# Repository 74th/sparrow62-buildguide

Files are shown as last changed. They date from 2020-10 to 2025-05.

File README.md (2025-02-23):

# Sparrow Series DIY Keyboard Kit Build Guide

Sparrow シリーズ自作キーボードキットビルドガイド

- Sparrow62 v1: [./sparrow62_v1.md](./sparrow62_v1.md) 分割型カラムスタッカードキーボード
- Sparrow62 v2: [./sparrow62_v2.md](./sparrow62_v2.md) 分割型カラムスタッカードキーボード(2023)
- Sparrow60C: [./Sparrow60c.md](./Sparrow60c.md) ジョイスティックモジュール StickPointV 搭載、GH60 互換ケース用 60% 格子配列キーボード
- SparrowDial: [./SparrowDial.md](./SparrowDial.md) M5StackCore2、M5Dial をトラックパッド化する GH60 互換ケース用 60% 格子配列キーボード
- SparrowG24: [./SparrowG21.md](./SparrowG21.md) レバーレス GP2040 ゲームコントローラ。ジョイスティック付き。
- SparrowS v3: [./SparrowS_v3.md](./SparrowS_v3.md) 分割型カラムスタッカードキーボード(2025)

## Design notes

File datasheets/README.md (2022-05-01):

# データシート

- [v2.0.4 ~ 2.0.5 回路図 datasheets/sparrow62-v2.0.5-schematic.pdf](./sparrow62-v2.0.5-schematic.pdf)
- [v2.0.4 ~ 2.0.5 配線 datasheets/sparrow62-v2.0.5-pcb.pdf](./sparrow62-v2.0.5-pcb.pdf)

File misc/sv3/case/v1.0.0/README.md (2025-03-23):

# SparrowS v3 ケースデータ v1.0.0

- 左手ボディMX互換スイッチ用: [./left-case-main-mx.stl](./left-case-main-mx.stl)
- 左手ボディChoc互換スイッチ用: [./left-case-main-choc.stl](./left-case-main-choc.stl)
- 左手トップバー奥用: [./left-case-top-upper.stl](./left-case-top-upper.stl)
- 左手トップバー手前用: [./left-case-top-lower.stl](./left-case-top-lower.stl)
- 右手ボディMX互換スイッチ用: [./right-case-main-mx.stl](./right-case-main-mx.stl)
- 右手ボディChoc互換スイッチ用: [./right-case-main-choc.stl](./right-case-main-choc.stl)
- 右手トップバー奥用: [./right-case-top-upper.stl](./right-case-top-upper.stl)
- 右手トップバー手前用: [./right-case-top-lower.stl](./right-case-top-lower.stl)

下記のインサートナットを利用しています。

- 長さ 3mm, M2, 外形(OD) 3.2mm
  - https://ja.aliexpress.com/item/1005006262109427.html

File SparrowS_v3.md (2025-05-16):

# SparrowS v3 ビルドガイド

本記事中に、[右手追加4キーパッドの組み立て方法](#右手追加4キーパッドの使用方法)も記載があります。

## 販売先

- booth: https://74th.booth.pm/items/6655442

## SparrowS v3 の注意点

- 互換スイッチと、Chocスイッチに対応ですが、Chocスイッチを利用する場合、実装しては"いけない"部品があります（後の手順中でも説明します）。MX互換の場合でも、実装しなくても問題ありません。
  - 左手PCB:
    - CH9（上面の、TopPlateLEDと書かれたQwiicソケット）
  - 左手トッププレート:
    - 全て（キャパシタ C1、Qwiicソケット CH1、RGBLED D1）
- Qwiicソケットは実装が難しめの部品になります。実装しなくてもキーボードとして全ての機能を利用できます。実装に必要な機材がなかったり、実装に自信がない場合はひとまず実装せずに進めてください。
  - 左手PCB: CH9、CH10
  - 左手トッププレート: CH1
  - 右手PCB: CH3
  - 右手トッププレート: -
  - 推奨機材: フラックス、ブリッジをチェックするためのテスター
- ケースはMX互換スイッチとChocスイッチの使用時で異なるものを用意しています。対応ケースをご準備ください。MX互換スイッチ用ケースではChocスイッチでも使用可能ですが、高さが適切ではありません。
- 拡張用にI2C Qwiicソケットを搭載しています。しかし、現状販売中のケースは右手のみにしか対応しません。必要に応じて利用してください。

## SparrowS v3キーボードとは

SparrowS v3は@74thが頒布する自作キーボードキットです。

最初は Lily58 からインスピレーションを得て、数々の改良を加えました。

これは購入者がご自身で組み立てが必要なキットです。
完成を保証するものではありません。

本キーボードの前作はSparrow62(+1)v2です。左右分割（スプリット）タイプのキーボードシリーズとして、SparrowSと改名し、SparrowS v3となっています。

## SparrowS v3の特徴

- 左右分割で、方を開いてタイプできる
- 縦に揃ったキー配置（カラムスタッガード）であり、指の曲げ伸ばしで多くのキーに届くようになっている
- 右手のキーボードの右側にマウスなどを配置できるように、右手の右側のキーの数を抑え、左側が膨らむデザインである
- 右手のキーボードの左側にトラックパッドなどを配置できるように、右手の左側が削れている
- ガスケットマウントを採用し、打鍵感を和らげている
- CherryMX互換スイッチと、薄型のKailh Chocスイッチに対応
- スイッチソケットにより、スイッチの交換が可能
- 数字キーを網羅できるほどキーの数が多いこと（60%キーボード）。
- 標準的なキーキャップセットを利用して、組み立てが可能
- ゴム足の代わりに、ゴムシートを使うことで薄くしている

## キット同梱品

### ベースキット

- 左手用PCB x1
- 右手用PCB x1
- 左手用トッププレート x1
- 右手用トッププレート x1
- 左手用ケース（MXスイッチ用、Chocスイッチ用のどちらか） x1
- 左手用ケースヘッダーバー奥用 x1
- 左手用ケースヘッダーバー手前用 x1
- 右手用ケース（MXスイッチ用、Chocスイッチ用のどちらか） x1
- 右手用ケースヘッダーバー奥用 x1
- 右手用ケースヘッダーバー手前用 x1
- ダイオード 1N4148W x58
- SK6812-MINI-E x1
- TRRSソケット x2
- SMD 0603in 1608M 27Ω 抵抗 x1
- SMD 0603in 1608M 100nF コンデンサ x1
- SH1.0(Qwiic)ソケット x2
- SH1.0(Qwiic)ケーブル x1
- ガスケットマウントクッション x2.5
- M2 4mmネジ x19
- グリップクッション x4片

使用している市販品の購入先については、後述しております。

### 追加4キーパッド

- PCB x1
- トッププレート x1
- ケース x1
- M2 4mmネジ x5
- グリップクッション x1片
- Qwiic互換ケーブル x1

## 追加で必要なもの

### ベースキット

- スイッチソケット（以下のどちらか） x58
  - Cherry MX互換ソケット（Kailh製で確認済み）
    - 遊舎工房: https://shop.yushakobo.jp/products/a01ps
    - TALP KEYBOARD: https://talpkeyboard.net/items/5e02c5405b120c792616bcf9
  - Kailh Chocソケット
    - 遊舎工房: https://shop.yushakobo.jp/products/a01ps
    - TALP KEYBOARD: https://talpkeyboard.net/items/6365b6224ff8c216413a0c92
- スイッチ（以下の種類のもの） x58
  - Cherry MX互換スイッチ
  - Kailh Choc v1/v2スイッチ（Lofree x Kailh Shaddowシリーズも可）
- スイッチ対応キーキャップ一式（[『対応キーキャップ』の項目](#対応キーキャップ)を参照ください）
- TRRSケーブル x1
- USB-Cケーブル x1

### 追加4キーパッド

- スイッチ（以下の種類のもの） x3
  - Cherry MX互換スイッチ
  - Kailh Choc v1/v2スイッチ（Lofree x Kailh Shaddowシリーズも可）
- スイッチ対応キーキャップ 4種
  - MX互換スイッチの場合
    - 2U x1 - バックスペースキー
    - 2.25U x1 - Enterキー
    - 2.75U x1 - 左Shiftキー
    - 1.25U x1
  - Chocの場合
    - 1U x3
    - 1.25U x1 - 1Uでも可
- (MX互換スイッチのみ) 2U スタビライザー x3
- スイッチソケット（以下のどちらか） x4
  - Cherry MX互換ソケット（Kailh製で確認済み）
  - Kailh Chocソケット

### 使用可能なスタビライザー

(MX互換スイッチのみ) 2U スタビライザー x3が必要です。
自作キーボードで用いられるスタビライザーには、「プレートマウントスタビライザー」と「PCBマウントスタビライザー」があります。
「PCBマウントスタビライザー」を利用してください。

- 遊舎工房: [MXスイッチ スタビライザー https://shop.yushakobo.jp/products/a0500st](https://shop.yushakobo.jp/products/a0500st)
- TalpKeyboard: [DUROCK 2U V3 PCBマウントスタビライザー（スモーキー/ゴールド） https://talpkeyboard.net/items/66793a80b90fcc082dad12f2](https://talpkeyboard.net/items/66793a80b90fcc082dad12f2)

Chocの場合にはスタビライザーは使用できません。

### 追加4キーパッドを利用する場合

## 対応キーキャップ

以下のセットを含むキーキャップを利用してください。

### CherryMX互換スイッチを使う場合

以下の画像中の`1.5u`の表記を参考に、サイズの合うキーキャップを利用してください。（右手の左側4キーは追加4キーパッドのものです）

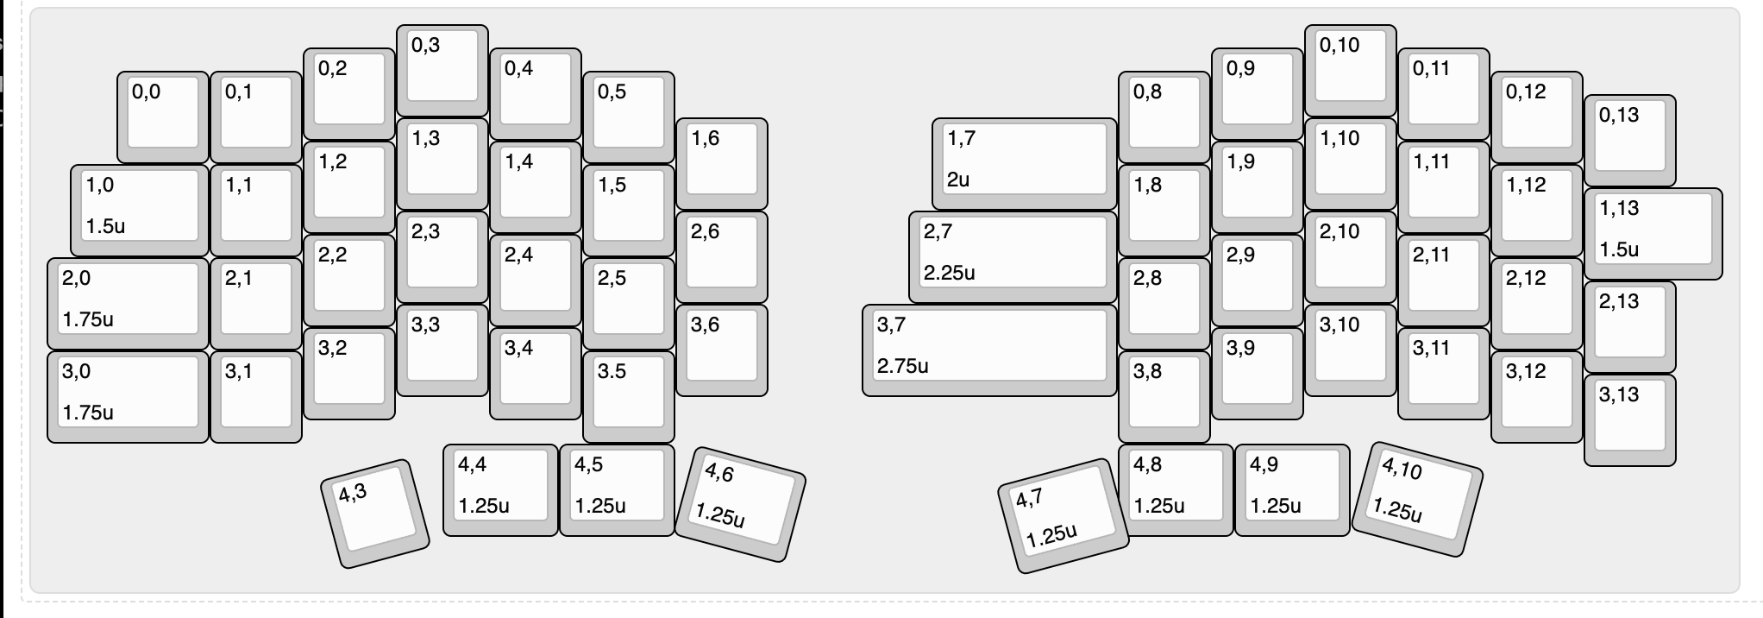
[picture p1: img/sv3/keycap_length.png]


主に、以下の点に注意してください。

- 最下段の1.25uが6つあること
- 左手シフト用に1.75uのShiftがあること

### Kailh Chocスイッチを使う場合

以下の点に注意してください。

- 左手の左端、および右手の右端はすべて1uを使います
- 右手の追加4キーパッドも1uを使うように設計されています
- 最下段には1.25uが6つあります

## 実装手順

### 1. ダイオードの実装

ダイオードの実装は以下のページをみてください。

[ダイオード1N4148Wの実装方法 ./diode_1n4148w.md](./diode_1n4148w.md)

### 2. スイッチソケットの実装

スイッチソケットの実装は以下のページをみてください。

[スイッチソケットの実装方法 ./switch_socket.md](./switch_socket.md)

### 3. CherryMXソケットのみ、トッププレートLEDの実装

> [!Caution]
> Kailh Chocスイッチを使う場合はトッププレートLEDのための部品は実装してはいけません

CherryMX互換スイッチを使う場合のみ、この実装を行ってください。
Chocスイッチ利用時は、実装してしまうとスイッチが取り付けられなくなります。
トッププレートLEDがなくても、PCB中のLEDが見えるため問題ありません。

トッププレートと、PCBのQwiicソケットを実装します。

QwiicソケットをPCBにマスキングテープで固定します。

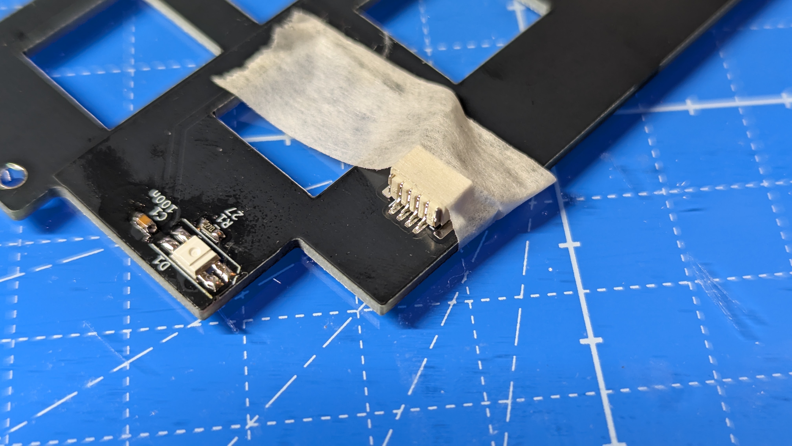
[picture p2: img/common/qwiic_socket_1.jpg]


固定した上で、ブリッジするのを気にせずに実装します。

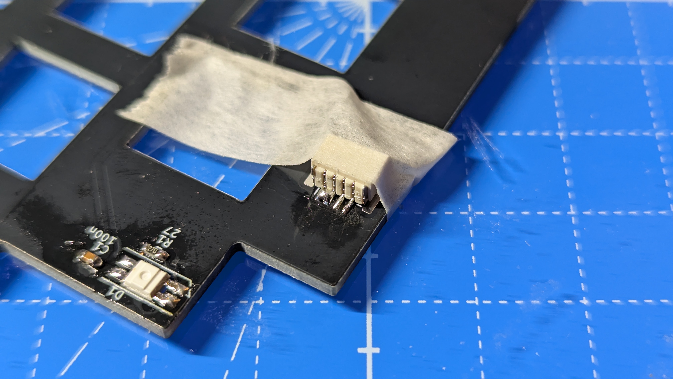
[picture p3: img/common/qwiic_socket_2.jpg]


フラックスを塗り、はんだごてを当ててブリッジした余分なはんだをはんだごてに移し、はんだごてを拭います。
これを繰り返し、余分なはんだを取り除きブリッジを除去します。

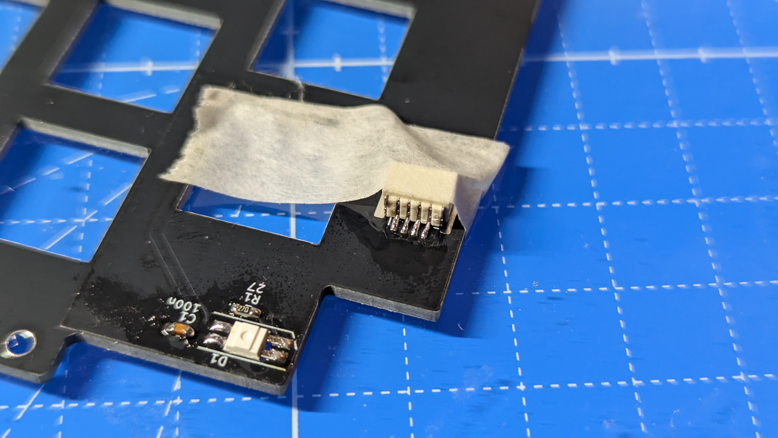
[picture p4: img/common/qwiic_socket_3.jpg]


次に本体固定のためのランドを実装します。
まず、PCB上のランドを温めて、はんだを流してください。
この時、無理にソケットの金属部分まで温めようとしなくて大丈夫です。

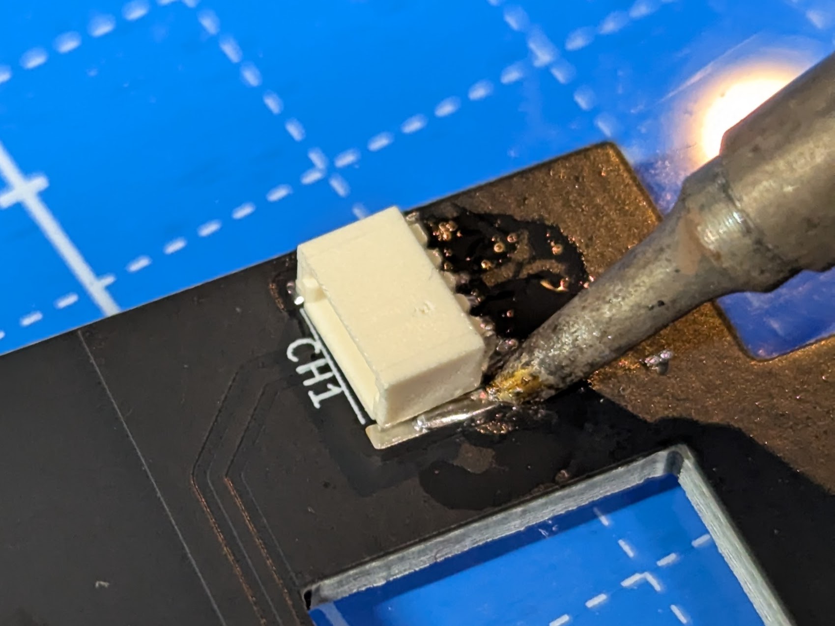
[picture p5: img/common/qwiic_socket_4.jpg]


次にソケットの金属部分を温めてください。
すると、次第に隣接しているランドに熱が伝わり、ソケットの金属部分にまではんだが流れ込み、はんだで溶接されます。

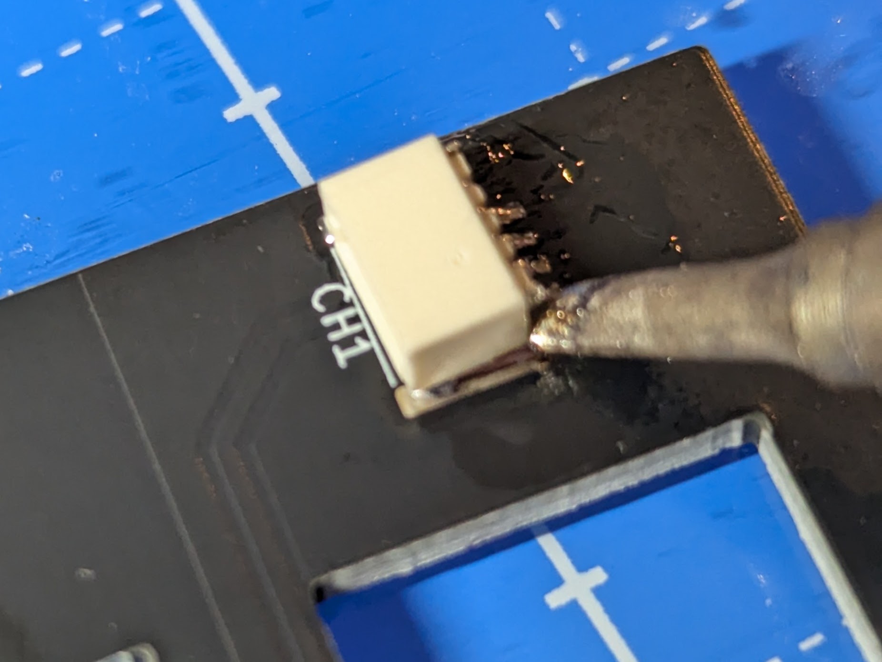
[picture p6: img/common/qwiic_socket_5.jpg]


次にSK6812-MINI-Eを実装します。
LED SK6812MINI-E の方向を注意してください。

LED の実装は、PCB裏面に裏向き（LEDのない面）にセットして実装します。
PCB 表向きから見ると、発光面が見える形になります。

また、LED の 4 本の足の 1 つ GND には切れ込みが入っています。切れ込みとシルクの斜め線を合わせるようにしてください。（写真はSparrow62v2(+1)のものです）

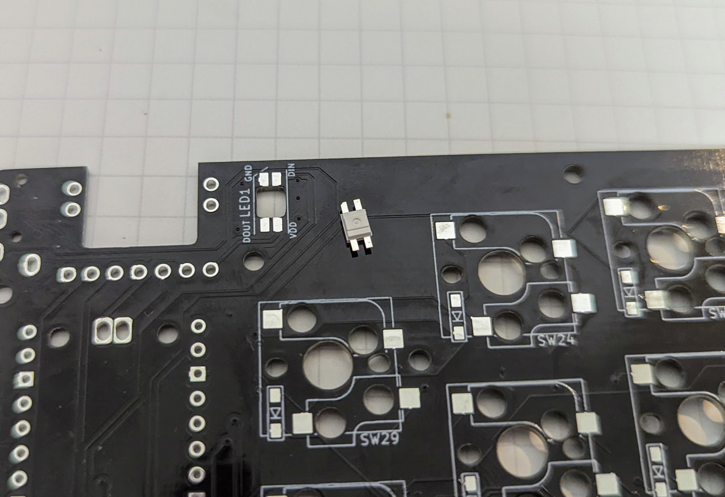
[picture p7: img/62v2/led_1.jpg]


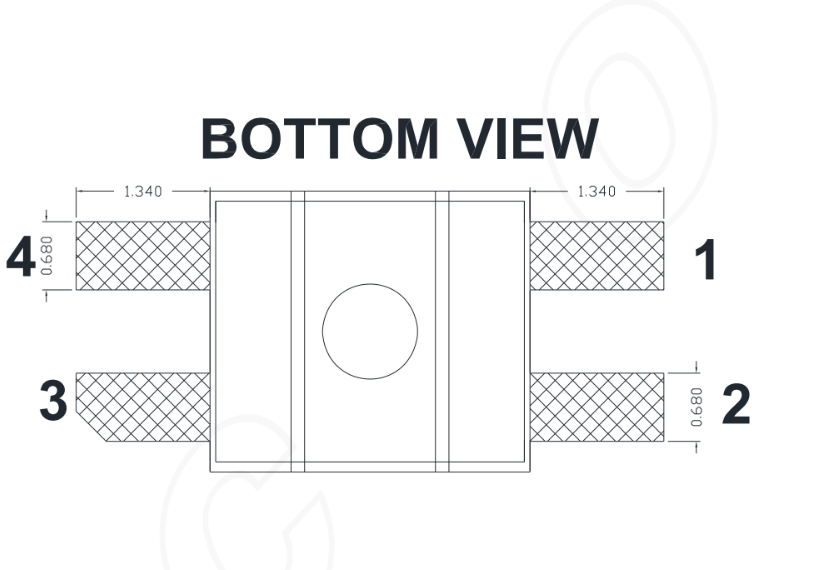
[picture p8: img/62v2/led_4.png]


向きを確認できたら、一方の足をマスキングテープで留めます。

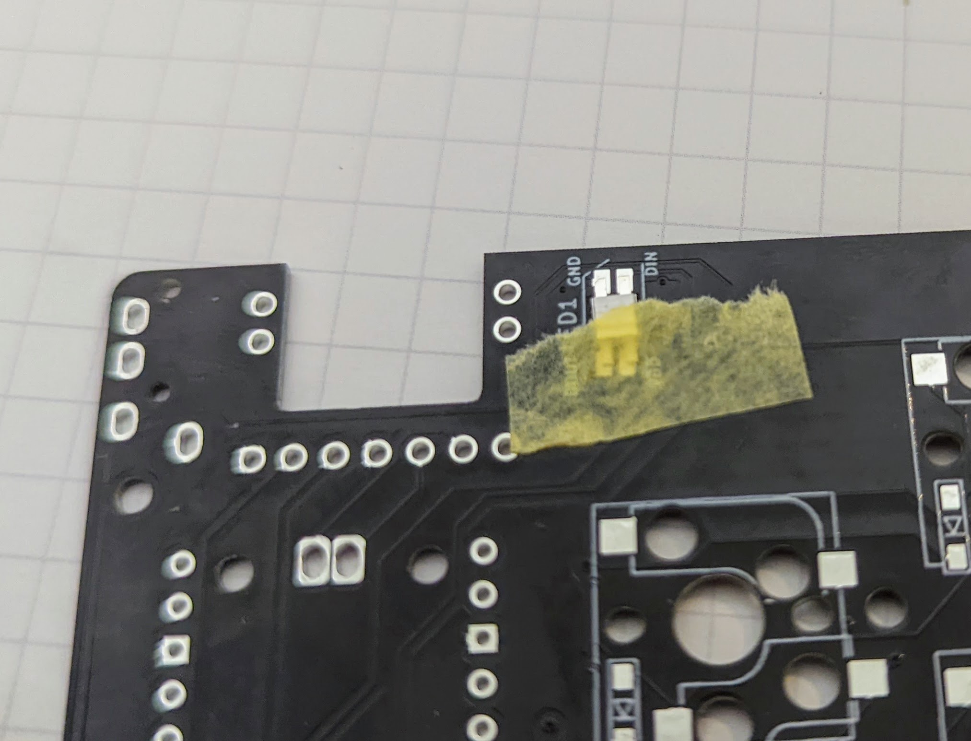
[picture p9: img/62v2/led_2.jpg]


すべての足を実装します。

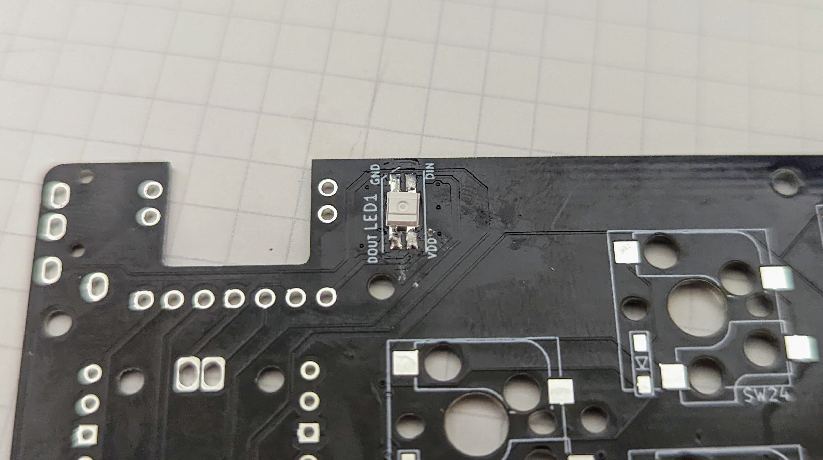
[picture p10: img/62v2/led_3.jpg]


C1に100nFコンデンサ、R1に27Ω抵抗を、ダイオードと同じように実装します。

### 4. TRRSソケットの実装

まず、TRRSソケットをPCB上にセットし、マスキングテープで固定します。

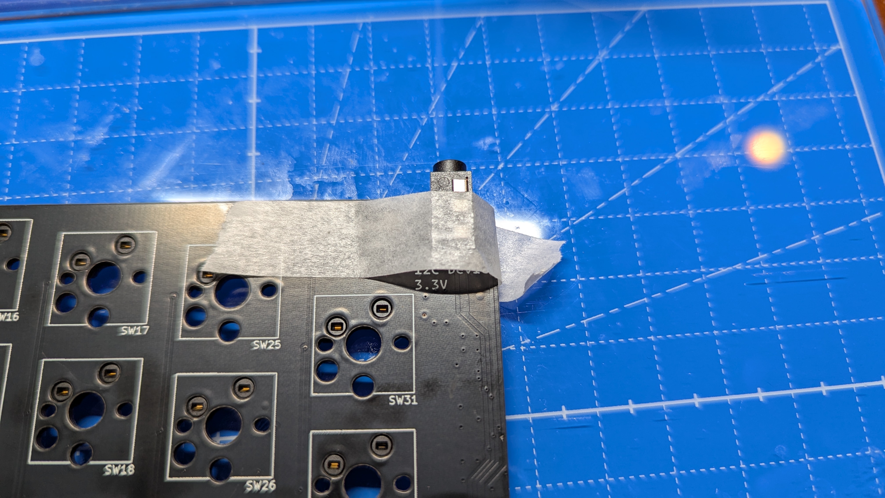
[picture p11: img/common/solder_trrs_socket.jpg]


裏返し、TRRSソケットのはみ出ている足をニッパで切ります。
それからはんだ実装してください。

### 5. スイッチの取り付けとここまでの実装確認

ここまでの実装を、確認しましょう。
ケースに入れる前に確認しましょう。

SparrowS v3には、Remapに対応したQMK Firmwareを予め書き込んであります。
PCとUSBで接続するとキーボードとして認識します。

PCBにトッププレートPCBを重ねて、トッププレート越しにスイッチを差し込みます。
トッププレートとPCBはネジ止めしません。

Chocスイッチ、MXスイッチにはプレートが挟まるツメがあります。
Chocスイッチの場合、トッププレートとPCBの間は以下の写真のように0.5mm程度になります。
スイッチのツメにしっかりはまるように取り付けてください。

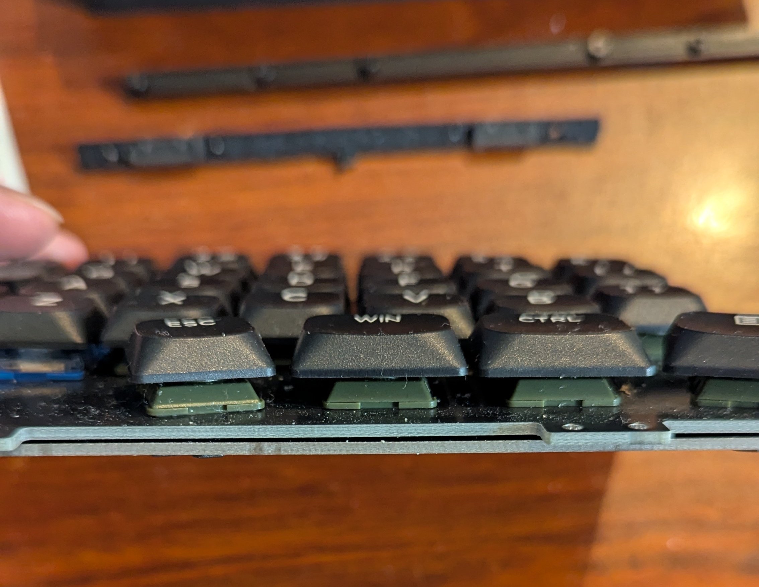
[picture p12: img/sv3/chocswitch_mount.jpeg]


MX互換スイッチには、トッププレートを挟み込む溝が付いています。この溝にトッププレートが挟まれるようにトッププレートを持ち上げてください。

TRRSソケットにケーブルを差し込み、接続します。

USBをPCに接続し、すべてのキーが動作するかを確認します。詳細は前述の「ケースへの組み込み前の実装確認」を確認ください。

各キーが動作することをRemapのTest Matrix modeを使って確認して下さい。

> RemapのTest Matrix modeを使ったキーマトリックスのテスト方法
>
> [./remap_test_matrix_mode.md](./remap_test_matrix_mode.md)

動作しないキーがある場合、一度すべてをケースから取り外し、該当キーのダイオードとスイッチソケットの実装をやり直します。

### 6. ケースのバリ取り

ケースは家庭用3Dプリンタで製造したものをキットに同梱しています。
プリムという印刷を安定化させる部分も含んだ状態で出荷しています。

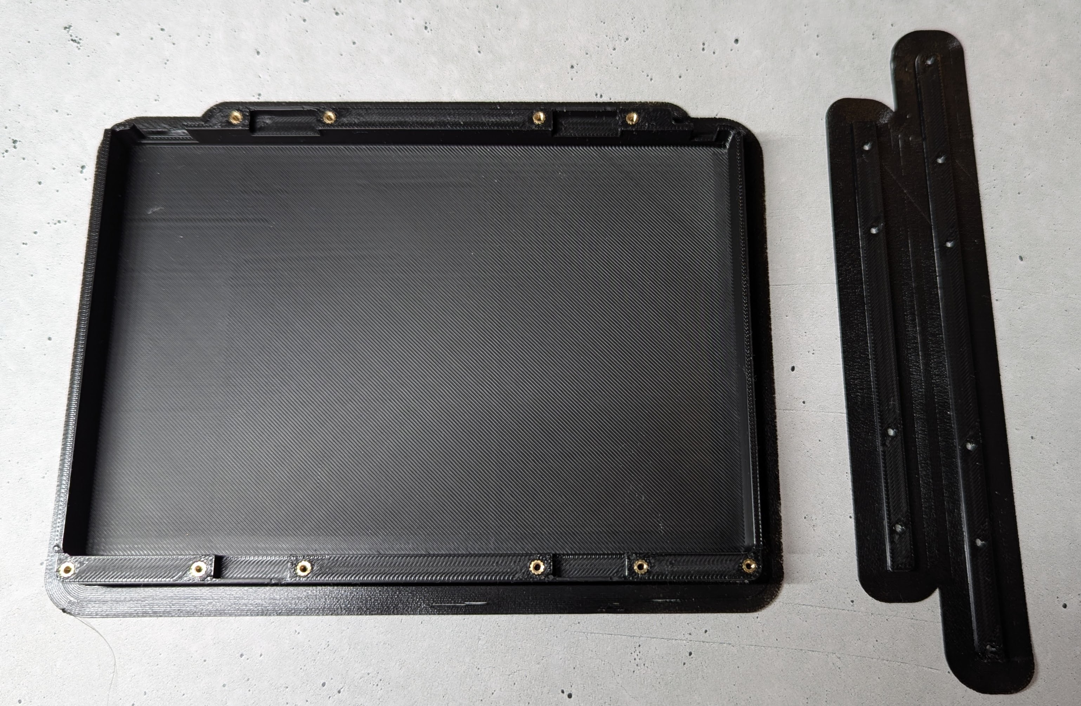
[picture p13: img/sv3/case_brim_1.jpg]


カッターナイフでブリムの部分を切り取ります。
カッターナイフとしては、デザインナイフを使うと、細くて使いやすいです。
怪我しないように気をつけてください。

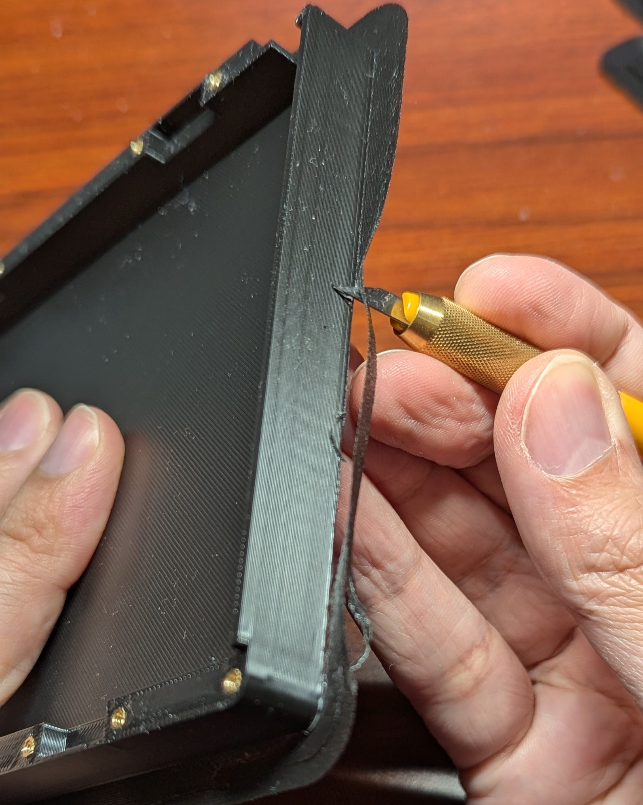
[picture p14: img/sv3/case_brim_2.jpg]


### 7. ガスケットクッションの取り付け

ガスケットマウントのクッションを、はさみで6つに切り分けます。

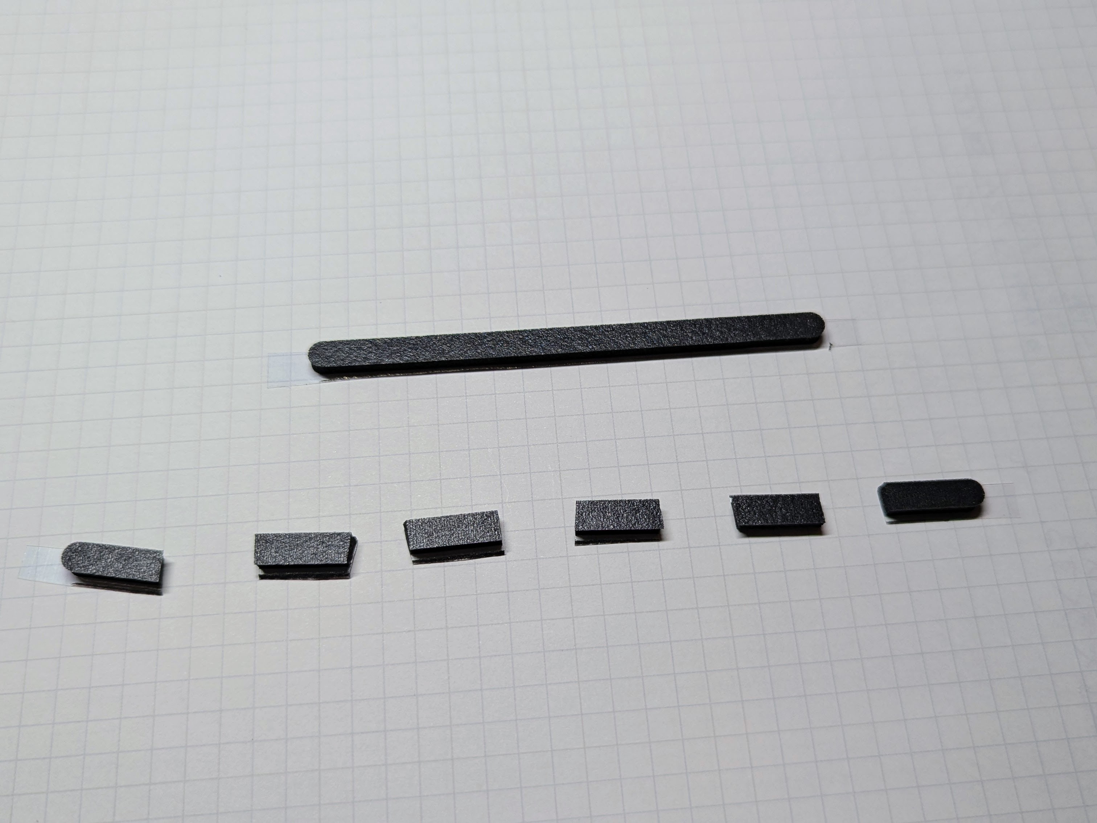
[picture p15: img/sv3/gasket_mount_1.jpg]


ケースと、ケースのバーに、クッションをそれぞれ取り付けます。

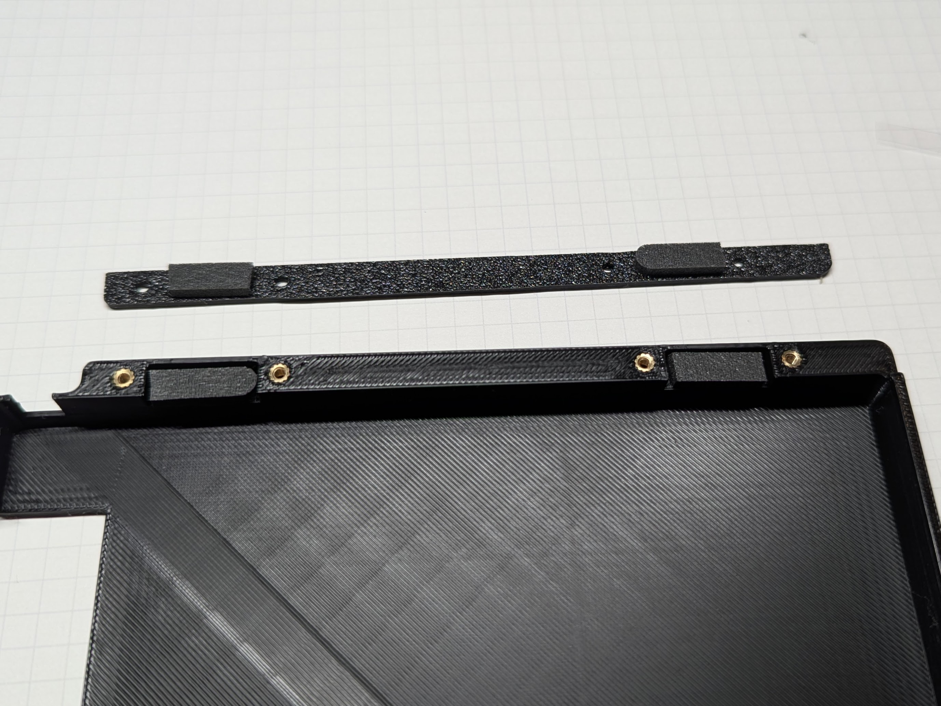
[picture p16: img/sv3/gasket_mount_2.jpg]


合計16箇所とりつけてください。

### 8. ネジ止め

キーボードPCBを入れて、ネジで留めます。

### 9. 底面のグリップゴムとりつけ

グリップゴムは4片付属しています。まず、こちらをはさみで半分に切ります。

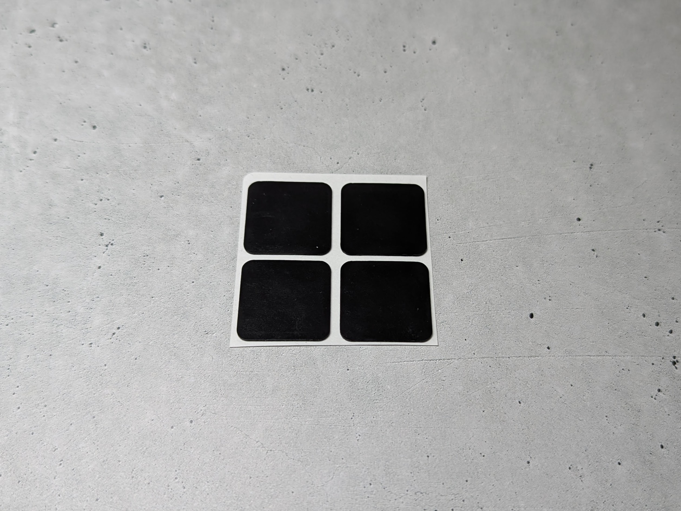
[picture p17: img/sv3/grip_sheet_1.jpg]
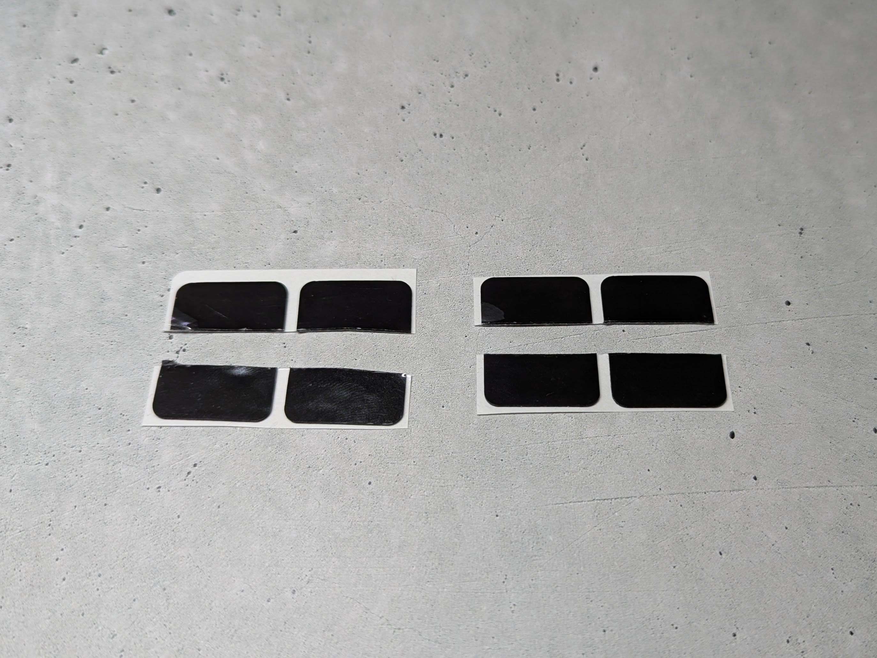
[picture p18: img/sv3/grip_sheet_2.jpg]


これをケースの底面の四隅に貼り付けます。

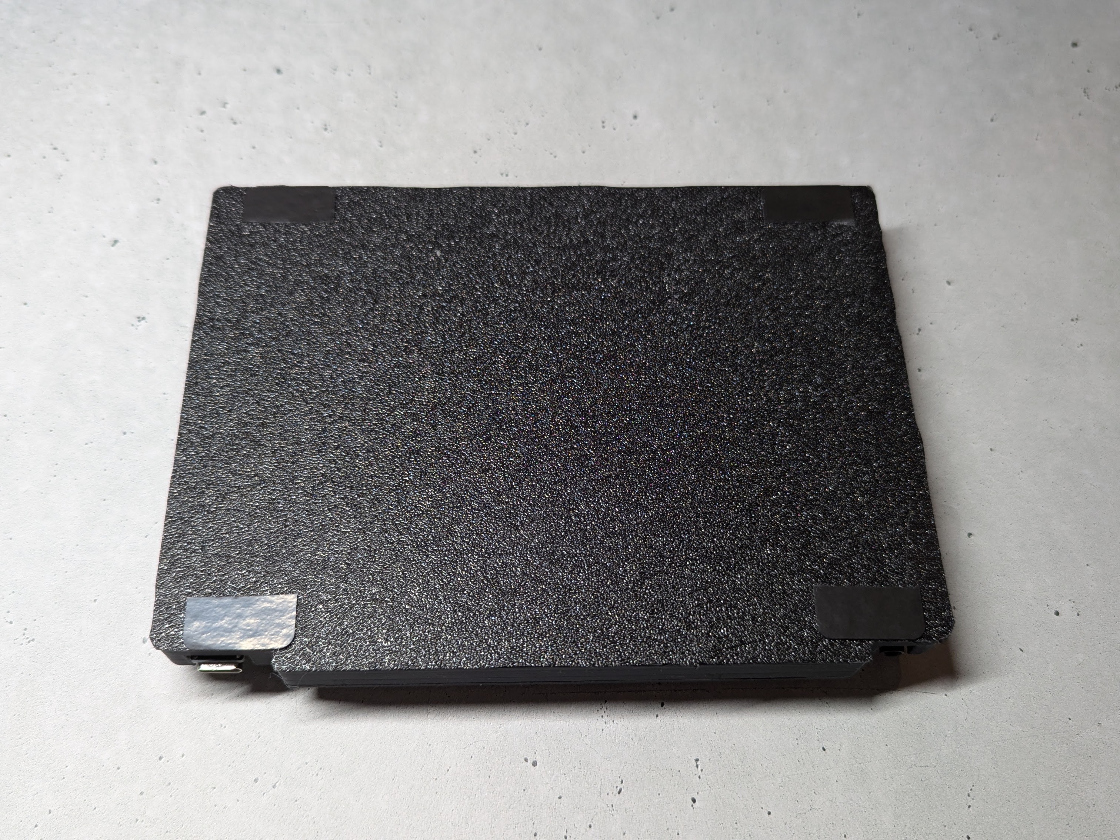
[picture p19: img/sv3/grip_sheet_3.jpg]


これで完成です！

## キーマップの変更、RP2040ファームウェアの更新

キーマップの変更には、2種類の方法があります。

- VIA、Remapを用いる
- QMK Firmwareでファームウェアをビルドする
- RP2040に対応したファームウェアを作成する

始めからVIA、Remap用のファームウェアが書き込まれた状態になっています。Remapを用いる場合には特にこの工程をする必要はありません。

VIA、Remapを利用しない利用しない場合は、別途ファームウェアを用意してください。RP2040はBOOTSELボタンを押しながらRESETを行うと、USBマスストレージデバイスがPCに認識され、その中にuf2ファイルをドラッグドロップすることで、ファームウェアを書き込むことができます。

### VIA、Remapを利用する場合

VIA、RemapはWebサイトや、ツール上からキーマップの書き換えができるサイトです。VIA対応のファームウェアをRP2040にアップロードすると、利用できるようになります。最初からRemap用のファームウェアが書き込まれた状態で出荷しています。

- Remap https://remap-keys.app/
- VIA https://caniusevia.com/

ファームウェアは以下からダウンロードできます。

> [!IMPORTANT]
> 追加4キーパッド対応版は、追加4キーパッドを使用する場合のみ書き込んでください

- VIA、Remap 用ファームウェア 通常版 [./firmware/sv3/qmk_firmware-sparrows_v3-via.uf2](https://github.com/74th/sparrow62-buildguide/raw/refs/heads/master/firmware/sv3/qmk_firmware-sparrows_v3-via.uf2)
- VIA、Remap 用ファームウェア 右手追加4キーパッド対応版 [./firmware/sv3/qmk_firmware-sparrows_v3_with_4keyspad-via.uf2](https://github.com/74th/sparrow62-buildguide/raw/refs/heads/master/firmware/sv3/qmk_firmware-sparrows_v3_with_4keyspad-via.uf2)

書き込みを行う領域の都合上、新たにVIA、REMAPのファームウェアをインストールしても、以前変更したキーマップの変更が残っている場合があります。その時には、[公式サイトのResetting Flash memory](https://www.raspberrypi.com/documentation/microcontrollers/raspberry-pi-pico.html#resetting-flash-memory)にあるUF2ファイル(flash_nuke.uf2)を一度インストールして、FLASHの全消去を行ってください。

また、書き込み直後は右手や、追加4キーが動作しない場合があります。一度USBを抜き差しして電源をリセットさせてください。

初期キーマップはRemapの画面もしくは、QMK Firmware上の以下のコードを確認ください。

[https://github.com/74th/qmk_firmware_sparrow_keyboard/blob/sparrow/keyboards/sparrow62/rev3/keymaps/via/keymap.c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](https://github.com/74th/qmk_firmware_sparrow_keyboard/blob/sparrow/keyboards/sparrow62/rev3/keymaps/via/keymap.c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)

### QMK Firmwareでファームウェアをビルドする場合

現在、SparrowDialキーボードはQMK Firmwareの本体には取り込まれていません。下記リポジトリに作成したファームウェアのコードがあります。
SparrowSという名前ですが、Sparrow62からのバージョン3であるため、[keyboards/sparrow62/rev3](https://github.com/74th/qmk_firmware_sparrow_keyboard/tree/sparrow/keyboards/sparrow62/rev3)というディレクトリ構成になっています。

- リポジトリ: https://github.com/74th/qmk_firmware_sparrow_keyboard
- キーボードディレクトリ: https://github.com/74th/qmk_firmware_sparrow_keyboard/tree/sparrow/keyboards/sparrow62/rev3

QMK Firmwareの環境のセットアップについては[公式のドキュメント https://docs.qmk.fm/#/newbs_getting_started](https://docs.qmk.fm/#/newbs_getting_started)を確認ください。[日本語のドキュメント https://docs.qmk.fm/#/ja/newbs_getting_started](https://docs.qmk.fm/#/ja/newbs_getting_started)もあります

まず、リポジトリをチェックアウトしてください。QMK Firmwareのフォークとなっているため、QMK Firmwareのセットアップでチェックアウトされたgitリポジトリのremoteとして登録できます。

```sh
cd ~/qmk_firmware
git remote add sparrow https://github.com/74th/qmk_firmware_sparrow_keyboard.git
git fetch sparrow
git checkout sparrow
```

このリポジトリ上では、キーボード名`sparrow62/rev3`として登録されています。新しいキーマップを作成するには以下を実行します。

```
qmk new-keymap -kb sparrow62/rev3 -km <keymap_name>
```

`~/qmk_firmware/keyboards/sparrowdial/keymaps/<keymap_name>`というフォルダに作成されるため、キーマップを作成します。

右手追加4キーを利用する場合には、`~/ghq/github.com/qmk/qmk_firmware/keyboards/sparrow62/rev3/config.h`を開き、`USE_RIGHT_4KEYS`の値を`1`に設定します。

```
// 右手左側の追加4キーオプション使用時は1にする
#define USE_RIGHT_4KEYS 1
```

キーマップ作成後は、以下のコマンドでコンパイルします。

```
qmk compile -kb sparrow62/rev3 -km <keymap_name>
```

すると、`~/qmk_firmware/.build/sparrows_rev3_<keymap_name>.uf2`にビルドされるため、これをRP2040に書き込みます。

RP2040に書き込むには、BOOTSELモードでRP2040を起動する必要があります。
左手PCBのUSBを「BOOT」ボタンを押しながらPCに接続するか、PCに接続済みの場合「BOOT」ボタンを押しながら「RESET」ボタンを押してください。
PC上にRPI-RP2という名前のUSBドライブが認識します。
その中に .uf2 ファイルをドラッグドロップしてください。
ファイルが入ると、自動的にUSBドライブのマウントが解除され、RP2040が再起動します。

## 右手追加4キーパッドの使用方法

右手に4キーを追加するモジュールを作成しております。
こちらを、右手のQwiicソケット（SH1.0-4P）に、Qwiicケーブル（キットには互換ケーブルを付属）を接続して、右手に4キーを増設することができます。

### キット同梱品

[前述の『キット同梱品』を確認ください。](#追加4キーパッド)

### キットの他に必要な物

[前述の『キットの他に必要なもの』を確認ください。](#追加4キーパッド-1)

### 組み立て

まずスイッチソケットを実装してください。
スイッチソケットの実装は以下のページをみてください。

[スイッチソケットの実装方法 ./switch_socket.md](./switch_socket.md)

グリップクッションをはさみで4分割し、ケースの底面の4隅にグリップクッションを貼り付けてください。

組み立てには以下の順に行ってください。

#### 1. CherryMX互換の場合、PCBにスタビライザーを取り付ける

スタビライザーをPCBに取り付けます。
スタビライザーには、手前奥の方向があります。
一般的なスタビライザーはバーが手前になるように取り付けます。

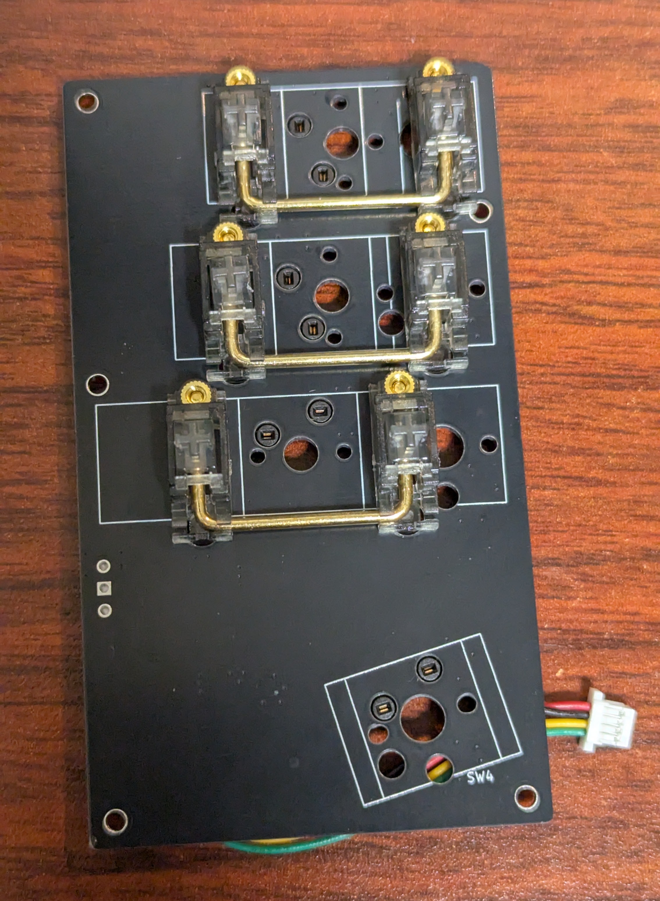
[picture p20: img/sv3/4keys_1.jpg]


横から眺めて、スタビライザーが確実に接地していることを確認してください。
ネジ止めするタイプのスタビライザーの場合、少し浮いている状態でも取り付けられることがありますが、キーキャップが嵌まらなかったり、嵌まったとしても正しく押下できないことがあります。

#### 2. Qwiicソケットにケーブルを接続

QwiicソケットにQwiic(SH1.0-4P)ケーブルを接続してください。
本キットには互換ケーブルが付属しています。

右手キーボードへ取り付ける時に、ケーブルが邪魔にならないように、以下の写真の程度の長さになるようにマスキングテープなどで留めておきましょう。

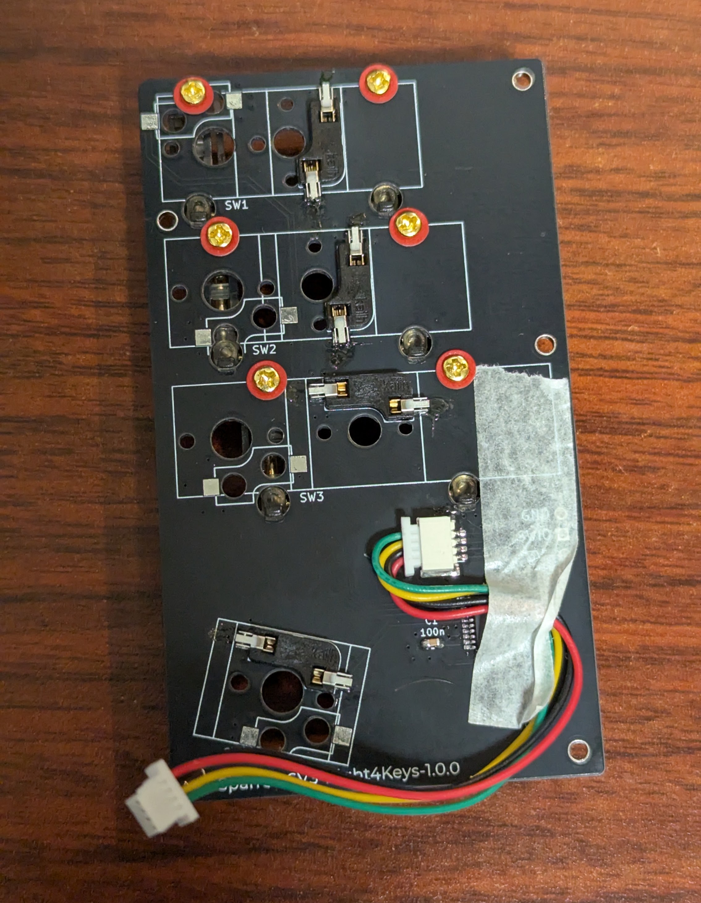
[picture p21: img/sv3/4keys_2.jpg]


#### 3. ケースにPCBをネジ止めする

ケースにPCBをセットし、ネジ止めします。
CherryMX互換スイッチの場合、スタビライザーのスペース上、ネジ1つを留められない場合があります。

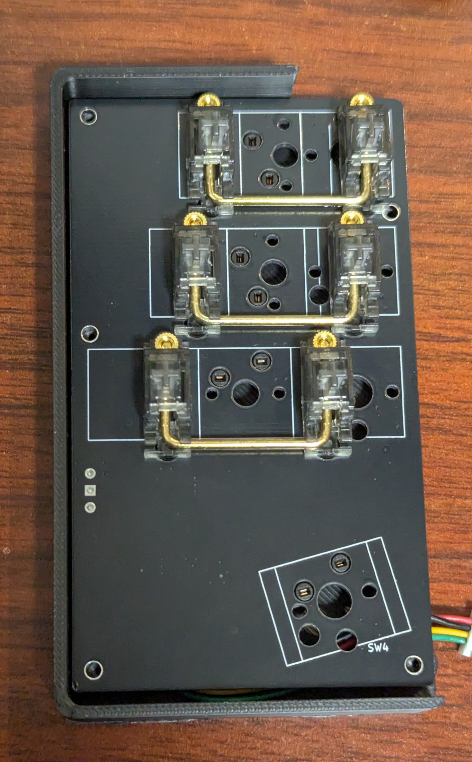
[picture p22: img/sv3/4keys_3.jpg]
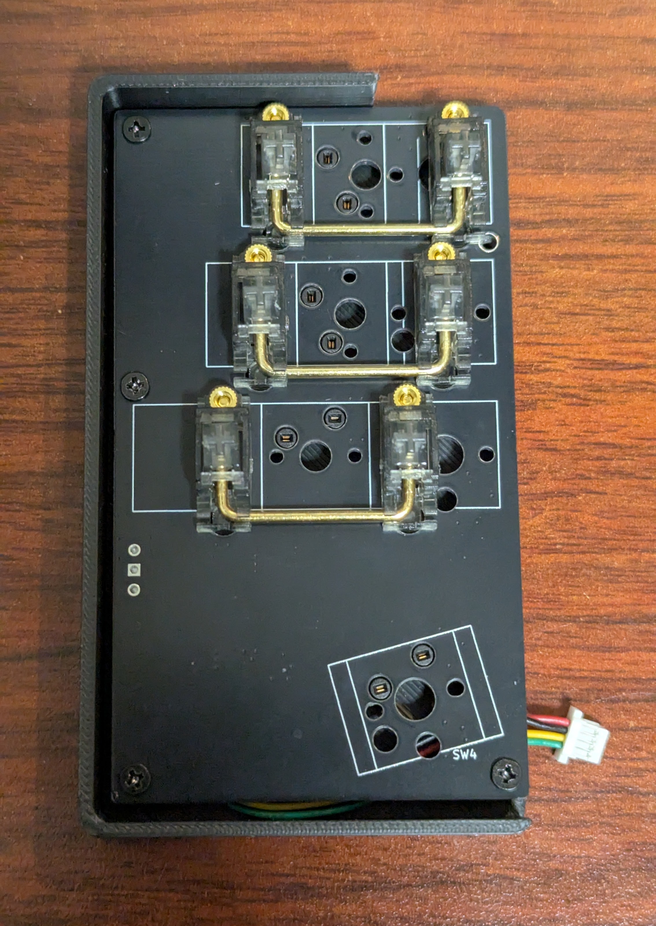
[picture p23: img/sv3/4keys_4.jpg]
 

#### 4. トッププレートを重ねる

トッププレートを重ねます。
スタビライザーを利用する場合は、スタビライザーの形に合うように穴が開けられているため、適切にセットしてください。

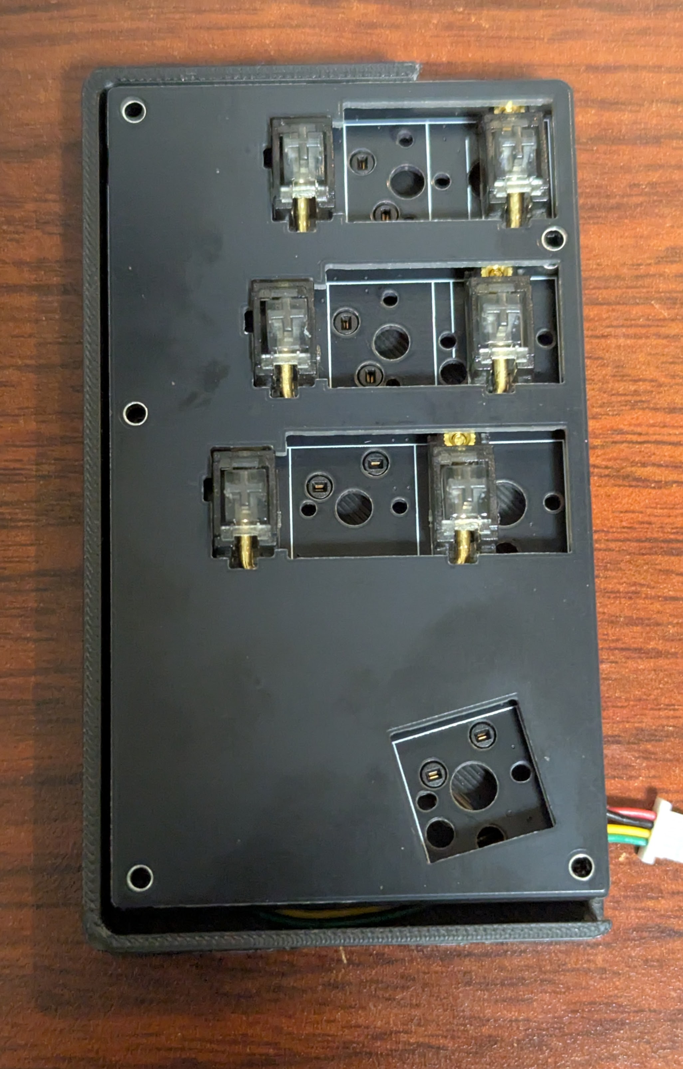
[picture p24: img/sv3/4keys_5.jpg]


#### 5. スイッチとキーキャップを取り付ける

スイッチとキーキャップを取り付けてください。

#### 6. 右手キーボードに接続する

右手キーボードの横のソケットにQwiicケーブルを接続してください。

#### 7. 動作確認

4キーパッドを利用する場合には、4キーパッドを有効化したファームウェアが必要です。

くわしくは、本記事中の[キーマップの変更、RP2040ファームウェアの更新](#キーマップの変更rp2040ファームウェアの更新)を参照してください。

## トラブルシューティング

こちらのページを確認ください。

> Trouble Shooting Guide
>
> [./trouble_shooting_guide.md](./trouble_shooting_guide.md)

## 右手用キーボード、追加4キーパッドのファームウェア

右手用キーボード、追加4キーパッドには、MCU CH32V003が搭載されています。
そのファームウェアはch32funを用いて実装しています。
ファームウェアは頒布したキットには既に書き込まれているため、変更は必要ありません。

このファームウェアのコードに関しては以下のリポジトリで公開しております。
変更の必要がある場合などには参照ください。

> 右手用キーボード<br/>https://github.com/74th/sparrow-keyboard-sub-firmware/tree/main/SparrowSV3-Right

> 追加4キーパッド<br/>https://github.com/74th/sparrow-keyboard-sub-firmware/tree/main/SparrowSV3-4Keys

## 同梱済みの部品の購入先

- ケース
  - [Boothショップ https://74th.booth.pm/items/6655442](https://74th.booth.pm/items/6655442)
  - [ケースデータ ./misc/sv3/case/v1.0.0/](./misc/sv3/case/v1.0.0/)
- Qwiicソケット（SH1.0-4P）
  - 千石電商 [https://www.sengoku.co.jp/mod/sgk_cart/detail.php?code=EEHD-0KNJ](https://www.sengoku.co.jp/mod/sgk_cart/detail.php?code=EEHD-0KNJ)
- RGB LED（SK6812-MINI-E）
  - 遊舎工房 [https://shop.yushakobo.jp/products/sk6812mini-e-10](https://shop.yushakobo.jp/products/sk6812mini-e-10)
  - など
- 抵抗 0603in 1608M SMD（ご連絡いただければ、送料のみでお譲りします）
  - マルツオンライン [https://www.marutsu.co.jp/pc/i/856811/](https://www.marutsu.co.jp/pc/i/856811/)
- コンデンサ 0603in 1608M SMD（ご連絡いただければ、送料のみでお譲りします）
  - マルツオンライン [https://www.marutsu.co.jp/pc/i/2353831/](https://www.marutsu.co.jp/pc/i/2353831/)
- ガスケットマウントクッション
  - Kelowna机械键盘gasket胶条结构垫片进口le-20背胶泡棉垫片
    - Aliexpress [https://ja.aliexpress.com/item/1005003264458903.html](https://ja.aliexpress.com/item/1005003264458903.html)
    - TaoBao [https://item.taobao.com/item.htm?id=651429257414](https://item.taobao.com/item.htm?id=651429257414)
- 底面グリップクッション
  - GRIPLUS（グリップラス） 極薄・強力 滑り止めシール 楽器用 スクエア ブラック [https://www.amazon.co.jp/gp/product/B0C2BCX287/](https://www.amazon.co.jp/gp/product/B0C2BCX287/)
- M2 4mm ネジ
  - SNZF 精密機器用十字穴付き皿小ねじ(微細ねじ)
    - モノタロウ [https://www.monotaro.com/p/4926/2744/](https://www.monotaro.com/p/4926/2744/)
  - (同梱品購入先) Taobao [https://detail.tmall.com/item.htm?id=589111930409](https://detail.tmall.com/item.htm?id=589111930409)
  - など
- Qwiicケーブル
  - Qwiicケーブル（50mm）（スイッチサイエンス） [https://www.switch-science.com/products/3542](https://www.switch-science.com/products/3542)
  - 汎用SH1.0ケーブルを利用する場合、必ず「Reverse Side」や「反向」と書かれている物を購入してください。
  - SH1.0 4P Reverse Side 10cm（aliexpress）[https://ja.aliexpress.com/item/1005006171950032.html](https://ja.aliexpress.com/item/1005006171950032.html)
  - (同梱品購入先) Taobao [https://item.taobao.com/item.htm?id=613425378650](https://item.taobao.com/item.htm?id=613425378650)
- インサートナット 長さ 3mm, M2, 外形(OD) 3.2mm
  - https://ja.aliexpress.com/item/1005006262109427.html

## Data Sheet

- [SparrowSV3 Left PCB v3.0.2 Semantics](datasheets/SparrowSV3-left-3.0.2-semantics.pdf)
- [SparrowSV3 Left PCB v3.0.2 PCB](datasheets/SparrowSV3-left-3.0.2-pcb.pdf)
- [SparrowSV3 Right PCB v3.0.2 Semantics](datasheets/SparrowSV3-right-3.0.2-semantics.pdf)
- [SparrowSV3 Right PCB v3.0.2 PCB](datasheets/SparrowSV3-right-3.0.2-pcb.pdf)
- [SparrowSV3 Left Top Plate v3.0.2 Semantics](datasheets/SparrowSV3-left-top-3.0.2-semantics.pdf)
- [SparrowSV3 Left Top Plate v3.0.2 PCB](datasheets/SparrowSV3-left-top-3.0.2-pcb.pdf)
- [SparrowSV3 Right Top Plate v3.0.2 Semantics](datasheets/SparrowSV3-right-top-3.0.2-semantics.pdf)
- [SparrowSV3 Right Top Plate v3.0.2 PCB](datasheets/SparrowSV3-right-top-3.0.2-pcb.pdf)

## その他

- ケースデータ [./misc/sv3/case/v1.0.0/](./misc/sv3/case/v1.0.0/)

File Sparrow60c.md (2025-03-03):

# Sparrow60C Keyboard Kit Build Guide

このビルドガイドには他のキーボードの写真が含まれていますのでご注意ください。

また、作成中に疑問点等質問がありましたら、74th （twitter: [@74th](https://twitter.com/74th) 、email: site@74th.tech 、 本リポジトリの issue）まで問い合わせください。

## 販売先

- booth(準備中)

## Sparrow60C の注意点

- マイコン RP2040 が直接 PCB に実装されています。
- GH60 互換キーボードケース対応の PCB ですが、必ずしもすべてのケースに対応するわけではありません。
- キットの PCB には RP2040 を動作させるためのマイコン及び受動部品が実装されています。

## キットの内容

- Sparrow60C PCB x1
- Sparrow60C Top Plate (FR4 PCB) x1
- ジョイスティックモジュール StickPointV x1
- HY2.0-4P(Grove) ケーブル x1
- ダイオード 1N4148W x60
- RGBLED SK6812-MINI-E x1
- HY2.0-4P(Grove) SMD ソケット x1
- M2 4mm スペーサー x4 : StickPointV、PCB間
- M2 4mm 黒 平ネジ x14 : ケースとPCBの間のネジ止め、StickPointVとPCBのスペーサーとのネジ止め

### PCB に実装済みの部品

- マイコン RP2040 x1
- マイコンプログラム用フラッシュ W25Q32JVS x1
- RP2040 の動作に必要な受動部品（コンデンサ、抵抗、水晶発振器）
- 6x6mm SMD タクタイルスイッチ（RP2040 RESET、BOOTSEL用） x2
- 電源保護用理想ダイオード CH213K x1
- USB Type-C コネクタ x1

## キットの組み立てに必要なもの

### キットの他に必要なもの

- [GH60 互換キーボードケース x1](./parts.md#gh60互換ケース)
- [MX 互換スイッチソケット x60](./parts.md#cherrymx互換スイッチソケットkailhスイッチソケット)
- [MX 互換スイッチ x60](./parts.md#cherrymx互換スイッチ)
- [MX 互換スイッチ用キーキャップ一式 x1](./parts.md#cherrymx互換キーキャップ)
- PC 接続用 USB Type-C ケーブル x1

### 組み立てに必要な機材

- はんだごて、はんだこて台、スポンジ
- はんだ
- ピンセット（表面実装部品を抑えるのに利用します）
- PC（Windows、Linux、MacOS の動作するもの。ファームウェアの作成に必要。）

### あるとよいもの

- フラックス
  - はんだにはフラックスが含まれていて、端子に広がるようにできていますが、熱を加えすぎるとすべてのフラックスが蒸発します。その場合、追加のフラックスを入れて使います
- フラックス洗浄液
- ルーペ（スマートフォンカメラでも代用できます）
- ラジオペンチ（ネジ止めの他、スイッチの足が曲がってしまった場合に、つまんで伸ばします）

## how to build / 作成方法

### Solder Diodes / ダイオードのはんだ付け

Solder the diode, paying attention to the orientation of the diode.
🇯🇵 ダイオードを向きを気をつけて、はんだ付けします。



The video by @Salicylic_acid3 is very good, so I think you can check here.
🇯🇵 実装手順については、サリチル酸さんのツイートの動画が非常に良くできているため、こちらを確認いただくと良いと思います。

https://twitter.com/Salicylic_acid3/status/1296494976319315970
https://twitter.com/Salicylic_acid3/status/1108798243142434816

Solder one side of the PCB first.
🇯🇵 先に PCB の片側にはんだをつけます。



Melt the solder you have applied and solder one side of the diode.
🇯🇵 つけたハンダを溶かして、ダイオードを片側をはんだ付けします。



First, solder all the diodes **only one side**.
Once one side is soldered, check that all diodes are facing the same way.
🇯🇵 まず、すべてのダイオードを**片側だけ**はんだ付けをしましょう。
片側のはんだ付けが済んだところで、一度すべてのダイオードが同じ向きを向いているか確認します。



Once you have checked and it is ok, solder the other leg as well.
🇯🇵 確認が済んで大丈夫であれば、反対側の足もはんだ付けします。



### Soldering the switch socket / スイッチソケットを実装する

We recommend soldering the socket as shown in the video.
🇯🇵 ソケットのはんだ付けは動画のようにすることをおすすめしています。

[Movie（Google Drive）](https://drive.google.com/file/d/1VQYtKHCZkTQwoi6JiOMwTrHwYhy1caux/view?usp=sharing)

[Movie（Twitter）](https://twitter.com/74th/status/1514942328900775938)

[Movie file switch_socket.mp4](./img/62v2/switch_socket.mp4)

1. Set the socket in the correct orientation.
2. Apply heat with a soldering iron from the inside of the socket's terminals.
3. From the outside of the socket, apply solder with the soldering iron and pour the solder into the socket.
4. Remove the solder and hold the socket with tweezers.
5. remove the soldering iron

🇯🇵

1. ソケットを正しい方向にセットします。
2. ソケットの端子の内側から、はんだごてで熱を加えます
3. ソケットの外側から、はんだごてを当ててはんだを流し込みます
4. はんだを外してから、ピンセットなどでソケットを抑えます
5. はんだごてを抜きます

### RGBLED を実装する

RGBLED SK6812MINI-E の方向を注意してください。

RGBLED の実装は、PCB 裏面に裏向きにセットして実装します。
PCB 表向きから見ると、発光面が見える形になります。

また、RGBLED の 4 本の足の 1 つ GND には切れ込みが入っています。切れ込みとシルクの斜め線を合わせるようにしてください。



向きを確認できたら、一方の足をマスキングテープで留めます。



すべての足を実装します。



### Soldering Grove(HY2.0) sockets / Grove(HY2.0) ソケットの実装

Grove(HY2.0)ソケットを実装します。

まず、1本のピンのみを実装し、はんだごてを更にあてながらPCBのシルクの位置になるように調整します。その後、残りのピンも実装します。ケーブルを差し込む面にも下部に固定用の金属部分があるため、こちらも忘れずに実装します。



### ケースへの組み込み前の実装確認

ケースへの組み込むと、はんだ実装に不具合があっても、キーキャップ、スイッチ、ネジなどのすべてを外さないとPCBの実装面にはアクセスできません。なるべく、ケースに組み込む前に、一度はんだ実装不良がないか確認すると良いでしょう。

HY2.0(Grove)ケーブルで、PCBとStickPointVを接続してください。

USBをPCに接続します。出荷時点でキーボードとして動作するファームウェアが書き込まれています。

StickPointVを操作し、マウスカーソルが動作することを確認してください。

各キーが動作することをRemapのTest Matrix modeを使って確認して下さい。

> RemapのTest Matrix modeを使ったキーマトリックスのテスト方法
>
> [./remap_test_matrix_mode.md](./remap_test_matrix_mode.md)

### ケースへの組み込み

ケースへの組み込みは以下の手順で行います。

1. Sparrow60C PCBへHY2.0(Grove)ケーブルの接続
2. Sparrow60C PCBをケースに配置する
3. Sparrow60C PCBとケースのネジ止め
4. Sparrow60C Top PlateへのStickPointVの組み込み
5. スイッチの差し込み
6. キーの動作テスト
7. キーキャップの差し込み

#### 1. Sparrow60C PCBへHY2.0(Grove)ケーブルの接続

先にPCBにHY2.0(Grove)ケーブルを差し込み、中央のホールから抜き出します。



#### 2. Sparrow60C PCBをケースに配置する

ケースにPCBに重ねます。



#### 3. Sparrow60C PCBとケースのネジ止め

M2 4mm ネジで固定します。



#### 4. Sparrow60C Top PlateへのStickPointVの組み込み

Sparrow60C Top Plateに、StickPointVを中央の穴に、図のようにスペーサーとネジを使ってマウントします。



まず、スペーサーをトッププレートに取り付けます。



Sparrow60C Top Plateを、ケースに重ねます。Sparrow60Cは、PCBとTop Plate間の固定は、スイッチのみで行います。そして、StickPointVモジュールとHY2.0(Grove)ケーブルを接続します。



トッププレートにStickPointVをM2 4mmネジで固定します。方向を間違えないように気をつけてください。



#### 5. スイッチの差し込み

Sparrow60C Top Plateの穴から、Sparrow60C PCBに向かってスイッチを差し込みます。GH60互換ケースを利用している都合、以下のスイッチの一部は異なる向きを向いています。差し込み時に注意してください。



MX互換スイッチには、Top Plateを挟み込む溝が付いています。この溝にTop Plateが挟まれるようにTop Plateを持ち上げてください。

この時、ケースの外側のスイッチから順に接続していくと、高さをキープしやすくなります。



#### 6. キーの動作テスト

各キーが動作することをRemapのTest Matrix modeを使って確認して下さい。

> RemapのTest Matrix modeを使ったキーマトリックスのテスト方法
>
> [./remap_test_matrix_mode.md](./remap_test_matrix_mode.md)

#### 7. キーキャップの差し込み

すべてのキーが動作することを確認できたならば、キーキャップを付けて完成です！

## ジョイスティックの操作のチューニング

StickPointVのチューニングについては、StickPointVのファームウェアのリポジトリを確認ください。

https://github.com/74th/stickpoint-firmware

## キーマップの変更、RP2040ファームウェアの更新

キーマップの変更には、2種類の方法があります。

- VIA、Remapを用いる
- QMK Firmwareでファームウェアをビルドする
- RP2040に対応したファームウェアを作成する

始めからVIA、Remap用のファームウェアが書き込まれた状態になっています。Remapを用いる場合には特にこの工程をする必要はありません。

VIA、Remapを利用しない利用しない場合は、別途ファームウェアを用意してください。RP2040はBOOTSELボタンを押しながらRESETを行うと、USBマスストレージデバイスがPCに認識され、その中にuf2ファイルをドラッグドロップすることで、ファームウェアを書き込むことができます。

#### VIA、Remapを利用する場合

VIA、RemapはWebサイトや、ツール上からキーマップの書き換えができるサイトです。VIA対応のファームウェアをRP2040にアップロードすると、利用できるようになります。最初からRemap用のファームウェアが書き込まれた状態で出荷しています。

- Remap https://remap-keys.app/
- VIA https://caniusevia.com/

別のファームウェアを入れた場合に、再度VIA、Remapに戻す場合には、VIA、Remap用のファームウェアは以下からダウンロードできます。

- VIA、Remap 用ファームウェア [./firmware/60c/sparrow60c_via.uf2](https://github.com/74th/sparrow62-buildguide/raw/refs/heads/master/firmware/60c/sparrow60c_via.uf2)

書き込みを行う領域の都合上、新たにVIA、REMAPのファームウェアをインストールしても、以前変更したキーマップの変更が残っている場合があります。その時には、[公式サイトのResetting Flash memory](https://www.raspberrypi.com/documentation/microcontrollers/raspberry-pi-pico.html#resetting-flash-memory)にあるUF2ファイル(flash_nuke.uf2)を一度インストールして、FLASHの全消去を行ってください。

#### QMK Firmwareでファームウェアをビルドする場合

現在、Sparrow60CキーボードはQMK Firmwareの本体には取り込まれていません。下記リポジトリに作成したファームウェアのコードがあります。

https://github.com/74th/qmk_firmware_sparrow_keyboard

QMK Firmwareの環境のセットアップについては[公式のドキュメント https://docs.qmk.fm/#/newbs_getting_started](https://docs.qmk.fm/#/newbs_getting_started)を確認ください。[日本語のドキュメント https://docs.qmk.fm/#/ja/newbs_getting_started](https://docs.qmk.fm/#/ja/newbs_getting_started)もあります

まず、リポジトリをチェックアウトしてください。QMK Firmwareのフォークとなっているため、QMK Firmwareのセットアップでチェックアウトされたgitリポジトリのremoteとして登録できます。

```sh
cd ~/qmk_firmware
git remote add sparrow https://github.com/74th/qmk_firmware_sparrow_keyboard.git
git fetch sparrow
git checkout sparrow
```

このリポジトリ上では、キーボード名`sparrow60c`として登録されています。新しいキーマップを作成するには以下を実行します。

```
qmk new-keymap -kb sparrow60c -km <keymap_name>
```

`~/qmk_firmware/keyboards/sparrow60c/keymaps/<keymap_name>`というフォルダに作成されるため、キーマップを作成します。

キーマップ作成後は、以下のコマンドでコンパイルします。

```
qmk compile -kb sparrow60c -km <keymap_name>
```

すると、`~/qmk_firmware/.build/sparrowdial_<keymap_name>.uf2`にビルドされるため、これをRP2040に書き込みます。

## トラブルシューティング

こちらのページを確認ください。

> Trouble Shooting Guide
>
> [./trouble_shooting_guide.md](./trouble_shooting_guide.md)

## Data Sheet

- [Sparrow60C v1.3.1 Semantics](datasheets/Sparrow60C-v1.3.1-semantics.pdf)
- [Sparrow60C v1.3.1 PCB](datasheets/Sparrow60C-v1.3.1-pcb.pdf)

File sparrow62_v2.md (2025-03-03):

# Sparrow62 (+1) v2 Keyboard Building Guide

[If you build Sparrow 62 v1, please see v1 Buildguide](./v1.md). [Sparrow62 v1 のビルドガイドはこちら。](./v1.md)

このガイドには一部 Sparrow 62 v1 の写真が含まれていますので注意ください。







また、作成中に疑問点等質問がありましたら、74th （twitter: [@74th](https://twitter.com/74th) 、email: site@74th.tech 、 本リポジトリの issue）まで問い合わせください。

## 販売先

- 遊舎工房（委託） https://shop.yushakobo.jp/products/4295
- booth https://74th.booth.pm/items/3828479

## Sparrow62 v2 の注意点

- Sparrow62 という名前ですが、v2 は 63 キーです。
- v2.0.5 には、シルクで Sparrow64 と書かれていますが、Sparrow62 の誤りです。
- v2 には、細かいバージョン差分があり、1 セットの内に複数のバージョンの記載がありますが、そのようなセットになっております。v2.0.5 と v2.0.4 が同一のセットに含まれています
- v2.0.5 の抵抗 R9 は 27Ω に変更になりました。セットには予めはんだ付けしてあります。

## What's Sparrow 62 Keyboard

Sparrow 62 は 74th が頒布する自作キーボードキットです。
最初は Lily58 からインスピレーションを得て、数々の改良を加えました。

**using Kailh Choc V2 switches（keycap: DSA）**



これは購入者がご自身で組み立てが必要なキットです。
完成を保証するものではありません。

名称は Sparrow62 ですが、Sparrow v2 では **63 キー** で構成されます。

### 特徴 / features

- 縦に揃ったキー配置（カラムスタッガード）であり、指の曲げ伸ばしで多くのキーに届く様になっていること。
- 左右分離しており、肩を開いてタイピングができること。
- CherryMX 互換キースイッチが使えること。
- 薄型キースイッチ Kailh Choc v1/v2 が使えること。
- キースイッチが交換可能なようにスイッチソケットを使えること。
- 数字キーを網羅できるほどキーの数が多いこと（60%キーボード）。
- (new v2) 標準的なキーキャップセットを使用して、組み立てることができること。
- (new v2) 右手のキーボードの右側にマウスなどを配置できるように、右手の右側のキーの数を抑え、左側が膨らむデザインであること。
- (v1.3)オプションで、トラックパッドを右手左側に置くことができること。
- (v1.3)ゴム足の代わりに、ゴムシートを使うことで十分薄くすることができること。
- (new v2) 厚さの異なるプレート、PCB を用いて可能な限り薄くしていること。
- (new v2) PCB とゴムシートの間にプレートをはさみ、全体の剛性と、打鍵感を高めてあること。
- (new v2) 半導体不足でも入手の容易で、高性能な Raspberry Pi PICO （以下、PICO） を用いること。
- (new v2) マイコン 1 つで左右のキーボードを制御すること。
- (new v2) USB Type-C で接続できること。

### v1 と v2 の違い

- v1 は ProMicro と、QMK Firmware を用いて、キー入力を調整することができました。v2 は ProMicro と QMK Firmware に対応していません。
- チップ抵抗や、マイコン裏のスルーホールとランドの接続など、実装難度は高くなっています。

## 準備が必要なもの

### 部品

キットの他に追加で以下のものが必要です。

- スイッチ用ソケット x63
  - 「Cherry MX 互換用」と「Kailh Choc V1/V2 用」があります
  - MX 互換スイッチ用 ([遊舎工房](https://yushakobo.jp/shop/a01ps/)、[TALP KEYBOARD](https://talpkeyboard.stores.jp/items/5e02c5405b120c792616bcf9))
  - Kailh Low Profile Choc V1/V2 用 ([遊舎工房](https://yushakobo.jp/shop/a01ps/))、TALP KEYBOARD
- 自作キーボードスイッチ x63
  - Cherry MX 互換スイッチ と Kailh Choc v1/v2 スイッチを使うことができます
- TRRS ケーブル （4 極オーディオミニプラグのケーブル）x1
  - 3 極ステレオケーブルは不可
  - TRRS ケーブル x1 ([遊舎工房](https://yushakobo.jp/shop/trrs_cable/)、[Amazon](https://www.amazon.co.jp/dp/B018FPYC78))
  - 50 cm より長いケーブルで接続可能かどうかは確認していません。
- Raspberry PI Pico x1
- USB 2.0 Type-C Cable x1
- (CherryMX 互換スイッチを使用する場合）PCB マウントスタビライザー x

### 組み立てに必要な機材

- はんだごて、はんだこて台、スポンジ
  - BC 型 と ペン型 の 2 つのこて先があると便利ですが、どちらかでも大丈夫です。
- はんだ
- ピンセット（表面実装部品を抑えるのに利用します）
- ニッパ（連結ピンヘッダの切断や、長いピンの切断に使います）
- 両面テープ（ゴムシートとボトムプレートを接着します）
- はさみ（ゴムシートを切断するのに使います）
- PC（Windows、Linux、MacOS の動作するもの。ファームウェアの作成に必要。）

### あるとよいもの

- フラックス
  - はんだにはフラックスが含まれていて、端子に広がるようにできていますが、熱を加えすぎるとすべてのフラックスが蒸発します。その場合、追加のフラックスを入れて使います
- フラックス洗浄液
- ルーペ（スマートフォンカメラでも代用できます）
- ラジオペンチ（ネジ止めの他、スイッチの足が曲がってしまった場合に、つまんで伸ばします）
- 黒のマジックペン（側面を黒く塗ると一体感が出ます）

## キットに同梱されているもの

- 左手トッププレート x1
- 左手 PCB x1
- 左手ボトムプレート x1
- 右手トッププレート x1
- 右手 PCB x1
- 右手ボトムプレート x1
- 左手 IC カバー（黒アクリルプレート、穴 3 つ） x1
- 右手 IC カバー（黒アクリルプレート、穴 2 つ） x1
- ゴムシート x2
- 2012 SMD 抵抗 1kΩ(102) x2
- 2012 SMD 抵抗 5.1kΩ(512) x2
- 2012 SMD 抵抗 10kΩ(103) x5
- ダイオード 1N4148W x63
- USB Type-C ソケット基板 x1
- LED SK6812MINI-E x1
- TRRS ソケット x2
- IO エキスパンダー IC MCP23017 x1
- ピンヘッダー 1 列 12 ピン x1
- 3.5mm スペーサー x25
- 5.0mm スペーサー x5
- 4.0mm ネジ（黒） x30
- 5.0mm ネジ（銀） x30

※ キットに含まれる内容が MX 用トッププレート固定穴 1 つ分の、3.5mm スペーサー、4.0mm ネジ(黒)、5.0mm ネジ(銀)が少ない内容になっておりました。大変申し訳ありません。購入された方に追加の部品を送らせていただいています。74th.tech@gmail.com まで連絡いただきますようお願い致します。

ダイオードなど一部は必要個数以上同梱しています。

## 作成方法 / how to build

はじめに、PCB、トッププレート、ボトムプレートには、トッププレートの表側を除き、「PCB Foreground」「Top Plate Background」と、どの部品であるかどうかと、どちらが表（foreground）か裏（background）であるか記載があります。

特に PCB においては、表と裏を間違えないようにご注意ください。

### Kailh Choc v2 を使う場合

Kailh Choc v2 を使うの場合、足を 1 本切断する

Kailh Choc V2 has three copper wireand one of the red circles in the photo is cut with nippers.

Kailh Choc V2 では銅線の足が 3 つ出ていますが、このうち写真赤丸の 1 本をニッパで切断します。
切断した際に発生する小さな破片にご注意ください。
写真青丸の銅線は切断しないように気をつけてください。



ここできれいに切断すると、安定性が増します。

### SMD 抵抗のはんだ付け

チップ抵抗は左手と右手にそれぞれ 5 個ずつあります。

1k(102)、5.1k(512)、10kΩ(103)の 3 種類の抵抗を使い分けます。
間違えないように気をつけください。
どの抵抗かわからなくなったときにはルーペで拡大し、書かれている数字を確認してください。

まず、片方のランドにハンダを乗せます（予備はんだ）。



片手にはんだごて、片手にピンセットで抵抗をつまみ、ハンダを溶かして抵抗をスライドさせるように差し込みます。



片側のはんだ付けができたところで、一度誤った抵抗を接続していないか確認すると良いです。



もう片方のはんだ付けもします。



これを、左右 5 個ずつ行ってください。



### ダイオードのはんだ付け / Solder Diodes

Solder the diode, paying attention to the orientation of the diode.
ダイオードを向きを気をつけて、はんだ付けします。

The video by @Salicylic_acid3 is very good, so I think you can check here.
実装手順については、サリチル酸さんのツイートの動画が非常に良くできているため、こちらを確認いただくと良いと思います。

https://twitter.com/Salicylic_acid3/status/1296494976319315970
https://twitter.com/Salicylic_acid3/status/1108798243142434816

先に PCB の片側にはんだをつけます。



つけたハンダを溶かして、ダイオードを片側をはんだ付けします。



まず、すべてのダイオードを**片側だけ**はんだ付けをしましょう。
片側のはんだ付けが済んだところで、一度すべてのダイオードが同じ向きを向いているか確認します。



確認が済んで大丈夫であれば、反対側の足もはんだ付けします。



### スイッチソケットを実装する

Choc 用のスイッチソケットは、Cherry MX 用スタビライザーに干渉します。
使用しない場合は異なるスイッチのソケットは実装しないようにしてください。

Choc 用スイッチソケットには向きがあります。以下の記事を参考に、正しい向きで実装するようにしてください。

- https://www.eisbahn.jp/yoichiro/2021/01/kailh_choc_v1_socket.html
- https://kochikbd.hatenablog.com/entry/choc-socket-orientation
- https://scrapbox.io/self-made-kbds-ja/Kailh_Choc_%E3%82%BD%E3%82%B1%E3%83%83%E3%83%88%E3%81%AE%E6%96%B9%E5%90%91%E3%81%AB%E3%81%A4%E3%81%84%E3%81%A6

ソケットのはんだ付けは動画のようにすることをおすすめしています。

[動画（Google Drive）](https://drive.google.com/file/d/1VQYtKHCZkTQwoi6JiOMwTrHwYhy1caux/view?usp=sharing)

[動画（Twitter）](https://twitter.com/74th/status/1514942328900775938)

[動画ファイル switch_socket.mp4](./img/62v2/switch_socket.mp4)

1. ソケットを正しい方向にセットします。
2. ソケットの端子の内側から、はんだごてで熱を加えます
3. ソケットの外側から、はんだごてを当ててはんだを流し込みます
4. はんだを外してから、ピンセットなどでソケットを抑えます
5. はんだごてを抜きます

### LED ライトを実装する

LED SK6812MINI-E の方向を注意してください。

LED の実装は、PCB 裏面に裏向きにセットして実装します。
PCB 表向きから見ると、発光面が見える形になります。

また、LED の 4 本の足の 1 つ GND には切れ込みが入っています。切れ込みとシルクの斜め線を合わせるようにしてください。





向きを確認できたら、一方の足をマスキングテープで留めます。



すべての足を実装します。



### USB Type-C ソケットを実装する

このキットには USB Type-C ソケット基盤が付属しています。
もしキーボードの使用で USB ソケットが壊れてしまった場合、交換用の USB Type-C ソケット基盤を提供できるため、74th まで問い合わせください。

まず、PCB を裏向きにし、ソケット基盤を**表側**から当てます。
表側には白いラインがついているので、そのラインのある方に当ててください。

また、表側からソケット基盤の文字が読めることを確認してください。

↓ 表側。ソケット基盤を当てる前。



↓ 裏側。表側から基盤を当てている。



ピンヘッダを裏から、プラスチックの部分が上になるように差し込みます。
ピンヘッダは穴に刺さるように分割してください。
分割した際にプラスチックの部分が破れてしまっても問題ありません。



差し込んだ後に、マスキングテープで固定をします。



表に向けます。このとき、ソケット基盤と PCB が密着するようにしてください。



表からはんだごてでピンヘッダをはんだ付けします。



裏に向けます。



ラジオペンチでピンヘッダのプラスチックの部分をゆっくりと抜きます。



7 ピンのものは、左右交互に少しずつ引き抜いてみてください。





ぬけたら、裏側からはんだ付けをします。



はんだから飛び出ているピンをニッパで切り取ります。





### Raspberry Pi PICO （以下、PICO）の USB のランドへの予備ハンダ

このキットでは USB 端子を、付属の Micro USB から USB Type-C に変換しています。
PICO の裏側には、USB DM/DP の信号のランド（TP2、TP3）があり、ここを PCB と接続する必要があります。

PICO の実装の前にここにハンダを少し載せておきます。
多くなるとガタつくため、少量のせてください。
写真は TP3 に乗せていますが、TP2 と TP3 の 2 つに乗せてください。



### Raspberry Pi PICO （以下、PICO）の実装

PICO は PCB を表向きにして、はんだづけをします。



PICO を重ねます。



PICO と PCB には M2 の穴があいており、ここに 5mm のネジを差し込むと、PICO が動かずにはんだづけができます。



まず端の 2 箇所を、PICO の側面の端子を使ってはんだづけをします。
はんだづけをしてから M2 のネジを外します。



残りをはんだづけします。

最後に横から確認し、PCB のランドと、PICO の間が空いていないことを確認します。



空いてしまっている場合、以下の写真のようになります。再度はんだづけをおこなってください。



### Raspberry Pi PICO の USB 端子の実装

ここが Sparrow 62 v2 の最難関です。

PCB を裏側に、この先程はんだを少し乗せた USB DM/DP が覗けるスルーホールが空いています。



このスルーホールとランドを接続するように、はんだごてをあててはんだを流し込みます。
このとき、はんだごてのこて先はペン型のこて先を利用するとやりやすいです。





実装後は一度 USB Type-C ソケットを、PC の USB と、ケーブルで接続してみましょう。
RPI-RP2 というドライブがマウントできれば、成功です。

### IO エキスパンダ MCP23019 の実装

IO エキスパンダ MCP23019 を実装します。
まず、右手用の表面に、図が入っています。
表面から切れ込みの入っている方向に注意して、差し込みます。
足を多少曲げなければ入らないようになっています。
曲げすぎて折れてしまわないように気をつけてください。





裏面からはんだ付けを行います。



### TRRS ジャックの実装

TRRS ジャックは、左右それぞれ 1 つずつあります。
表面から差し込みます。





浮いてしまわないように、マスキングテープで留めておくと良いです。



裏面から、はんだづけをします。





これで、はんだこてが必要な作業は以上になります。

### スタビライザーの装着

CherryMX 互換スイッチを使用する場合、このタイミングでスタビライザーを差し込んでください。
左手に 1 箇所、右手に 3 箇所あります。



### ボトムプレートが鑑賞しないか確認する

まず、裏面からボトムシートを重ねます。



これは実装箇所に干渉せず、ピタリを収まるようにできています。



干渉する場合、部品のズレなどをはんだ付けを再度やり直してください。

### すべてのキーが動作するか確認する

#### USB の認識確認

キーがすべて動作するか確認するため、テスト用のファームウェアを書き込みます。

まず、TRRS ケーブル使って、左右のキーボードをつなぎます。

USB ソケットから PC に接続し、RP2-PICO というドライブが認識するか確認します。

ここで USB ドライブが認識しない場合、以下の可能性があります。

1. 左手表面の PICO の実装において、PICO の端子とランドが正しく実装されていない。
2. 左手裏面のスルーホールから PICO のランド接続するところが、正しく実装できていない。
   1. スルーホールをはんだで覆ってしまっていて、PICO のランドに届いていない。
   2. PICO がずれていて、単一のスルーホールが、複数のランドに接続されている。
   3. スルーホールの上部にはんだがはみ出しており、意図せず 2 つスルーホールが接続されている。
3. PC の設定で USB メモリが自動で認識しないようになっている
4. USB ソケット基盤のはんだ付け不良

1.のケースとしては、加熱が PICO の端子のみで、PCB のランドが熱し足りない場合、はんだが PICO とランドを接続できないことがあります。
PCB を横から覗き込み、PCB のランドと PICO の端子が確実にはんだによって接続されていることを確認します。

2.のケースとしては、複数考えられます。
スルーホールの周りをよく観察してください。
一度はんだ空いてとりせんを用いてはんだを取り除き、再度はんだづけを行ってください。

PICO のランドは、熱しすぎると剥がれて取れてしまう場合があります。
ですので、はんだ吸い取り線が PCB にくっついて取れない場合も、力任せに引っ張ってしまわないように気をつけてください。

#### ファームウェアの準備と書き込み（KMK Firmware）

KMK Firmware を使った例を紹介します。
以下のリポジトリをチェックアウトし、記載の install に従い、セットアップを行います。

https://github.com/74th/sparrow62-kmk

キーマップファイル keymap.py には、[keymaps/test/keymap.py](https://github.com/74th/sparrow62-kmk/blob/main/keymaps/test/keymap.py) を使います。
こちらは、レイヤーを使用しないキーマップの例になっており、キーの実装がうまくいっているかどうかを確認するのに最適です。

#### キースイッチのテスト

[QMK Configurator の Keyboard Tester](https://config.qmk.fm/#/test) を開き、各スイッチソケットを通電させ、各キーが動作するか確認してください。
aaa
通電させるためのケーブルをお持ち出ない場合、キースイッチをソケットに挿して、押下することでもテストできます。

ここでは、以下のような問題が見つかります。

1. 一部のキーが動作しない
   1. ダイオードが正しい方向に実装されていない、もしくははんだづけ不良がある
   2. スイッチソケットが正しくはんだ付け不良がある
2. キーが一切機能しない
   1. PICO へ正しくファームウェアがインストールされていない
   1. TRRS ケーブルではなく、モノラル/ステレオオーディオケーブルを使用している
   1. TRRS ケーブルとして、ノイズが大きいケーブル、または長すぎるケーブルを使用している
   1. TRRS ソケットにはんだづけ不良がある
   1. 1kΩ 抵抗、10kΩ 抵抗が誤って接続されている

#### シリアルコンソールの確認

すべてのキーの動作を確認できた場合、シリアルコンソールを確認する必要はありません。
シリアルコンソールには、以下のエラーメッセージが出ることがあります。

- `no module named 'kmk' / cannot find kmk module` : KMK モジュールが、PICO 内の lib/ ディレクトリに入っていません。
- `no module named 'adafruit_mcp230xx' / cannot find adfruit_mcp230xx module` : MCP23017 のライブラリが、 PICO 内の lib/ ディレクトリに入っていません。
- `no module named 'neopixel' / cannot find neopixel module` : neopixel ライブラリが lib/ ディレクトリに入っていません。
- `No pull up found on SDA or SCL; check your wiring / cannot communicate to right board` : 右手とかろうじて通信はできているが、適切な状態ではないようです。この場合、左手の R1、R2 の 1kΩ 抵抗が正しく実装されていない場合に発生します。
- `ValueError: No I2C device at address: 0x20 / cannot communicate to right board` : 右手と一切通信できない状態です。R1、R2 の抵抗や、PICO の GPIO 12、13 の接続、TRRS ソケットの接続を確認し、再度はんだごてを当ててはんだを追加したりします。

### ボトムプレート、スタビライザー、トッププレートの組み立て

ネジで止める箇所には、トッププレートとつなぐ部分と、アクリル製 IC カバーとつなぐ部分の 2 種類があります。IC カバーのネジ止めは、以下の 5 箇所になります。



IC カバーの箇所は以下のように重ねてネジ止めを行います。



順序は以下のように行います。

1. PCB と ボトムプレートを重ねます。
2. 下から、5.0 mm ネジ（銀色）差し込みます。
3. 上から、5.0 mm スペーサーを当てて、ネジを回します。
4. スペーサーをラジオペンチなどで固定し、ネジを回して締めます。樹脂スペーサーのため、締めすぎると削れてしまうため、注意します。
5. アクリル IC カバーを重ねます。
6. 上から 4.0 mm ネジ（黒色）を差し込み、締めます。樹脂スペーサーのため、締めすぎると削れてしまうため、注意します。

Kailh Choc スイッチを使用する場合、ボトムプレート、PCB、トッププレートは以下のように隙間なく重ねます。ネジ止めは IC カバーのみ行います。



CherryMX 五感スイッチを使用する場合、ボトムプレート、PCB、スペーサー、トッププレートを以下のように重ねます。



順序は以下のように行います。

1. PCB と ボトムプレートを重ねます。
2. 下から、5.0 mm ネジ（銀色）差し込みます。
3. 上から、5.0 mm スペーサーを当てて、ネジを回します。
4. スペーサーをラジオペンチなどで固定し、ネジを回して締めます。樹脂スペーサーのため、締めすぎると削れてしまうため、注意します。
5. トッププレートを重ねます。
6. 上から 4.0 mm ネジ（黒色）を差し込み、締めます。樹脂スペーサーのため、締めすぎると削れてしまうため、注意します。

### ゴムシートの貼り付け

ゴムシートはボトムプレートの裏に貼り付けて使います。
貼り付けには、両面テープ（ご用意ください）を使ってボトムプレートの裏に貼り付けます。
また、はさみでボトムプレートの形に切り抜きます。

### 完成

以上で、完成です。

### 組立後に動作しないキーがある場合

#### 1 キーのみ動作しない場合

まず、キースイッチの足が曲がっていないか確認してください。

左手用のキーの場合、以下の同じ色の部分がつながっています。それぞれテスターなどで疎通しているか確認ください。



右手用のキーの場合、以下の同じ色の部分がつながっています。それぞれテスターなどで疎通しているか確認ください。



#### 縦一列、横一列が動作しない場合

データシートの回路図を確認ください。PICO の GPIO がどの 行、列 と対応しているか記述されています。
その箇所のはんだを追加して実装し直すなど行ってください。

## Using QMK Firmware / QMK Firmwareの使用について

Currently, it is not merged into the official repository, but forked and operated in a private repository.

現状公式リポジトリにはマージしておらず、個人リポジトリでフォークして運用しています。

https://github.com/74th/qmk_firmware_sparrow_keyboard/tree/sparrow/keyboards/sparrow62/rev2

You can use `qmk` command by cloning this to `$HOME/qmk_firmware` or adding it as a remote.

こちらを `$HOME/qmk_firmware` にクローンしたり、リモートとして追加することで、`qmk` コマンドを利用することができます。

See the QMK Firmware documentation for more details.

くわしくは、QMK Firmware のドキュメントを参照してください。

## Using REMAP/VIA / REMAP/VIA を利用する

A firmware for VIA is prepared. Please write this to your Raspberry Pi Pico and use it.

VIA用のファームウェアをいかに用意しています。こちらをRaspberry Pi Picoに書き込んで利用ください。

[./firmware/62v2/sparrow62_v2_via.uf2](https://github.com/74th/sparrow62-buildguide/raw/refs/heads/master/firmware/62v2/sparrow62_v2_via.uf2)

We are currently applying to add a keyboard to REMAP. Until then, you can use the following as a configuration file.

## 資料

- [回路図、配線図等データシート](./datasheets/)
- [付属部品の追加の購入先](./parts/)

## Contact me

- Twitter: @74th
- Mail: site@74th.tech

```

```

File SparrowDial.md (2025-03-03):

# SparrowDial Keyboard Kit Build Guide

このビルドガイドには他のキーボードの写真が含まれていますのでご注意ください。

また、作成中に疑問点等質問がありましたら、74th（Twitter(X): [@74th](https://twitter.com/74th)、email:`site@74th.tech`、本リポジトリのissue）まで問い合わせください。

## 販売先

- booth(準備中)

## SparrowDial の注意点

- マイコンRP2040が直接PCBに実装されています。
- GH60互換キーボードケース対応のPCBですが、必ずしもすべてのケースに対応するわけではありません。
- キットのPCBにはRP2040を動作させるためのマイコン及び受動部品が実装されています。

## キットの内容

### キーボード PCB

- SparrowDial PCB x1
- ダイオード 1N4148W x56
- RGBLED SK6812-MINI-E x1
- 表面実装 Grove(HY2.0) コネクタ（アイボリー色） x2

### M5Stack Core2 PortA 底面引き出しモジュール

- M5Stack Core2 ProtA 底面引き出し PCB x1
- スルーホール Grove(HY2.0) コネクタ（白色） x1
- 表面実装 2x15P ピンヘッダ x1

### ケーブル

- Grove(HY2.0) 互換 ケーブル 10cm x1
- Grove(HY2.0) - USB-C Daughter ケーブル 10cm x1

### ケース組み込み部品

- SparrowDial Top Plate (FR4 PCB) x1
- M2 2mm スペーサー x6 : ケースとPCBの間のスペーサー
- M2 6mm 黒 平ネジ x5 : ケースとPCBの間のネジ止め（M5Dialを使う場合）
- M2 4mm 黒 平ネジ x5 : ケースとPCBの間のネジ止め（M5Stack Core2を使う場合）
- M3 10mm 鍋ネジ x2 : M5StackCore2とトッププレートのネジ止め
- M3 15mm 鍋ネジ x2 : M5StackCore2とトッププレートのネジ止め

## PCB に実装済みの部品

- マイコン RP2040 x1
- マイコンプログラム用フラッシュ W25Q32JVS x1
- RP2040 の動作に必要な受動部品（コンデンサ、抵抗、水晶発振器）
- 6x6mm SMD タクタイルスイッチ（RP2040 RESET、BOOTSEL用） x2
- 電源保護用理想ダイオード CH213K x1
- USB Type-C コネクタ x1

## キットの組み立てに必要なもの

### キットの他に必要なもの

- [GH60互換キーボードケース x1](./parts.md#gh60互換ケース)
- [MX互換スイッチソケット x56](./parts.md#cherrymx互換スイッチソケットkailhスイッチソケット)
- [MX互換スイッチ x56](./parts.md#cherrymx互換スイッチ)
- [MX互換スイッチ用キーキャップ一式 x1](./parts.md#cherrymx互換キーキャップ)
- PC接続用USBType-Cケーブル x1
- Trackpad用M5Stackどちらか
  - [M5Stack Core2 x1](./parts.md#m5stackcore2)
  - [M5Stack Dial x1](./parts.md#m5dial)

### 組み立てに必要な機材

- はんだごて、はんだ
- ニッパ（キーボードケースの加工用）
- ピンセット（表面実装部品を抑えるのに利用します）
- PC（Windows、Linux、MacOS の動作するもの。ファームウェアの作成に必要）

### あるとよいもの

- フラックス
  - はんだにはフラックスが含まれていて、端子に広がるようにできていますが、熱を加えすぎるとすべてのフラックスが蒸発します。その場合、追加のフラックスを入れて使います
- フラックス洗浄液（はんだや、フラックスが無洗浄タイプでない場合）
- ルーペ（スマートフォンカメラでも代用できます）
- ラジオペンチ（ネジ止めの他、スイッチの足が曲がってしまった場合に、つまんで伸ばします）

## how to build / 作成方法

このキーボードには、RP2040の動作に必要な部品は既に実装されています。

### M5StackCore2 PortA 底面引き出しモジュールの組み立て

M5StackCore2を利用する場合、モジュールを組み立てます。

JP1ジャンパがありますが、ここは真ん中とBATをショートさせます。



次に表面実装2x15Pピンヘッドを実装します。スルーホールと異なり、はんだがピンヘッダにのみに回り、PCBのランドに届いていないことがあります。ランドまで加熱するようにしてください。ピンヘッダはずれやすいため、対角端の1ピンずつを先に実装して位置合わせの上、残りを実装すると良いでしょう。

Grove(HY2.0)コネクタを実装します。このコネクタは、PortAの記述がある面に実装します。



### ケースの加工

遊舎工房や、TalpKeyboard で販売されているプラスチック GH60互換ケースでは、干渉が発生するためケースの加工が必要です。

#### M5StackCore2 を使う場合

写真の印の部分の仕切りをニッパで切り取ります。記しのネジ穴の支えのプラスチックがわずかに干渉するため、右側のみを2mmほど削ります。



#### M5Dial を使う場合



まず、写真のネジ止め部分を、ニッパで切り取ります。



次に、写真の印の部分の仕切りをニッパで切り取ります。

#### M5Dial がどうしても収まらないとき

コードの整理などでぎりぎり収まりますが、収まらないときは、はんだごてで、写真の箇所のプラスチックを溶かし、空間を広げます。



主に障害になるのは、M5Dial の底部の下の方です。

### Solder Diodes / ダイオードのはんだ付け

Solder the diode, paying attention to the orientation of the diode.
🇯🇵 ダイオードを向きを気をつけて、はんだ付けします。



The video by @Salicylic_acid3 is very good, so I think you can check here.
🇯🇵 実装手順については、サリチル酸さんのツイートの動画が非常に良くできているため、こちらを確認いただくと良いと思います。

https://twitter.com/Salicylic_acid3/status/1296494976319315970
https://twitter.com/Salicylic_acid3/status/1108798243142434816

Solder one side of the PCB first.
🇯🇵 先に PCB の片側にはんだをつけます。



Melt the solder you have applied and solder one side of the diode.
🇯🇵 つけたハンダを溶かして、ダイオードを片側をはんだ付けします。



First, solder all the diodes **only one side**.
Once one side is soldered, check that all diodes are facing the same way.
🇯🇵 まず、すべてのダイオードを**片側だけ**はんだ付けをしましょう。
片側のはんだ付けが済んだところで、一度すべてのダイオードが同じ向きを向いているか確認します。



Once you have checked and it is ok, solder the other leg as well.
🇯🇵 確認が済んで大丈夫であれば、反対側の足もはんだ付けします。



### Soldering switch sockets / スイッチソケットを実装する

We recommend soldering the socket as shown in the video. With the latest Kailh switch sockets, it is no longer possible to insert the soldering iron from the top, but you should still insert it from the open side.
🇯🇵 ソケットのはんだ付けは動画のようにすることをおすすめしています。最新のKailh社製スイッチソケットでは、上面からはんだごてを差し込むことはできなくなりましたが、それでも横の空いている面からはんだごてを差し込む様にします。

[Movie（Google Drive）](https://drive.google.com/file/d/1VQYtKHCZkTQwoi6JiOMwTrHwYhy1caux/view?usp=sharing)

[Movie（Twitter）](https://twitter.com/74th/status/1514942328900775938)

[Movie file switch_socket.mp4](./img/62v2/switch_socket.mp4)

1. Set the socket in the correct orientation.
2. Apply heat with a soldering iron from the inside of the socket's terminals.
3. From the outside of the socket, apply solder with the soldering iron and pour the solder into the socket.
4. Remove the solder and hold the socket with tweezers.
5. remove the soldering iron

🇯🇵

1. ソケットを正しい方向にセットします。
2. ソケットの端子の内側から、はんだごてで熱を加えます
3. ソケットの外側から、はんだごてを当ててはんだを流し込みます
4. はんだを外してから、ピンセットなどでソケットを抑えます
5. はんだごてを抜きます

### RGBLED ライトを実装する

RGBLED SK6812MINI-E の方向を注意してください。

RGBLED の実装は、PCB 裏面に裏向きにセットして実装します。
PCB 表向きから見ると、発光面が見える形になります。

また、LED の 4 本の足の 1 つ GND には切れ込みが入っています。切れ込みとシルクの斜め線を合わせるようにしてください。



向きを確認できたら、一方の足をマスキングテープで留めます。



すべての足を実装します。



### Soldering Grove(HY2.0) sockets / Grove(HY2.0) ソケットの実装

2箇所あるGrove(HY2.0)ソケットを実装します。

まず、1本のピンのみを実装し、はんだごてを更にあてながらPCBのシルクの位置になるように調整します。その後、残りのピンも実装します。ケーブルを差し込む面にも下部に固定用の金属部分があるため、こちらも忘れずに実装します。



### M5StackCore2、M5Dialへのファームウェアの書き込み

ファームウェアは以下の方法でマイコンにアップロードできます。

- 1. WebHIDを用いる [Sparrow Series Keyboards ESP32 Upload tool https://74th.github.io/sparrow62-buildguide/](https://74th.github.io/sparrow62-buildguide/) にて、ファームウェアをアップロードする
- 2. [esptool](https://github.com/espressif/esptool/)、[espflash](https://github.com/esp-rs/espflash)等ファームウェアアップロードツールを用いる
- 3. PlatformIOを用いて自前でビルドして書き込む

[Sparrow Series Keyboards ESP32 Upload tool](https://74th.github.io/sparrow62-buildguide/)を用いる場合、特にツールのインストールがなく手軽に行うことができます。
既に[esptool](https://github.com/espressif/esptool/)、[espflash](https://github.com/esp-rs/espflash)を導入しているのであれば、そのツール経由の方が煩雑ではないかもしれません。
このファームウェアはPlatformIO（VS Codeを用いた汎用ファームウェア開発環境）を用いて、Arduinoフレームワークで開発するようになっております。M5Dial Simple Pointer FirmwareにはWiFi経由でアップロードする方法もあり、それを利用する場合にはWiFiのSSIDとパスワードを追加する必要があるため、自前でのビルドが必要になります。

M5StackCore2、M5DialはUSBで接続します。M5Dialについてはケースに組み込む前にファームウェアをアップロードする必要があります。

#### Sparrow Series Keyboards ESP32 Upload tool

Chromeブラウザを用いて、以下のサイトを開いてください。

https://74th.github.io/sparrow62-buildguide/

M5StackCore2を用いる場合「M5StackCore2 Simple Pointer」の下の「CONNECT」ボタンを、M5Dialを用いる場合「M5Dial Simple Pointer」の下の「CONNECT」ボタンを押してください。

すると、接続するUSBを選択するポップアップが表示されます。ここで、「USB JTAG/serial debug unit」など、デバイスのUSBを選択し「CONNECT」ボタンを押してください。どれがデバイスのUSBかわからない場合、このポップアップの表示中にUSBを抜き差しすると、登場するUSBデバイスがそれであるとわかります。

選択した後に「Device Dashboard」というウィンドウが表示されるため、「INSTALL <ファームウェア名>」のボタン（文字）を押します。「Confirm Installation」というウィンドウが続けて表示されるため「INSTALL」ボタンを押します。すると、ファームウェアがインストールされます。完了すると「Installation complete!」の表示になります。

インストール後にデバイスは自動で再起動し、画面上に「no I2C Connection」と表示されていれば正常です。

#### esptool、espflashを用いる場合

esptool、espflashを用いる場合、ファームウェアを以下のGitHubリポジトリのReleaseから、最新の m5stackcore2-simple-pointer.bin、m5dial-simple-pointer.bin ダウンロードして利用ください。

https://github.com/74th/m5-trackpad-module/releases

コマンドが二つかかれていますが、両方行う必要はありません。どちらかのツールを利用ください。実行ファイル一つの[espflash](https://github.com/esp-rs/espflash)の方が手軽に思われます。

```
# M5StackCore2
esptool.py --chip esp32 write_flash -z 0 m5stackcore2-simple-pointer.bin
espflash write-bin 0 m5stackcore2-simple-pointer.bin

# M5Dial
esptool.py --chip esp32s3 write_flash -z 0 m5dial-simple-pointer.bin
espflash write-bin 0 m5dial-simple-pointer.bin
```

#### 自前でビルドして書き込む

PlatformIO等の使い方についてはご自身で調査の上利用ください。

まず、以下のリポジトリをチェックアウトします。

https://github.com/74th/m5-trackpad-module

それぞれのディレクトリをワークスペースフォルダーにするようにVS Codeを起動します。

- M5StackCore2: m5stackcore2-simple-pointer ディレクトリ
- M5Dial: m5dial-simple-pointer ディレクトリ

VS Codeに拡張機能[PlatformIO IDE](https://marketplace.visualstudio.com/items?itemName=platformio.platformio-ide)をインストールします。

M5Dialの場合には、src/ssid.h.templateをsrc/ssid.hとして複製し、コード内のSSIDとパスワードを更新します。

VS Code上でコマンド「PlatformIO: Upload」を実行すると、USB経由でアップロードすることができます。

M5Dial Simple Pointer Firmwareについては、WiFi経由でファームウェアをアップロードする機能があります。これは、ボタン（上面のオレンジ色のリングのM5と書かれた部分）を押しながら電源入れることで、WiFiへ接続し、ファームウェアのアップロードを受け付けるモードになります。WiFiへの接続に成功すると、画面上にIPアドレスが書き込まれます。この状態で、PlatformIOの設定ファイル`platfomio.ini`の最下部に以下の記述を追加すると、コマンド「PlatformIO: Upload」を行うと、書き込めるようになります。なお、`image=@`のパスの記述はMacOS、Linuxの場合の記述例になります。Windowsでは適宜変更を行ってください。

```ini
# platformio.ini

upload_protocol = custom
upload_command = curl -F "image=@.pio/build/m5dial/firmware.bin" 192.168.1.100/update
```

### ケースへの組み込みの前の実装確認

ケースへの組み込むと、はんだ実装に不具合があっても、キーキャップ、スイッチ、ネジなどのすべてを外さないとPCBの実装面にはアクセスできません。なるべく、ケースに組み込む前に、一度はんだ実装不良がないか確認すると良いでしょう。

#### M5StackCore2を使う場合

M5StackCore2のM-Bus PCB（底面のCore2と書かれた白いPCB）を外します。このPCBには、ピンヘッダとピンソケットで本体PCBに接続されており、垂直に抜く必要があります。



M5StackCore2の底面の4つのネジを外し、ボトムケースを取り外します。ボトムケース部分には、バッテリーが搭載されており、本体PCBとソケットとケーブルで接続されています。このソケットを外して下さい。



M-BusにM5StackCore2 PortA 底面引き出しモジュールを写真の向きで接続します。



なお、必ずバッテリーを外した状態で行ってください。

M5StackCore2 PortA底面引き出しモジュールのGroveソケットと、SparrowDial PCBのI2C Groveと書かれたGroveソケットを、HY2.0(Grove)ケーブルで接続してください。

#### M5Dialを使う場合

M5Dialの裏面のPortAのGroveソケット（赤色）と、SparrowDial PCBのI2C Groveと書かれたGroveソケットを、HY2.0(Grove)ケーブルで接続してください。

M5DialのUSBと、SparrowDial PCBのPower Groveと書かれたGroveソケットを、Grove USBドーターケーブルで接続してください。

#### 動作の確認

PCBをUSBに接続します。出荷時点でキーボードとして動作するファームウェアが書き込まれています。

M5StackCore2、M5Dialにno I2C Connectionと書かれている場合、I2C通信に失敗していることがあります。ソケットの実装を見直してください。また、ファームウェア書き込み後にもこの表示が消えない場合には、一度USBを抜き差しして電源を入れ直してみてください（USBの抜き差しで、RP2040とM5StackCore2/M5Dialの両方の再起動を同じタイミングで行えます）。

M5StackCore2/M5Dialを操作し、マウスカーソルが動作することを確認してください。

各キーが動作することをRemapのTest Matrix modeを使って確認して下さい。

> RemapのTest Matrix modeを使ったキーマトリックスのテスト方法
>
> [./remap_test_matrix_mode.md](./remap_test_matrix_mode.md)

### ケースへの組み込み

ケースへの組み込みは以下の手順で行います。

1. ケース底面の加工（まだの場合）
2. SparrowDial PCBへHY2.0(Grove)ケーブルを接続
3. （M5Dialを用いる場合のみ）ケース底面のネジ穴に対して、2mm中空スペーサーを置く
4. SparrowDial PCBをケースに配置する
5. SparrowDial PCBとケースのネジ止め
6. SparrowDial Top PlateへのM5StackCore2、M5Dialの組み込み
7. SparrowDial Top Plateを重ねる
8. スイッチの差し込み
9. キーの動作テスト
10. キーキャップの差し込み

#### 1. ケース底面の加工（まだの場合）

前述のケース底面の加工を行ってください。

#### 2. SparrowDial PCBへGroveケーブルを接続

HY2.0(Grove)ケーブルをSparrowDial PCBのI2C Groveポートに接続してください。

M5Dialを用いる場合、追加でGrove USBドーターケーブルをSparrowDial PCBのPower Groveポートに接続してください。

コードの先端を、SparrowDial PCBの中央の円形ホールを通すようにしてください。



#### 3. （M5Dialを用いる場合のみ）ケース底面のネジ穴に対して、2mm中空スペーサーを置く

ケース底面の、各ネジ穴のところに、M2 2mm中空スペーサーを置きます。



#### 4. SparrowDial PCBをケースに配置する

SparrowDial PCBを載せます。

M5Dialを用いる場合、ケースの上の中空スペーサーを落とさないように気をつけてください。

M5StackCore2を用いる場合、若干ダイオードがケースに干渉しますが、少しPCBをずらすと干渉を避けて、ケースのネジ穴に密着させることができます。



#### 5. SparrowDial PCBとケースのネジ止め

利用するモジュールによって使用するネジが異なります。

- M5StackCore2を使う場合: M2 4mmネジ
- M5Dialを使う場合: M2 6mmネジ

付属のネジを用いて、5箇所を留めます。M5Dialを用いる場合、中空スペーサーを落とさない様にしてください。



#### 6. SparrowDial Top PlateへのM5StackCore2、M5Dialの組み込み

SparrowDial Top Plateは、SparrowDialの名前が入っている方が、上面になります。上面がタッチパネルになるように取り付けます。

##### 6.1. M5StackCore2を用いる場合

M5StackCore2のタッチボタンが左側になるように、Top Plateの裏面からM3ネジで留めます。



なお、必ずバッテリーを外した状態で行ってください。

M5StackCore2 PortA底面引き出しモジュールのGroveソケットと、SparrowDial PCBのI2C Groveと書かれたGroveソケットを、HY2.0(Grove)ケーブルで接続してください。

##### 6.2. M5Dialを用いる場合

M5Dialの、オレンジ色の大きなナット部品を使って、Top Plateを挟み込むように固定します。この時、上面のM5の文字が下になるようにしてください。



M5DialのPortA Groveソケット（赤茶色）に、SparrowDial PCBのI2C Groveと接続されたHY2.0ケーブルを接続します。



M5DialのUSBソケットに、SparrowDial PCBのPower Groveと接続されたGrove USBドーターケーブルを接続します。USB-Cドーターケーブルは壊れやすいため、気をつけてください。もし、USB-CドーターケーブルのUSB-Cコネクタからケーブルが外れてしまった場合には、ケーブルの皮むきを行い、以下のVCCとGNDのみ接続してください。



M5Dialは垂直には、USBの部分が邪魔して入りません。USBドーターケーブルのUSBコネクタがPCBの下に入るようにななめに差し込んでください。M5Dialはかなりギリギリの所で格納されます。ケーブルをM5Dialのケースの接触部分に当たらないようにしてください。わりと、スイッチをはめていく段階で収まったりします。

どうしてもM5Dialが収まらない場合、はんだごてを用いてケースの接触部分のプラスチックを溶かすなどして、空間を作って見てください。

#### 7. SparrowDial Top Plateを重ねる

SparrowDial Top Plateを、ケースに重ねます。SparrowDialは、PCBとTop Plate間の固定はスイッチのみで行うため、この時点では固定されません。



#### 8. スイッチの差し込み

SparrowDial Top Plateの穴から、SparrowDial PCBに向かってスイッチを差し込みます。MX互換スイッチには、Top Plateを挟み込む溝が付いています。この溝にTop Plateが挟まれるようにTop Plateを持ち上げてください。

SparrowDialのキーはGH60互換ケースを使う都合、以下のキーが異なる向きを向いています。差し込むときに気をつけてください。



この時、M5Dial、M5StackCore2のまわりのスイッチと、左右外側のスイッチから、順に固定していくと、高さをキープしやすくなります。





M5Dialは結構干渉し、十分に刺さらない場合があります。その場合、M5Dialのケーブルが干渉していないか確認して、ケーブルをずらしたり、前述の「M5Dial がどうしても収まらないとき」の対策を行ってみてください。

#### 9. キーの動作テスト

USBをPCに接続し、すべてのキーが動作するかを確認します。詳細は前述の「ケースへの組み込み前の実装確認」を確認ください。

動作しないキーがある場合、一度すべてをケースから取り外し、該当キーのダイオードとスイッチソケットの実装をやり直します。

#### 10. キーキャップの差し込み

すべてのキーが動作することを確認できたならば、キーキャップを付けて完成です！

## トラックパッドモジュールの操作方法

### M5StackCore2の場合

以下の操作となっております。

- スライド：ポインタ移動
- タップ：左クリック
- 2本指タップ：右クリック
- 2本指垂直スライド：ホイール
- 左下のエリアのタップ：左クリック

詳しくは、以下の動画を確認ください。

https://www.youtube.com/watch?v=8jPP54jqswg

なかなか2本指タップの反応が難しいです。指を離したり、垂直方向ではなく水平方向に指が並ぶようにしたりすると反応します。

その場合には、キーに左クリック、右クリックを設定してみてください。また、ユーザキー0`SCROLL`（REMAP上の`USER 0`）には押下中のスライドでスクロールする機能が含まれています。初期ファームウェアでは有効になっていませんが、試してみてください。

### M5Dialの場合

以下の操作となっております。

- スライド：ポインタ移動
- タップ：左クリック
- ボタン：右クリック
- 指がタッチパネルに接触中にボタン（M5と書かれた部分）：左クリック
- ロータリーエンコーダ：ホイール

指がタッチパネルに接触中にボタンを押してその状態でスライドすることで、ドラッグを実現するように設計しています。しかし、操作が若干難しいです。

その場合には、ーに左クリックを設定してみてください。

## キーマップの変更、RP2040ファームウェアの更新

キーマップの変更には、2種類の方法があります。

- VIA、Remapを用いる
- QMK Firmwareでファームウェアをビルドする
- RP2040に対応したファームウェアを作成する

始めからVIA、Remap用のファームウェアが書き込まれた状態になっています。Remapを用いる場合には特にこの工程をする必要はありません。

VIA、Remapを利用しない利用しない場合は、別途ファームウェアを用意してください。RP2040はBOOTSELボタンを押しながらRESETを行うと、USBマスストレージデバイスがPCに認識され、その中にuf2ファイルをドラッグドロップすることで、ファームウェアを書き込むことができます。

### VIA、Remapを利用する場合

VIA、RemapはWebサイトや、ツール上からキーマップの書き換えができるサイトです。VIA対応のファームウェアをRP2040にアップロードすると、利用できるようになります。最初からRemap用のファームウェアが書き込まれた状態で出荷しています。

- Remap https://remap-keys.app/
- VIA https://caniusevia.com/

ファームウェアは以下からダウンロードできます。

- VIA、Remap 用ファームウェア [./firmware/dial/sparrowdial_via.uf2](https://github.com/74th/sparrow62-buildguide/raw/refs/heads/master/firmware/dial/sparrowdial_via.uf2)

書き込みを行う領域の都合上、新たにVIA、REMAPのファームウェアをインストールしても、以前変更したキーマップの変更が残っている場合があります。その時には、[公式サイトのResetting Flash memory](https://www.raspberrypi.com/documentation/microcontrollers/raspberry-pi-pico.html#resetting-flash-memory)にあるUF2ファイル(flash_nuke.uf2)を一度インストールして、FLASHの全消去を行ってください。

### QMK Firmwareでファームウェアをビルドする場合

現在、SparrowDialキーボードはQMK Firmwareの本体には取り込まれていません。下記リポジトリに作成したファームウェアのコードがあります。

https://github.com/74th/qmk_firmware_sparrow_keyboard

QMK Firmwareの環境のセットアップについては[公式のドキュメント https://docs.qmk.fm/#/newbs_getting_started](https://docs.qmk.fm/#/newbs_getting_started)を確認ください。[日本語のドキュメント https://docs.qmk.fm/#/ja/newbs_getting_started](https://docs.qmk.fm/#/ja/newbs_getting_started)もあります

まず、リポジトリをチェックアウトしてください。QMK Firmwareのフォークとなっているため、QMK Firmwareのセットアップでチェックアウトされたgitリポジトリのremoteとして登録できます。

```sh
cd ~/qmk_firmware
git remote add sparrow https://github.com/74th/qmk_firmware_sparrow_keyboard.git
git fetch sparrow
git checkout sparrow
```

このリポジトリ上では、キーボード名`sparrowdial`として登録されています。新しいキーマップを作成するには以下を実行します。

```
qmk new-keymap -kb sparrowdial -km <keymap_name>
```

`~/qmk_firmware/keyboards/sparrowdial/keymaps/<keymap_name>`というフォルダに作成されるため、キーマップを作成します。

キーマップ作成後は、以下のコマンドでコンパイルします。

```
qmk compile -kb sparrowdial -km <keymap_name>
```

すると、`~/qmk_firmware/.build/sparrowdial_<keymap_name>.uf2`にビルドされるため、これをRP2040に書き込みます。

## トラブルシューティング

こちらのページを確認ください。

> Trouble Shooting Guide
>
> [./trouble_shooting_guide.md](./trouble_shooting_guide.md)

## Data Sheet

- [SparrowDial v1.1.0 Semantics](datasheets/SparrowDial-v1.1.0-semantics.pdf)
- [SparrowDial v1.1.0 PCB](datasheets/SparrowDial-v1.1.0-pcb.pdf)

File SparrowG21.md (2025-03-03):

# SparrowG21 Build Guide

このビルドガイドには他のキーボードの写真が含まれていますのでご注意ください。

また、作成中に疑問点等質問がありましたら、74th （twitter: [@74th](https://twitter.com/74th) 、email: site@74th.tech 、 本リポジトリの issue）まで問い合わせください。

## 販売先

- booth(準備中)

## 重要なお知らせ

### 2024/03/10

SparrowG21のキーケット1販売時に搭載していたファームウェアでは、RGB LEDが動作しないことがわかりました。下記の手順でファームウェアを更新してください。

- BOOTSELを押しながらRESETを押して、マウントされるUSBストレージに、ストレージ消去用ファームウェア [flash_nuke.uf2](https://datasheets.raspberrypi.com/soft/flash_nuke.uf2)(Raspberry Piの公式HPよりダウンロードできるものです)を書き込む。
- 再度、USBストレージがマウントされるため、[./firmware/g21/GP2040-CE_0.7.7_SparrowG21.uf2](https://github.com/74th/sparrow62-buildguide/raw/refs/heads/master/firmware/g21/GP2040-CE_0.7.7_SparrowG21.uf2)を書き込む。

## Sparrow60C の注意点

- マイコン RP2040 が直接 PCB に実装されています。
- GH60 互換キーボードケース対応の PCB ですが、必ずしもすべてのケースに対応するわけではありません。
- キットの PCB には RP2040 を動作させるためのマイコン及び受動部品が実装されています。

## キットの内容

- SparrowG21 PCB x1
- SparrowG21 Top Plate (FR4 PCB) x1
- OLED x1
- ジョイスティックモジュール B10K x2
- SH1.0-4P(Qwiic) ケーブル x1
- SH1.0-4P(Qwiic) SMD ソケット x1
- RGBLED SK6812-MINI-E x12
- M2 2mm スペーサー x6 : ケースとPCBの間の距離調整
- M2 6mm 黒 平ネジ x6 : ケースとPCBの間のネジ止め

### PCBに実装済みの部品

- マイコン RP2040 x1
- マイコンプログラム用フラッシュ W25Q32JVS x1
- RP2040 の動作に必要な受動部品（コンデンサ、抵抗、水晶発振器）
- 6x6mm SMD タクタイルスイッチ（RP2040 RESET、BOOTSEL用） x2
- 電源保護用理想ダイオード CH213K x1
- 0805 SMD 青色LED x2
- USB Type-C コネクタ x1

### トッププレートに実装済みの部品

- SH1.0-4P(Qwiic) SMD ソケット x1
- 0805 SMD 抵抗 x2
- 0805 SMD 青色LED x2

## キットの組み立てに必要なもの

### キットの他に必要なもの

本キットは、「MX互換スイッチ」もしくは「Kailh Choc v1 スイッチ/LOFREE x KAILH Full POM Low Profile スイッチ」を排他的に利用します。

#### 共通で必要なもの

- [GH60 互換キーボードケース x1](./parts.md#gh60互換ケース)
- MX互換スイッチを用いる場合
  - [MX 互換スイッチソケット x21 （MX互換スイッチを用いる場合）](./parts.md#cherrymx互換スイッチソケットkailhスイッチソケット)
  - [MX 互換スイッチ x21（MX互換スイッチを用いる場合）](./parts.md#cherrymx互換スイッチ)
  - [MX 互換スイッチ用キーキャップ一式 x1（MX互換スイッチを用いる場合）](./parts.md#cherrymx互換キーキャップ)
- Chocスイッチを用いる場合
  - [Kailh Chocスイッチ x21](./parts.md#kailh-chocスイッチ)
  - 選択したKailh Chocスイッチに対応したキーキャップ x21
- PC 接続用 USB Type-C ケーブル x1

### 組み立てに必要な機材

- はんだごて、はんだこて台、スポンジ
- はんだ
- ピンセット（表面実装部品を抑えるのに利用します）
- PC（Windows、Linux、MacOS の動作するもの。ファームウェアの作成に必要。）

### あるとよいもの

- フラックス
  - はんだにはフラックスが含まれていて、端子に広がるようにできていますが、熱を加えすぎるとすべてのフラックスが蒸発します。その場合、追加のフラックスを入れて使います
- フラックス洗浄液
- ルーペ（スマートフォンカメラでも代用できます）
- ラジオペンチ（ネジ止めの他、スイッチの足が曲がってしまった場合に、つまんで伸ばします）

## how to build / 作成方法

### Soldering the switch socket / スイッチソケットを実装する

> [!CAUTION]
> MX互換キー用ソケットを取り付けた場合には、Kailh Chocスイッチを利用することはできません。Kailh Chocスイッチを利用する場合には、ソケットを実装しないでください。

We recommend soldering the socket as shown in the video.
🇯🇵 ソケットのはんだ付けは動画のようにすることをおすすめしています。

[Movie（Google Drive）](https://drive.google.com/file/d/1VQYtKHCZkTQwoi6JiOMwTrHwYhy1caux/view?usp=sharing)

[Movie（Twitter）](https://twitter.com/74th/status/1514942328900775938)

[Movie file switch_socket.mp4](./img/62v2/switch_socket.mp4)

1. Set the socket in the correct orientation.
2. Apply heat with a soldering iron from the inside of the socket's terminals.
3. From the outside of the socket, apply solder with the soldering iron and pour the solder into the socket.
4. Remove the solder and hold the socket with tweezers.
5. remove the soldering iron

🇯🇵

1. ソケットを正しい方向にセットします。
2. ソケットの端子の内側から、はんだごてで熱を加えます
3. ソケットの外側から、はんだごてを当ててはんだを流し込みます
4. はんだを外してから、ピンセットなどでソケットを抑えます
5. はんだごてを抜きます

### Kailh Chocスイッチの実装

> [!CAUTION]
> Kailh Chocスイッチを取り付けた場合には、MX互換スイッチを利用することはできません。MX互換スイッチを利用する場合には、Kailh Chocスイッチを実装しないでください。

表面から、Kailh Chocスイッチを差し込み、裏面から実装します。かならず、写真のようにLEDのランドが見えている面ではんだ付けをするようにしてください。



### RGBLED の実装

RGBLED SK6812MINI-E の方向を注意してください。

RGBLED の実装は、PCB 裏面に裏向きにセットして実装します。
PCB 表向きから見ると、発光面が見える形になります。

また、RGBLED の 4 本の足の 1 つ GND には切れ込みが入っています。切れ込みとシルクの斜め線を合わせるようにしてください。





向きを確認できたら、一方の足をマスキングテープで留めます。



すべての足を実装します。



### Soldering SH1.0(Qwiic) sockets / SH1.0(Qwiic) ソケットの実装

SH1.0(Qwiic)ソケットを実装します。

まず、1本のピンのみを実装し、はんだごてを更にあてながらPCBのシルクの位置になるように調整します。その後、残りのピンも実装します。ケーブルを差し込む面にも下部に固定用の金属部分があるため、こちらも忘れずに実装します。



### OLEDの実装

OLEDにはVCCとGNDの位置の違いで、2種類あり、それに応じてジャンパを実装するようになっています。キットでは、同梱したOLEDによって、すでにジャンパがなされています。

以下の手順で実装します。



実装後は以下のようになります。



### ジョイスティックの実装

表面からスルーホールに差し込みます。まず、足を1本だけ実装し、奥まで刺さっていることを確認してから、残りの足を実装してください。足の実装後、余分な足の部分をニッパ出切り取ります。



### ケースへの組み込み

ケースへの組み込みは以下の手順で行います。Kailh Chocスイッチを使う場合、Top Plateは不要です。

1. ケース底面のネジ穴に対して、2mm中空スペーサーを置く
2. SparrowG21 PCBをケースに配置する
3. SparrowG21 PCBとケースのネジ止め
4. （MX互換スイッチを使う場合のみ）SparrowG21 Top PlateとSH1.0(Qwiic)ケーブルを接続し、ケースに配置する
5. （MX互換スイッチを使う場合のみ）スイッチの差し込み
6. キーキャップの差し込み
7. スティックキャップの差し込み

#### 1. ケース底面のネジ穴に対して、2mm中空スペーサーを置く

ケース底面の、各ネジ穴のところに、M2 2mm中空スペーサーを置きます。



#### 2. SparrowG21 PCBをケースに配置する

SparrowG21 PCBを載せます。ケースの上の中空スペーサーを落とさないように気をつけてください。



#### 3. SparrowG21 PCBとケースのネジ止め

付属のネジを用いて、M2 6mmネジで6箇所を留めます。中空スペーサーを落とさない様にしてください。



#### 4. （MX互換スイッチを使う場合のみ）SparrowG21 Top PlateとSH1.0(Qwiic)ケーブルを接続し、ケースに配置する

SparrowG21 PCBとTop PlateのSH1.0(Qwiic)ポートを、SH1.0(Qwiic)ケーブルで接続してください。



#### 5. （MX互換スイッチを使う場合のみ）スイッチの差し込み

Top Plateの穴から、PCBに向かってスイッチを差し込みます。MX互換スイッチには、Top Plateを挟み込む溝が付いています。この溝にTop Plateが挟まれるようにTop Plateを持ち上げてください。



この時、左右外側のスイッチから、順に固定していくと、高さをキープしやすくなります。

#### 6. キーキャップの差し込み

キースイッチへ、キーキャップを付けてください。

#### 7. スティックキャップの差し込み

ジョイスティックへ、キャップを付けてください。これで完成です！

### 実装後の確認

本キットのRP2040にはあらかじめGP2040-CEを書き込んでいます。

実際にキーを押して確認してください。

テスト画面の表示の仕方はWindowsであれば以下のサイトを参照してください。

> ゲームパッドとは？／動作確認方法は？／設定方法は？
>
> https://qa.elecom.co.jp/faq_detail.html?id=5432

GP2040-CEを新たにRP2040に書き込んだ場合には、SparrowG21用のキーアサインをやり直す必要があります。

### GP2040-CEのSparrowG21用の設定

本キットのRP2040にはあらかじめ設定したGP2040-CEを書き込んでいます。以下は、GP2040-CEのファームウェアを更新した場合や、設定を変更したい場合に参照してください。

GP2040にはWeb Configuratorがあります。Web Configuratorを起動するには、以下のように操作します。

- GP2040インストール直後: R3キー（IO17）を押しながらRESETを押す
- SparrowG21用の設定を適用後: S2キーを押しながらRESETを押す

その後、ブラウザにて [http://192.168.7.1](http://192.168.7.1)にアクセスすると開けます。

また、設定をリストアしたファイルは以下にあります。こちらを読み込ませても設定が完了します。

- [GP2040-ce v0.7.5 - SparrowG21 v1.1.0: gp2040ce-v0.7.5_sparrowg21.gp2040](https://github.com/74th/sparrow62-buildguide/raw/refs/heads/master/firmware/g21/gp2040ce-v0.7.5_sparrowg21.gp2040)
- [GP2040-ce v0.7.7 - SparrowG21 v1.1.0: gp2040ce-v0.7.7_sparrowg21.gp2040](https://github.com/74th/sparrow62-buildguide/raw/refs/heads/master/firmware/g21/gp2040ce-v0.7.7_sparrowg21.gp2040)（こちらを適用しても、Peripheral Mappingの設定が適用されないのを確認しています。Peripheral Mappingの設定は手動で行ってください）

GP2040-CEは利用するファームウェアによって、RGBLEDが有効にならない場合が確認されています。v0.7.7のPico用ファームウェアではRGBLEDが有効になりませんでした。設定ビルド済みのファームウェア [GP2040-CE_0.7.7_SparrowG21.uf2](firmware/g21/GP2040-CE_0.7.7_SparrowG21.uf2) を用意しましたので、ファームウェアのアップデートを必要としない方はこちらを利用ください。
今後のファームウェアのアップデートに対応して欲しい場合は、私（74th.tech@gmail.com、X(Twitter):@74th）の方までリクエストください。可能な範囲で対応いたします。

#### IO（ピン）ごとの機能リスト

| IO | Role |
| --- | --- |
| 0 | OLED I2C0 SDA |
| 1 | OLED I2C0 SCL |
| 2 | HAT Left Button |
| 3 | S2 Button |
| 4 | Extra (重複割り当て用)  |
| 5 | HAT Down Button |
| 6 | HAT Right Button |
| 7 | HAT UP Button |
| 8 | A1 Button |
| 9 | Turbo Button |
| 10 | Turbo LED (Active Low)  |
| 11 | A2 Button |
| 12 | Function Button |
| 13 | B3 Button |
| 14 | B1 Button |
| 15 | B4 Button |
| 16 | B2 Button |
| 17 | R3 Button |
| 18 | L3 Button |
| 19 | R1 Button |
| 20 | R2 Button |
| 21 | L1 Button |
| 22 | L2 Button |
| 23 | S1 Button |
| 24 | RGB LED Data |
| 25 | Board LED (Active High) |
| 26(ADC0) | Analog1 X |
| 27(ADC1) | Analog1 Y |
| 28(ADC2) | Analog2 X |
| 29(ADC3) | Analog2 Y |

#### Pin Mapping

各スイッチと繋がるピンの設定です。

ヘッダーの「Configuration」から「Pin Mapping」を開いてください。

それぞれのピンを以下のように設定してください。v0.7.7では、IOから機能を設定する様に変わりました。

| IO | Role |
| --- | --- |
| 0 | None/Assigned to addon (OLED I2C0 SDA) |
| 1 | None/Assigned to addon (OLED I2C0 SCL) |
| 2 | HAT Left Button |
| 3 | S2 Button |
| 4 | 任意 (重複割り当て用) |
| 5 | HAT Down Button |
| 6 | HAT Right Button |
| 7 | HAT UP Button |
| 8 | A1 Button |
| 9 | Turbo Button |
| 10 | None/Assigned to addon (Turbo LED) |
| 11 | A2 Button |
| 12 | Function Button |
| 13 | B3 Button |
| 14 | B1 Button |
| 15 | B4 Button |
| 16 | B2 Button |
| 17 | R3 Button |
| 18 | L3 Button |
| 19 | R1 Button |
| 20 | R2 Button |
| 21 | L1 Button |
| 22 | L2 Button |
| 23 | S1 Button |
| 24 | None/Assigned to addon (RGB LED) |
| 25 | None (Board LED) |
| 26(ADC0) | None/Assigned to addon (Analog1 X) |
| 27(ADC1) | None/Assigned to addon (Analog1 Y) |
| 28(ADC2) | None/Assigned to addon (Analog2 X) |
| 29(ADC3) | None/Assigned to addon (Analog2 Y) |

設定後、Saveを押してください。



v0.7.5のスクリーンショット

#### Peripheral Mapping

v0.7.7ではOLEDで使用するI2Cのピンの設定はPeripheral Mappingで行います。以下のように設定してください。

| Setting Name | Value |
| --- | --- |
| I2C &gt; I2C0 | ON |
| I2C &gt; I2C0 &gt; SDA | 0 |
| I2C &gt; I2C0 &gt; SCL | 1 |
| I2C &gt; I2C0 &gt; Speed | Normal - 100000 |



#### LED Configuration

各スイッチのLEDの設定です。

ヘッダーの「Configuration」から「LED Configuration」を開いてください。

以下を設定します。設定後、Saveを押してください。

| Setting Group Name | Setting Name | Value |
| --- | --- | --- |
| RGB LED Configuration | Data Pin | 24 |
| | LED Format | RGB |
| | LED Layout | 8-Button Layout |
| | LEDs Per Button | 1 |



#### Display Configuration

中央のOLEDの設定です。

ヘッダーの「Configuration」から「Display Configuration」を開いてください。

以下を設定します。設定後、Saveを押してください。

| Setting Name | Value |
| --- | --- |
| Enabled | Enabled  |
| I2C Block | i2c0 |
| SDA Pin(v0.7.7以降はPeripheral Mappingで設定) | 0 |
| SCL Pin(v0.7.7以降はPeripheral Mappingで設定) | 1 |
| I2C Address | 0x3C |
| I2C Speed(v0.7.7以降はPeripheral Mappingで設定) | 400000 |
| Flip Display | None |
| Invert Display | Disabled |



#### On-Board LED Configuration

SparrowG21のロゴの右側のLEDの設定です。

ヘッダーの「Configuration」から「Add-Ons Configuration」を開いてください（以降の設定はすべてAdd-Ons Configurationです）。

「On-Board LED COnfiguration」と書かれたパネルの「Enabled」をオンにしてください。LED Modeはお好みのものを設定してください。設定後、最下部のSaveを押してください。



#### Analog

2つのジョイスティックの設定です。

ヘッダーの「Configuration」から「Add-Ons Configuration」を開いてください。

「Analog」と書かれたパネルの「Enabled」をオンにして、設定項目に以下の設定をしてください。設定後、最下部のSaveを押してください。

| Setting Name | Value |
| --- | --- |
| Analog Stick 1 X Pin  | 26 |
| Analog Stick 1 Y Pin  | 27 |
| Analog Stick 1 Mode | Left Analog  |
| Analog Stick 1 Invert | None |
| Analog Stick 2 X Pin  | 28 |
| Analog Stick 2 Y Pin  | 29 |
| Analog Stick 2 Mode | Right Analog |
| Analog Stick 2 Invert | None |
| Deadzone Size | 5 |



#### Turbo

連射機能の設定です。

ヘッダーの「Configuration」から「Add-Ons Configuration」を開いてください。

「Turbo」と書かれたパネルの「Enabled」をオンにして、設定項目に以下の設定をしてください。設定後、最下部のSaveを押してください。

| Setting Name | Value |
| --- | --- |
| Turbo Pin(v0.7.7以降はPin Mappingで設定) | 9 |
| Turbo Pin LED | 10 |
| Turbo Shot Count（連射速度） | お好みで |
| Turbo Dial | none |

#### Extra Button Configuration

> ![!NOTE]
> この機能はv0.7.7から削除されました。Pin Mappingで、複数のキーに同一のボタンを割当可能になりました。

追加ボタン（Down、RIGHT、S2ボタンに挟まれたEXTRAボタン）の設定です。任意のボタンを左手にも割り当てることができます。

ジャンプアクションゲームでDownキーを割り当て、従来のDown（IO5）にUp、従来のUp（IO7）にB1を割り当てたりして、左手親指でジャンプする操作を想定しています。

ヘッダーの「Configuration」から「Add-Ons Configuration」を開いてください。

「Extra Button Configuration」と書かれたパネルの「Enabled」をオンにして、設定項目に以下の設定をしてください。設定後、最下部のSaveを押してください。

| Setting Name | Value |
| --- | --- |
| Extra Button Pin | 4 |
| Extra Button（機能させるキー） | Downなどお好みで |

## トラブルシューティング

こちらのページを確認ください。

> Trouble Shooting Guide
>
> [./trouble_shooting_guide.md](./trouble_shooting_guide.md)

## Data Sheet

- [SparrowG21 v1.1.1 Semantics](datasheets/SparrowG21-v1.1.1-semantics.pdf)
- [SparrowG21 v1.1.1 PCB](datasheets/SparrowG21-v1.1.1-pcb.pdf)

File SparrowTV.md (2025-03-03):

# SparrowTV Build Guide



このビルドガイドには他のキーボードの写真が含まれていますのでご注意ください。

また、作成中に疑問点等質問がありましたら、74th （twitter: [@74th](https://twitter.com/74th) 、email: site@74th.tech 、 本リポジトリの issue）まで問い合わせください。

## 販売先

- booth(準備中)

## SparrowTV の注意点

- iPhone SE2ケース応のPCBですが、必ずしもすべてのケースに対応するわけではありません。
- ファームウェアは、CircuitPythonを用いた独自のファームウェアを利用します。QMK等の既存のファームウェアは利用できません。
- コードの変更なしに機能を変更する機能はありません。ファームウェアのコードの変更が必要です。

## キットの内容

- SparrowTV PCB x1
- 0805 SMD コンデンサ 100nF x8
- 0805 SMD コンデンサ 1uF x3
- 0805 SMD コンデンサ 10uF x2
- 0805 SMD 抵抗 1Ω x1
- 0805 SMD 抵抗 27Ω x1
- 0805 SMD 抵抗 1kΩ x2
- 0805 SMD 抵抗 5.1kΩ x2
- 0805 SMD 抵抗 10kΩ x4
- 0805 SMD 抵抗 42kΩ x1
- HY2.0-4P(Grove) SMD ソケット x1
- RGBLED SK6812-MINI-E x15
- SOD-123 ダイオード 1N4148W x15
- USB-C ミッドマウントソケット x1（実装済みの場合もあり）
- 2x3p ボックスピンヘッダ x1
- ジョイスティック B10K x1
- SOT-223 レギュレータ AMS1117-3.3 x1
- SOT-23-6 USB電源スイッチIC CH217K x1
- WiFiモジュール ESP32-C3-WROOM-02
- SSOP-20 MCU CH32V003F4P6 x1
- SOIC-16 UART-To-USBキーボード変換IC WCH9329
- 熱伝導テープ x1
- ESP32-C3-WROOM-02 技適シール x1

## キットの組み立てに必要なもの

### キットの他に必要な部品

- [Kailh Chocスイッチ x15](./parts.md#kailh-chocスイッチ)
- [Kailh Chocスイッチ用ソケット x15](./parts.md#kailh-chocスイッチソケット)
- [Kailh Chocスイッチ用キーキャップ x15](./parts.md#kailh-choc-v1キーキャップ)
- [M5Stack用赤外線送受信ユニット x1](./parts.md#m5stack用赤外線送受信ユニット)
- Groveケーブル（M5Stack用赤外線送受信ユニットに付属） x1
- iPhone SE 2 or 3ケース x1

### 組み立てに必要な機材

- USBシリアル変換
  - [秋月電子通商で販売されている AE-CH340E-TYPEC](https://akizukidenshi.com/catalog/g/g114745/)
  - 74th の販売する ESP32-Writer
  - Espressif ESP-Prog など
- はんだごて、はんだこて台、スポンジ
- はんだ
- フラックス
  - はんだにはフラックスが含まれていて、端子に広がるようにできていますが、熱を加えすぎるとすべてのフラックスが蒸発します。その場合、追加のフラックスを入れて使います
- テスター
- ピンセット（表面実装部品を抑えるのに利用します）
- PC（Windows、Linux、MacOS の動作するもの。ファームウェアの作成に必要。）

### あるとよいもの

- フラックス洗浄液
- ルーペ（スマートフォンカメラでも代用できます）
- ラジオペンチ（ネジ止めの他、スイッチの足が曲がってしまった場合に、つまんで伸ばします）
- WCH-LinkE（CH32V003F4P6のプログラムが書き換え可能）

## 組み立て方法

以下の順序で組み込みを行います。

1. USB-C ソケット
2. コンデンサ、抵抗、ダイオード等の受動部品
3. RGBLED
4. レギュレータ、CH217K
5. CH32V003、CH9329
6. ESP32-C3-WROOM-02
7. スイッチソケット、HY2.0コネクタ、ボックスピンヘッダ

### 1. USB-C ソケット

最初にUSB-Cコネクタを実装するのは、USB-Cコネクタが最もブリッジしやすいため、実装後に以下のそれぞれのランド間にテスターを当てて抵抗値を計り、ブリッジしていないことを確認してください。

- 5V: U5(CH217K) 6ピンのランド
- GND: U5(CH217K) 2ピンのランド
- D+: U4(CH9329) 12ピンのランド
- D-: U4(CH9329) 13ピンのランド
- CC1: R7(抵抗) USB-Cソケット寄りのランド
- CC2: R6(抵抗) USB-Cソケット寄りのランド

※ 一部のPCBにはあらかじめUSB-Cコネクタが実装済みになっています。

### 2. コンデンサ、抵抗、ダイオード等の受動部品

部品の対応表は、下記リポジトリを確認ください。

> https://github.com/74th/tv-side-keyboard-SparrowTV

ダイオードは向きを間違えないように気をつけてください。



### 3. RGBLED

RGBLED SK6812MINI-E の方向を注意してください。

RGBLED の実装は、PCB 裏面に裏向きにセットして実装します。
PCB 表向きから見ると、発光面が見える形になります。

また、RGBLED の 4 本の足の 1 つ GND には切れ込みが入っています。切れ込みとシルクの斜め線を合わせるようにしてください。



向きを確認できたら、一方の足をマスキングテープで留めます。



すべての足を実装します。



### 4. レギュレータ、CH217K

部品表に従って、実装してください。ブリッジした場合も、フラックスを足して、再度はんだごてを当てて取り除くようにしてください。

### 5. CH32V003、CH9329

IC上のマーキングを確認し、まず対角の2ピンだけを実装して、位置を適切にした上で、残りのピンを実装するようにしてください。

CH32V003は若干熱で壊れやすい様に思うため、熱の当てすぎに気をつけてください。

位置が定まらないときは、細く切ったマスキングテープで固定するのも手です。

### 6. ESP32-C3-WROOM-02

モジュールの裏には放熱用のランドが付いています。この場所に熱伝導テープを貼り、PCBに１２機を付けながら貼り付けてください。

モジュールを上から押さえつけながら、ランドとモジュール間を実装してください。

実装後にモジュールを横から眺めてみて、ランドとモジュールが確かにはんだで溶接されているか確認してください。よくいくつかのピンが浮いていることがあります。

また、ESP32-C3-WROOM-02は、少し熱に弱いように思うため、はんだごての当てすぎに気をつけてください。

上手く位置が固定できない特には、マスキングテープでPCBに固定するのも手です。

### 7. スイッチソケット、HY2.0コネクタ、ボックスピンヘッダ

残りのソケット等を実装してください。

HY2.0コネクタには、ケーブルを差し込む面にも下部に固定用の金属部分があるため、こちらも忘れずに実装してください。

## ファームウェアの書き込みと、動作確認

### USBの接続確認

USBコネクタはESP32-C3-WROOM-02ではなく、CH9329に接続されています。PCと接続すると、USBキーボードとして認識します。USBキーボードとして認識することを確認してください。

### CircuitPythonの確認とファイルのアップロード

販売しているキットには、あらかじめCircuitPythonをESP32-C3に書き込んであります。ESP32C3のCircuitPythonはUARTからアクセスします。

USBⅡ接続して電源を供給した状態であれば、ESP-ProgポートのTXD、RXD、GNDをUSBシリアル変換アダプタと接続します。
WindowsならばTeraTerm、MacOS、Linuxならばminicom等を使うことで、CircuitPythonのコンソールにアクセスできます。

CircuitPythonを再度インストールする必要がある場合には、ESP32の書き込み方法を調べてみてください。EN、IO0を制御することで書き込みを行うことができます。CircuitPythonには複数のESP32-C3対応ボード用のファームウェアが存在していますが、"ESP32-C3-DevKitM-1-N4"のものを利用してください。

CircuitPythonへ編集したファイルを書き込むには、WiFi経由でアップロードすることができます。UARTを繋いだときに、一度Ctrl+C & Enterを押してPythonコンソールに入り、以下のように入力して、settings.toml を作る必要があります

```python
f = open('settings.toml', 'w')
f.write('CIRCUITPY_WIFI_SSID = "ssid-name"\n')
f.write('CIRCUITPY_WIFI_PASSWORD = "wifi-password"\n')
f.write('CIRCUITPY_WEB_API_PASSWORD = "webui-password"\n')
f.close()
import microcontroller; microcontroller.reset()
```

すると、起動時のシーケンスを見ると「NO IP」からIPアドレスの表示に変わります。そのIPアドレスに、一度Ctrl+C & Enterを押してPythonコンソールが表示される状態の時に、IPアドレスにブラウザからアクセスするとファイルブラウザを見ることができます。
そこから更新することができます。

ファームウェアは以下のリポジトリのPythonコードです。

> https://github.com/74th/tv-side-keyboard-SparrowTV/tree/main/firmware-circuitpython

このリポジトリ中では、タスクランナーとしてinvokeを利用しており、invoke.yamlに以下のように書き込むと、invokeからcurlコマンドを呼び出し、アップロードが可能です。なお、Linuxでしか動作を確認しておりませんが、MacOSでも動作すると思われます。Windowsの方はWSLを利用してみてください。

```
# invoke.yaml
circuitpy_hostname: 192.168.1.199
circuitpy_web_api_password: webui-password
```

invokeでのコマンド

```sh
# invoke/__init__.py にコードがある
# ライブラリのアップロード
inv -e upload-libs
# プログラムのアップロード
inv -e upload-codes
# コンフィグのアップロード
inv -e upload-config
```

アップロード後、REPLから再起動を促すには、Ctrl+Dを押してください。

## キーアサインや、IRの命令を変更する

キーアサインなどは config/config.py に実装があります。

### 赤外線パルス config/ir_pulse.py

パルスデータをこのファイルにリストの形で記述します。

リモコンの赤外線を受信して、パルスデータを作るためには、ir.py に test_receive() と言う関数があるので、これをPythonコンソールから実行すると、行うことができます。

コンソールにてCtrl+Cを押して、REPLに戻った上で、以下を実行してみてください。実行して、M5IRモジュールに赤外線リモコンの信号を送ると、リストで表示されます。

```python
import ir
ir.test_receive()
```

また、屋内の環境によっては不要なノイズが混入することがあります。何度か試してみてください。

後ほど、WebServerをCircuitPythonで立ち上げて、curlでコマンドを叩くと、このモードが使えるように改修する予定です。

### キーマップ config/config.py

config/config.py はキーの機能を定義し、キーにアサインします。

現在は以下の命令が使用可能です。命令のリストは、action_codes.py に定義されています。

- `CM_SEND_IR`: 赤外線信号の送信。ペイロードには赤外線パルスを設定。
- `CM_TYPE_KEY`: キーボードのキーのタイプ。ペイロードには、単一のキーコード、もしくはキーコードの配列を設定する。キーコードの配列の場合
- `CM_TYPE_TEXT`: キーボードのキーをテキストで連続入力する。ペイロードにはstrを設定。
- `CM_LED_XY`: 指定箇所のLEDの色を変更する。ペイロードには`(r, g, b)`で0-255の値を設定。
- `CM_MOUSE_LEFT`: マウス左ボタン
- `CM_MOUSE_RIGHT`: マウス右ボタン
- `CM_MOUSE_WHEEL`: マウスホイールボタン

これからキーの機能を定義します。

```python
# 赤外線を送信する
KC_TV_POWER: KeyAssign = (CM_SEND_IR, ir_pulse.TV_POWER)
# キーボードのキーにする
KC_ESC: KeyAssign = [(CM_TYPE_KEY, 243)] # ESC
KC_CTRL_W: KeyAssign = [(CM_TYPE_KEY, [87, 17])] # Ctrl-W
# マウスのボタンにする
KC_MOUSE_L = CM_MOUSE_LEFT
```

これを、3x5の配列にして、`LAYER1`変数に定義します。

```py
LAYER1: Layer = [
    [KC_TV_POWER,        KC_TV_CURSOR_BACK, KC_TV_CURSOR_UP,   KC_TV_CURSOR_OK,    KC_A],
    [KC_TV_CHANGE_INPUT, KC_TV_CURSOR_LEFT, KC_TV_CURSOR_DOWN, KC_TV_CURSOR_RIGHT, KC_A],
    [KC_MOUSE_L,         KC_MOUSE_R,        KC_CTRL_W,         KC_ESC,             KC_A],
]
```

LEDの色を変更するには、LAYER1_LEDⅡ定義します。

```py
LAYER1_LED: LayerLED = [
    [L_RED, L_YELLOW, L_WHITE, L_PURPLE, L_PURPLE],
    [L_GREEN, L_WHITE, L_WHITE, L_WHITE, L_PURPLE],
    [L_CYAN, L_CYAN, L_GREEN, L_GREEN, L_PURPLE],
]
```

※ 現在レイヤー機能は実装されていません

## Appendix

### CH32V003のI2Cのプロトコル

詳しくは、firware-circuitpython/ui.py に処理するコードがあるので見てみてください。

> https://github.com/74th/tv-side-keyboard-SparrowTV/blob/main/firmware-circuitpython/ui.py

常に9バイト受信します。各バイト配下の通りです。

- 0: マウスのxの負の移動量
- 1: マウスのxの正の移動量
- 2: マウスのyの正の移動量
- 3: マウスのyの負の移動量
- 4: 常に0
- 5: 1列目の、各列番号のbitが、押されていると1、押されていないと0になる
- 6: 2列目の、各列番号のbitが、押されていると1、押されていないと0になる
- 7: 3列目の、各列番号のbitが、押されていると1、押されていないと0になる

### CH9329のプロトコル

ESP32-C3とCH9329はUARTで通信して、USBキーボード、マウスを実現しています。

CH9329については、拙著『WCHのICを活用する電子工作の本』でも紹介しています。

また、みんなのラボさんの同人誌『キーボード／マウス　エミュレータ解説書』に詳しく解説があります。この機会にぜひ利用してみてください。

## Data Sheet

- [SparrowTV v1.2.0 Semantics](datasheets/SparrowTV-v1.2.0-semantics.pdf)
- [SparrowTV v1.2.0 PCB](datasheets/SparrowTV-v1.2.0-pcb.pdf)

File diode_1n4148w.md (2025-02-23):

# ダイオード1N4148Wの実装方法

1N4148Wの実装手順を説明します。

まず、方向に注意してください。
IC中のマーキングは見にくい場合があります。
ライトを当てたり、スマホのカメラ機能を使って拡大してみてみてください。
手元を明るくして作業すると良いでしょう。



片方のランドに、よびはんだとして、はんだを溶かして載せます。



片手でピンセットで部品を抓み、はんだごてではんだを溶かし、部品をスライドする様にして実装します。



全ての部品を一度片方の足のみ実装しましょう。
実装後に、全てのダイオードの向きを確認してください。

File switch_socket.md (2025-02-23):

# スイッチソケットの実装方法

まず、Kailh Chocソケットには向きがあります。
以下の記事を参考にしてください。

https://www.eisbahn.jp/yoichiro/2021/01/kailh_choc_v1_socket.html

実装の方法を説明します。

まず、ソケットを基板にセットします。
金属部分にはんだごてを当てて、温めてはんだを溶かします。
すぐにははんだごてを抜かずに、ソケットの金属と基板のランドの両方を加熱して、はんだが両方に回るのを確認します。
そして、ソケットが浮かないようにピンセットで押さえてから抜きます。
加熱しているので金属に触ってしまうと、火傷してしまうため注意してください。

以下に動画を含めています。

[実装の動画 ./img/common/solder_switch_socket.mp4](./img/common/solder_switch_socket.mp4)

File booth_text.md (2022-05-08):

# Sparrow62(+1) v2 自作キーボードキット

## リード

Raspberry Pi PICO を使った、左右分離、縦に揃ったキーを持つ自作キーボードキットです。

本商品は、完成品の販売ではなく、ご自身で組み立てするキットの販売です。
完成を保証するものではありません。

自作キーボードのファームウェアで有名な QMK Firmware、Remap は、現在のところ使用できません。

現在、以下を使ったファームウェアをサポートしています。

・KMK Firmware

名称は Sparrow62 ですが、Sparrow62 v2 では 63 キーで構成されます。

## 特徴

- 縦に揃ったキー配置（カラムスタッガード）であり、指の曲げ伸ばしで多くのキーに届く様になっていること。
- 左右分離しており、肩を開いてタイピングができること。
- CherryMX 互換キースイッチが使えること。
- 薄型キースイッチ Kailh Choc v1/v2 が使えること。
- キースイッチが交換可能なようにスイッチソケットを使えること。
- 数字キーを網羅できるほどキーの数が多いこと（60%キーボード）。
- (v2) 標準的なキーキャップセットを使用して、組み立てることができること。
- (v2) 右手のキーボードの右側にマウスなどを配置できるように、右手の右側のキーの数を抑え、左側が膨らむデザインであること。
- オプションで、トラックパッドを右手左側に置くことができること。
- ゴム足の代わりに、ゴムシートを使うことで十分薄くすることができること。
- (v2) 厚さの異なるプレート、PCB を用いて可能な限り薄くしていること。
- (v2) PCB とゴムシートの間にプレートをはさみ、全体の剛性と、打鍵感を高めてあること。
- (v2) 半導体不足でも入手の容易で、高性能な Raspberry Pi PICO （以下、PICO） を用いること。
- (v2) マイコン 1 つで左右のキーボードを制御すること。
- (v2) USB Type-C で接続できること。

## 組み立てについて

ご自身で組み立て可能か、ビルドガイドを確認ください。

https://github.com/74th/sparrow62-buildguide/

組み立てには、キット以外にも追加の部品や、工具が必要です。ビルドガイドを確認ください。

https://github.com/74th/sparrow62-buildguide/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

追加で必要な部品は主に以下の 6 点です。

- Raspberry Pi PICO x1
- 対応自作キーボードスイッチ x63
- Kailh スイッチソケット x63
- PCB マウントスタビライザー（CherryMX 五感スイッチの場合のみ） x4
- TRRS ケーブル x1
- PC 接続用 USB Type-C ケーブル x1

## トラックパッドオプションについて

CherryMX 互換スイッチと高さを合わせるためのトラックパッド用の台がオプションになっています。
Apple Magic Trackpad に適切なサイズになっています。

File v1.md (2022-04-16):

# Sparrow 62 Keyboard Building Guide

## What's Sparrow 62 Keyboard

Sparrow62 is the DIY Keyboard kit inspired by Lily58.

Lily58 に触発された @74th が販売する、自作キーボードキットです。

**using Kailh Choc V2 switches（keycap: DSA）**



### features

- able to use thin switches, Kailh Choc v1/v2 （薄型キースイッチ Kailh Choc V1/V2 が使えること）
- able to use Cherry MX compatible switches （CherryMX 互換キースイッチが使えること）
- aligned vertically (縦に揃ったキー配置(カラムスタッガード)であること）
- enough number of keys（十分キーの数が多いこと）
- placing the Pro Micro next to the keys to make the keyboard itself thinner （Pro Micro をキーの横に配置してキーボード自体を薄くすること)
- using a socket to be able to replace switches (キースイッチ交換可能なようにソケットを使うこと)

As a more complete keyboard that is easier to make, there is Lily58 distributed by @F_YUUCHI. Please consider purchasing Lily58.
（より作りやすい、完成度の高いキーボードとして、ゆーちさんの頒布されている Lily58 があります。 ぜひ Lily58 の購入も検討ください。）

**Kailh Choc V1 キースイッチの場合**


**Cherry MX 互換スイッチを使用し、トッププレートを加えた場合（キーキャップ: DSA）**


## additional items

The additional items required are as follows.
（追加で以下のものが必要です。）

### For Kailh Choc v1/2 switches set（薄型キースイッチ Kailh Choc v1/2 セットの場合）

- Kailh switch socket for Kailh Choc switches（Choc スイッチ用ソケット） x62
- Kailh Choc switch v1/v2 x62
- TRRS Cable x1
- Pro Micro (ATMega 32U4) x2
- USB Cable for Pro Micro x2

### For CherryMX Compatible switches set（CherryMX 互換スイッチの場合）

- Kailh switch socket for Cherry MX Compatible switches（CherryMX 互換スイッチ用ソケット） x62
- Cherry MX Compatible switches x62
- TRRS Cable x1
- Pro Micro (ATMega 32U4) x2
- USB Cable for Pro Micro x2

### For CherryMX Compatible switches with Trackpad set（CherryMX 互換スイッチトラックパッド対応用の場合）

- Kailh switch socket for Cherry MX Compatible switches（CherryMX 互換スイッチ用ソケット） x58
- Cherry MX Compatible switches x58
- TRRS Cable x1
- Pro Micro (ATMega 32U4) x2

### 購入できるストア

- スイッチ用 PCB ソケット x62 （以下のいづれか）
  - MX 互換スイッチ用 ([遊舎工房](https://yushakobo.jp/shop/a01ps/)、[TALP KEYBOARD](https://talpkeyboard.stores.jp/items/5e02c5405b120c792616bcf9))
  - Kailh Low Profile Choc V1/V2 用 ([遊舎工房](https://yushakobo.jp/shop/a01ps/))
- TRRS ケーブル、もしくは 3.5mm ステレオミニプラグオーディオケーブル x1 ([遊舎工房](https://yushakobo.jp/shop/trrs_cable/)、[Amazon](https://www.amazon.co.jp/dp/B018FPYC78))
- Pro Micro x2 ([遊舎工房](https://yushakobo.jp/shop/promicro-spring-pinheader/)、[TALP KEYBOARD](https://talpkeyboard.stores.jp/items/5b24504ba6e6ee7ec60063e3))
- Pro Micro 用コンスルー x2 (遊舎工房 Pro Micro に付属、[TALP KEYBOARD](https://talpkeyboard.stores.jp/items/5e056626d790db16e2889233))

## how to build

### if using Kailh Choc V2, remove 1 foot

Kailh Choc v2 を使うの場合、足を 1 本切断する

Kailh Choc V2 has three copper wireand one of the red circles in the photo is cut with nippers.

Kailh Choc V2 では銅線の足が 3 つ出ていますが、このうち写真赤丸の 1 本をニッパで切断します。
切断した際に発生する小さな破片にご注意ください。
写真青丸の銅線は切断しないように気をつけてください。



ここできれいに切断すると、安定性が増します。
もし少し残ってぐらついてしまう場合、補助的にトッププレートを使うことで安定させることもできます（ただし、Choc スイッチの下の爪と上の爪までの幅が 1.65mm であるため、完全にははまりません）。
[後からトッププレートが必要となった場合、遊舎工房さんで発注することができます。こちらを確認ください。](https://github.com/74th/sparrow62-buildguide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)

### Pro Micro anti-scratch processing

Pro Micro にもげ防止加工を実施（お好みで）

The Pro Micro's Micro USB port is extremely fragile.
To prevent this, apply an evoxy adhesive to the terminals.
Be careful not to accidentally get the adhesive inside the terminals.

Pro Micro の Micro USB 端子は非常にもげやすいものになっています。
これを防止するため、端子に エボキシ系接着剤を塗布します。
誤って端子の中に接着剤が入り込まないように気をつけてください。



### Solder Pro Micro and pin header (if you using mac8 pin header)



#### コンスルーピンヘッダを使用する場合

Pro Micro とピンヘッダをはんだ付けする

ピンヘッダには向きがあります。詳しくは、遊舎工房の解説を確認ださい。

https://yushakobo.zendesk.com/hc/ja/articles/360044233974-%E3%82%B3%E3%83%B3%E3%82%B9%E3%83%AB%E3%83%BC-%E3%82%B9%E3%83%97%E3%83%AA%E3%83%B3%E3%82%B0%E3%83%94%E3%83%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

Sparrow62 キーボードは Pro Micro を写真の向きで使います。

先に、Pro Micro とピンヘッダを PCB に差し込みます。
その上から、 Pro Micro とピンヘッダのみをはんだづけします。
ピンヘッダと PCB ははんだ付けしないようにします。

Pro Micro は脆弱な部品ため、破損した場合交換が可能となります。

### Solder Diodes

Solder the diode, paying attention to the orientation of the diode.
ダイオードを向きを気をつけて、はんだ付けします。

The video by @Salicylic_acid3 is very good, so I think you can check here.
実装手順については、サリチル酸さんのツイートの動画が非常に良くできているため、こちらを確認いただくと良いと思います。

https://twitter.com/Salicylic_acid3/status/1296494976319315970
https://twitter.com/Salicylic_acid3/status/1108798243142434816

**1. Solder one side of the PCB first (先に PCB の片側にはんだをつける)**



**2. Melt the attached solder and solder the diode on one side (つけたハンダを溶かして、ダイオードを片側をはんだ付けする)**



**3. Check the orientation of the diode (ダイオードの向きを確認する)**



**4. Solder the other side (反対側の足をはんだ付けする)**



### Solder switch socket (スイッチソケットを実装する)

The video by @Salicylic_acid3 is very good, so I think you can check here.
実装手順について、こちらもサリチル酸さんのツイートの動画がよくできているため、こちらを確認いただくのが良いと思います。

https://twitter.com/Salicylic_acid3/status/1310253635255717889

**1. Solder the pads on both sides of the PCB(先に PCB の両側の端子にハンダをつける)**



**2. Place the socket and push while melting the solder(ソケットを置き、ハンダを溶かしながら押す)**



**3. Do the same on the other side(反対側も同様にする)**



**4. Repeat until they are in close contact (密着するまでくりかえす)**



### Implement tact switch

タクトスイッチを実装する

The tactile switches are **implement on a different surface than the diode**.
タクトスイッチは、**ダイオードとは異なる面に** 実装します。

The surface to be soldered is **the same surface as the diode**.
足が裏面に出るため、はんだ付けを行う面は **ダイオードと同じ面** です。

**tactile switch(タクトスイッチ)**



### Implement TRRS socket

TRRS ジャックを実装する

The TRRS sockets are **implement on a different surface than the diode**.
TRRS ジャックは、**ダイオードとは異なる面に** 実装します。

The surface to be soldered is **the same surface as the diode**.
足が裏面に出るため、はんだ付けを行う面は **ダイオードと同じ面** です。

**TRRS Socket(TRRS ジャック)**



### Assemble the top and bottom plate

トッププレートとボトムプレートを組み立てる。

#### For Kailh Choc Switches

Attach the bottom plate to the PCB with double-sided tape.
両面テープで PCB とボトムプレートを貼り付けてください。 貼り付けなくても、うまくはまれば固定されます。

#### For Cherry MX Compatible Switches



#### For Cherry MX Cpmpatible Switches with Trackpad





### Cut and attach rubber sheets with double-sided tape

両面テープでボトムプレートとゴムシートを接着します。

For trackpad, use a long rubber sheet.
トラックパッドがある場合、より長いシートをトラックパッド用に使ってください。





### Insert switches and Pro Micro

キースイッチと Pro Micro をソケットに差し込みます。

### flash QMK Firmware

#### using QMK Toolbox and REMAP

[Download sparrow62_via.hex](https://github.com/74th/sparrow62-buildguide/raw/master/sparrow62_via.hex)

Download and install QMK Toolbox.

https://github.com/qmk/qmk_toolbox/releases

Flash via firmware.

- Local File: sparrow62_via.hex
- MCU : atmega32u4

You can use REMAP for configuring your keymap.

https://remap-keys.app/

#### using QMK Firmware

```
qmk flash -kb sparrow62 -km default
```

## hints for Japanese

VIA を使う場合、QMK Toolbox でファームウェアを書き込めば完了です。

キーマップのカスタマイズには、VIA を使うと GUI で変更できます。
更に高度なカスタ合図を行う場合、QMK Firmware のビルド環境を整える必要があります。

#### QMK Toolbox を使ってデフォルトのファームウェアを書き込む

以下のキーマップを、default のファームウェアとして提供しています。

- [Download sparrow62_default.hex](https://github.com/74th/sparrow62-buildguide/raw/master/sparrow62_default.hex)

レイヤ 1



レイヤ 2（レイヤ 1 の`MO(1)`のキーと同時に押すと、動作する）



こちらを [QMK Toolbox](https://github.com/qmk/qmk_toolbox/releases) を使って書き込むことができます。

QMK Toolbox の使い方は[サリチル酸さんの記事](https://salicylic-acid3.hatenablog.com/entry/qmk-toolbox)が詳しいため、こちらを確認ください。

左右のキーボードの両方に書き込む必要があります。

#### VIA を使ってキーマップを変更する

GUI でキーマップを変更できる [VIA](https://caniusevia.com/) というツールがあります。

VIA を使うには、VIA のファームウェアを書き込む必要があります。以下からダウンロードし、[QMK Toolbox](https://github.com/qmk/qmk_toolbox/releases)などを使って書き込んでください。

- [Download sparrow62_via.hex](https://github.com/74th/sparrow62-buildguide/raw/master/sparrow62_via.hex)

VIA のファームウェアは Remap を使うと、ブラウザの UI でキーマップの変更ができます。

#### 更にカスタマイズするため、QMK Firmware のビルド環境を整える

QMK Firmware のセットアップ手順（[公式英語](https://docs.qmk.fm/#/newbs_getting_started)、[有志日本語](https://github.com/shelaf/qmk_firmware/blob/master/docs/ja/newbs_getting_started.md)）に従い、インストールします。

Ubuntu を使用している場合には、ModemManager が邪魔をすることがあるので、`sudo systemctl stop ModemManager.service`を実行いておくと有効です。

デフォルトのキーマップをインストールするには、PC と Pro Micro を USB ケーブルで接続し、以下を実行します。

```
qmk flash -kb sparrow62 -km default
```

`Detecting USB port, reset your controller now...`と表示されたところで、キーボードのタクトスイッチ（リセット）を押します。
この Firmware の書き込みを、左右 2 つの Pro Micro で両方とも行います。

この default のキーマップは以下のようになっています。 `MO(_FN)`のキーを押すと、キーレイヤが下の`[_FN]`のものに変わり、F1-12 キーや、矢印キーとして動作させることができます。



新しいキーマップを作成する場合には、以下のように実行します（nnyn が新しいキーマップ名）

```
qmk new-keymap -kb sparrow62 -km nnyn
```

キーマップの設定する C のソースが `~/qmk_firmware/keyboards/sparrow62/keymaps/nnyn/keymap.c` にできます。
こちらを変更して、以下のコマンドで Firmware を書き込みます。

```
qmk flash -kb sparrow62 -km nnyn
```

詳しいファームウェアの実装方法は、公式のドキュメントや Qiita の記事を参照ください。

- [Keymap Overview](https://docs.qmk.fm/#/keymap)
- [はじめての QMK キーマップ編集](https://qiita.com/marksard/items/9317949ce1da327f7436)

### キースイッチのテストをする

QMK Continuator のキーテストを開きます。

https://config.qmk.fm/#/test

キースイッチを押し、キーレイアウトの通りに動作するかを確認します。

### 動作しないキーがある場合

#### 1 キーのみ動作しない場合

まず、キースイッチの足が曲がっていないか確認してください。

左手用のキーの場合、以下の同じ色の部分がつながっています。それぞれテスターなどで疎通しているか確認ください。



右手用のキーの場合、以下の同じ色の部分がつながっています。それぞれテスターなどで疎通しているか確認ください。



#### 縦一列、横一列が動作しない場合

青丸が COL のラインとなっており、そのまま Pro Micro の COL0-6 につながっています。緑丸が ROW のラインとなっており、そのまま Pro Micro の ROW0-4 につながっています。
Pro Micro の接続を確認ください。

## Contact me

- Twitter: @74th
- Mail: site@74th.tech

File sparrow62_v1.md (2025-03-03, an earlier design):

# Sparrow 62 Keyboard Building Guide

## What's Sparrow 62 Keyboard

Sparrow62 is the DIY Keyboard kit inspired by Lily58.

Lily58 に触発された @74th が販売する、自作キーボードキットです。

**using Kailh Choc V2 switches（keycap: DSA）**



### features

- able to use thin switches, Kailh Choc v1/v2 （薄型キースイッチ Kailh Choc V1/V2 が使えること）
- able to use Cherry MX compatible switches （CherryMX 互換キースイッチが使えること）
- aligned vertically (縦に揃ったキー配置(カラムスタッガード)であること）
- enough number of keys（十分キーの数が多いこと）
- placing the Pro Micro next to the keys to make the keyboard itself thinner （Pro Micro をキーの横に配置してキーボード自体を薄くすること)
- using a socket to be able to replace switches (キースイッチ交換可能なようにソケットを使うこと)

As a more complete keyboard that is easier to make, there is Lily58 distributed by @F_YUUCHI. Please consider purchasing Lily58.
（より作りやすい、完成度の高いキーボードとして、ゆーちさんの頒布されている Lily58 があります。 ぜひ Lily58 の購入も検討ください。）

**Kailh Choc V1 キースイッチの場合**


**Cherry MX 互換スイッチを使用し、トッププレートを加えた場合（キーキャップ: DSA）**


## additional items

The additional items required are as follows.
（追加で以下のものが必要です。）

### For Kailh Choc v1/2 switches set（薄型キースイッチ Kailh Choc v1/2 セットの場合）

- Kailh switch socket for Kailh Choc switches（Choc スイッチ用ソケット） x62
- Kailh Choc switch v1/v2 x62
- TRRS Cable x1
- Pro Micro (ATMega 32U4) x2
- USB Cable for Pro Micro x2

### For CherryMX Compatible switches set（CherryMX 互換スイッチの場合）

- Kailh switch socket for Cherry MX Compatible switches（CherryMX 互換スイッチ用ソケット） x62
- Cherry MX Compatible switches x62
- TRRS Cable x1
- Pro Micro (ATMega 32U4) x2
- USB Cable for Pro Micro x2

### For CherryMX Compatible switches with Trackpad set（CherryMX 互換スイッチトラックパッド対応用の場合）

- Kailh switch socket for Cherry MX Compatible switches（CherryMX 互換スイッチ用ソケット） x58
- Cherry MX Compatible switches x58
- TRRS Cable x1
- Pro Micro (ATMega 32U4) x2

### 購入できるストア

- スイッチ用 PCB ソケット x62 （以下のいづれか）
  - MX 互換スイッチ用 ([遊舎工房](https://yushakobo.jp/shop/a01ps/)、[TALP KEYBOARD](https://talpkeyboard.stores.jp/items/5e02c5405b120c792616bcf9))
  - Kailh Low Profile Choc V1/V2 用 ([遊舎工房](https://yushakobo.jp/shop/a01ps/))
- TRRS ケーブル、もしくは 3.5mm ステレオミニプラグオーディオケーブル x1 ([遊舎工房](https://yushakobo.jp/shop/trrs_cable/)、[Amazon](https://www.amazon.co.jp/dp/B018FPYC78))
- Pro Micro x2 ([遊舎工房](https://yushakobo.jp/shop/promicro-spring-pinheader/)、[TALP KEYBOARD](https://talpkeyboard.stores.jp/items/5b24504ba6e6ee7ec60063e3))
- Pro Micro 用コンスルー x2 (遊舎工房 Pro Micro に付属、[TALP KEYBOARD](https://talpkeyboard.stores.jp/items/5e056626d790db16e2889233))

## how to build

### if using Kailh Choc V2, remove 1 foot

Kailh Choc v2 を使うの場合、足を 1 本切断する

Kailh Choc V2 has three copper wireand one of the red circles in the photo is cut with nippers.

Kailh Choc V2 では銅線の足が 3 つ出ていますが、このうち写真赤丸の 1 本をニッパで切断します。
切断した際に発生する小さな破片にご注意ください。
写真青丸の銅線は切断しないように気をつけてください。



ここできれいに切断すると、安定性が増します。
もし少し残ってぐらついてしまう場合、補助的にトッププレートを使うことで安定させることもできます（ただし、Choc スイッチの下の爪と上の爪までの幅が 1.65mm であるため、完全にははまりません）。
[後からトッププレートが必要となった場合、遊舎工房さんで発注することができます。こちらを確認ください。](https://github.com/74th/sparrow62-buildguide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)

### Pro Micro anti-scratch processing

Pro Micro にもげ防止加工を実施（お好みで）

The Pro Micro's Micro USB port is extremely fragile.
To prevent this, apply an evoxy adhesive to the terminals.
Be careful not to accidentally get the adhesive inside the terminals.

Pro Micro の Micro USB 端子は非常にもげやすいものになっています。
これを防止するため、端子に エボキシ系接着剤を塗布します。
誤って端子の中に接着剤が入り込まないように気をつけてください。



### Solder Pro Micro and pin header (if you using mac8 pin header)



#### コンスルーピンヘッダを使用する場合

Pro Micro とピンヘッダをはんだ付けする

ピンヘッダには向きがあります。詳しくは、遊舎工房の解説を確認ださい。

https://yushakobo.zendesk.com/hc/ja/articles/360044233974-%E3%82%B3%E3%83%B3%E3%82%B9%E3%83%AB%E3%83%BC-%E3%82%B9%E3%83%97%E3%83%AA%E3%83%B3%E3%82%B0%E3%83%94%E3%83%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

Sparrow62 キーボードは Pro Micro を写真の向きで使います。

先に、Pro Micro とピンヘッダを PCB に差し込みます。
その上から、 Pro Micro とピンヘッダのみをはんだづけします。
ピンヘッダと PCB ははんだ付けしないようにします。

Pro Micro は脆弱な部品ため、破損した場合交換が可能となります。

### Solder Diodes

Solder the diode, paying attention to the orientation of the diode.
ダイオードを向きを気をつけて、はんだ付けします。

The video by @Salicylic_acid3 is very good, so I think you can check here.
実装手順については、サリチル酸さんのツイートの動画が非常に良くできているため、こちらを確認いただくと良いと思います。

https://twitter.com/Salicylic_acid3/status/1296494976319315970
https://twitter.com/Salicylic_acid3/status/1108798243142434816

**1. Solder one side of the PCB first (先に PCB の片側にはんだをつける)**



**2. Melt the attached solder and solder the diode on one side (つけたハンダを溶かして、ダイオードを片側をはんだ付けする)**



**3. Check the orientation of the diode (ダイオードの向きを確認する)**



**4. Solder the other side (反対側の足をはんだ付けする)**



### Solder switch socket (スイッチソケットを実装する)

The video by @Salicylic_acid3 is very good, so I think you can check here.
実装手順について、こちらもサリチル酸さんのツイートの動画がよくできているため、こちらを確認いただくのが良いと思います。

https://twitter.com/Salicylic_acid3/status/1310253635255717889

**1. Solder the pads on both sides of the PCB(先に PCB の両側の端子にハンダをつける)**



**2. Place the socket and push while melting the solder(ソケットを置き、ハンダを溶かしながら押す)**



**3. Do the same on the other side(反対側も同様にする)**



**4. Repeat until they are in close contact (密着するまでくりかえす)**



### Implement tact switch

タクトスイッチを実装する

The tactile switches are **implement on a different surface than the diode**.
タクトスイッチは、**ダイオードとは異なる面に** 実装します。

The surface to be soldered is **the same surface as the diode**.
足が裏面に出るため、はんだ付けを行う面は **ダイオードと同じ面** です。

**tactile switch(タクトスイッチ)**



### Implement TRRS socket

TRRS ジャックを実装する

The TRRS sockets are **implement on a different surface than the diode**.
TRRS ジャックは、**ダイオードとは異なる面に** 実装します。

The surface to be soldered is **the same surface as the diode**.
足が裏面に出るため、はんだ付けを行う面は **ダイオードと同じ面** です。

**TRRS Socket(TRRS ジャック)**



### Assemble the top and bottom plate

トッププレートとボトムプレートを組み立てる。

#### For Kailh Choc Switches

Attach the bottom plate to the PCB with double-sided tape.
両面テープで PCB とボトムプレートを貼り付けてください。 貼り付けなくても、うまくはまれば固定されます。

#### For Cherry MX Compatible Switches



#### For Cherry MX Cpmpatible Switches with Trackpad





### Cut and attach rubber sheets with double-sided tape

両面テープでボトムプレートとゴムシートを接着します。

For trackpad, use a long rubber sheet.
トラックパッドがある場合、より長いシートをトラックパッド用に使ってください。





### Insert switches and Pro Micro

キースイッチと Pro Micro をソケットに差し込みます。

### flash QMK Firmware

#### using QMK Toolbox and REMAP

[Download ./firmware/62v1/sparrow62_v1_via.hex](https://github.com/74th/sparrow62-buildguide/raw/refs/heads/master/firmware/62v1/sparrow62_v1_via.hex)

Download and install QMK Toolbox.

https://github.com/qmk/qmk_toolbox/releases

Flash via firmware.

- Local File: sparrow62_v1_via.hex
- MCU : atmega32u4

You can use REMAP for configuring your keymap.

https://remap-keys.app/

#### using QMK Firmware

```
qmk flash -kb sparrow62 -km default
```

## hints for Japanese

VIA を使う場合、QMK Toolbox でファームウェアを書き込めば完了です。

キーマップのカスタマイズには、VIA を使うと GUI で変更できます。
更に高度なカスタ合図を行う場合、QMK Firmware のビルド環境を整える必要があります。

#### QMK Toolbox を使ってデフォルトのファームウェアを書き込む

以下のキーマップを、default のファームウェアとして提供しています。

- [Download ./firmware/62v1/sparrow62_v1_default.hex](https://github.com/74th/sparrow62-buildguide/raw/refs/heads/master/firmware/62v1/sparrow62_v1_default.hex)

レイヤ 1



レイヤ 2（レイヤ 1 の`MO(1)`のキーと同時に押すと、動作する）



こちらを [QMK Toolbox](https://github.com/qmk/qmk_toolbox/releases) を使って書き込むことができます。

QMK Toolbox の使い方は[サリチル酸さんの記事](https://salicylic-acid3.hatenablog.com/entry/qmk-toolbox)が詳しいため、こちらを確認ください。

左右のキーボードの両方に書き込む必要があります。

#### VIA を使ってキーマップを変更する

GUI でキーマップを変更できる [VIA](https://caniusevia.com/) というツールがあります。

VIA を使うには、VIA のファームウェアを書き込む必要があります。以下からダウンロードし、[QMK Toolbox](https://github.com/qmk/qmk_toolbox/releases)などを使って書き込んでください。

- [Download ./firmware/62v1/sparrow62_v1_via.hex](https://github.com/74th/sparrow62-buildguide/raw/refs/heads/master/firmware/62v1/sparrow62_v1_via.hex)

VIA のファームウェアは Remap を使うと、ブラウザの UI でキーマップの変更ができます。

#### 更にカスタマイズするため、QMK Firmware のビルド環境を整える

QMK Firmware のセットアップ手順（[公式英語](https://docs.qmk.fm/#/newbs_getting_started)、[有志日本語](https://github.com/shelaf/qmk_firmware/blob/master/docs/ja/newbs_getting_started.md)）に従い、インストールします。

Ubuntu を使用している場合には、ModemManager が邪魔をすることがあるので、`sudo systemctl stop ModemManager.service`を実行いておくと有効です。

デフォルトのキーマップをインストールするには、PC と Pro Micro を USB ケーブルで接続し、以下を実行します。

```
qmk flash -kb sparrow62 -km default
```

`Detecting USB port, reset your controller now...`と表示されたところで、キーボードのタクトスイッチ（リセット）を押します。
この Firmware の書き込みを、左右 2 つの Pro Micro で両方とも行います。

この default のキーマップは以下のようになっています。 `MO(_FN)`のキーを押すと、キーレイヤが下の`[_FN]`のものに変わり、F1-12 キーや、矢印キーとして動作させることができます。



新しいキーマップを作成する場合には、以下のように実行します（nnyn が新しいキーマップ名）

```
qmk new-keymap -kb sparrow62 -km nnyn
```

キーマップの設定する C のソースが `~/qmk_firmware/keyboards/sparrow62/keymaps/nnyn/keymap.c` にできます。
こちらを変更して、以下のコマンドで Firmware を書き込みます。

```
qmk flash -kb sparrow62 -km nnyn
```

詳しいファームウェアの実装方法は、公式のドキュメントや Qiita の記事を参照ください。

- [Keymap Overview](https://docs.qmk.fm/#/keymap)
- [はじめての QMK キーマップ編集](https://qiita.com/marksard/items/9317949ce1da327f7436)

### キースイッチのテストをする

QMK Continuator のキーテストを開きます。

https://config.qmk.fm/#/test

キースイッチを押し、キーレイアウトの通りに動作するかを確認します。

### 動作しないキーがある場合

#### 1 キーのみ動作しない場合

まず、キースイッチの足が曲がっていないか確認してください。

左手用のキーの場合、以下の同じ色の部分がつながっています。それぞれテスターなどで疎通しているか確認ください。



右手用のキーの場合、以下の同じ色の部分がつながっています。それぞれテスターなどで疎通しているか確認ください。



#### 縦一列、横一列が動作しない場合

青丸が COL のラインとなっており、そのまま Pro Micro の COL0-6 につながっています。緑丸が ROW のラインとなっており、そのまま Pro Micro の ROW0-4 につながっています。
Pro Micro の接続を確認ください。

## Contact me

- Twitter: @74th
- Mail: site@74th.tech

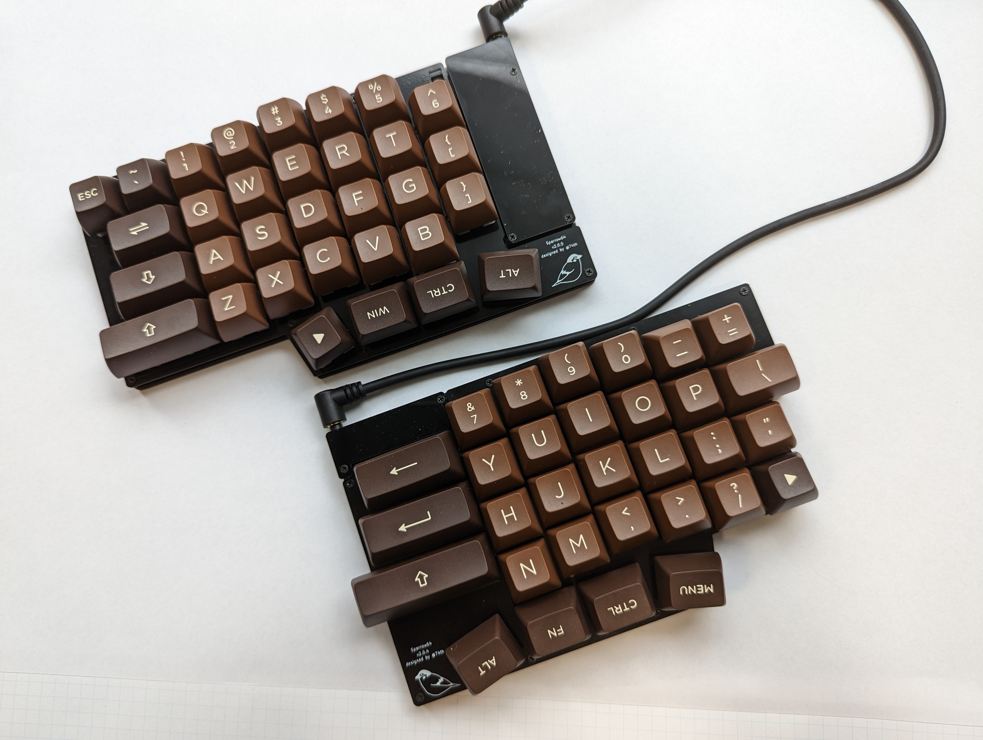
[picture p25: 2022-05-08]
photos/v2/overview.jpg

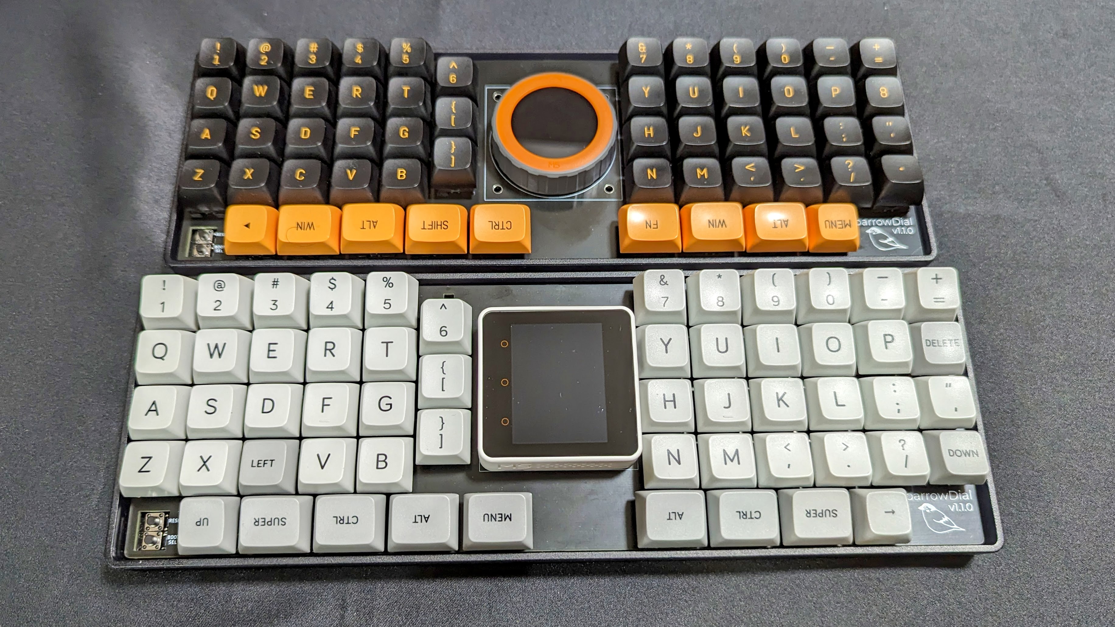
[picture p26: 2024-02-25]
photos/dial/overview.jpg

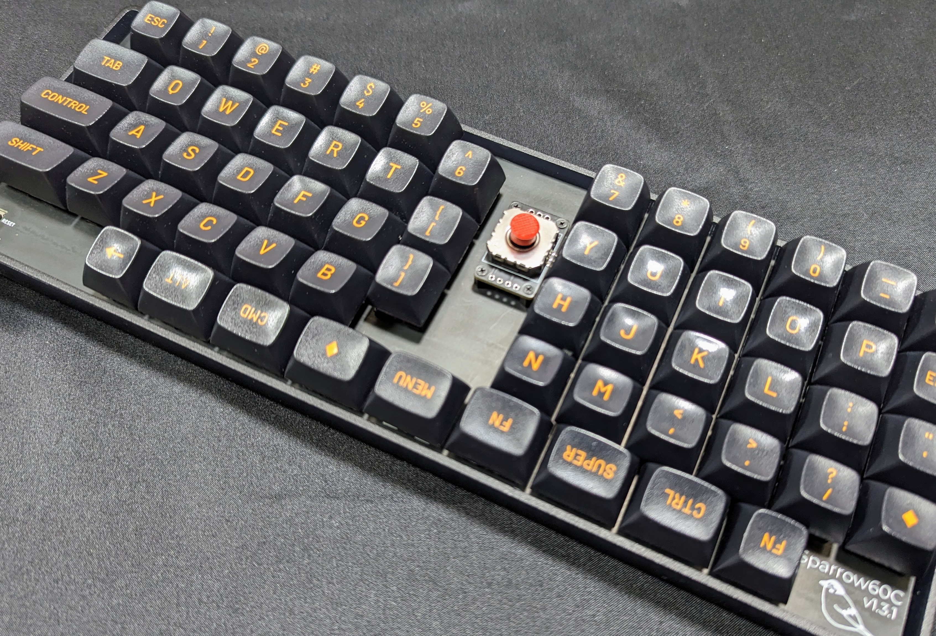
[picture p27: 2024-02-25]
photos/60c/overview.jpg

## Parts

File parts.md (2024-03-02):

# 部品の購入先

各部品はこちらから購入ください。

## CherryMX互換スイッチソケット（Kailhスイッチソケット）

- 遊舎工房 「MX用」を選んでください https://shop.yushakobo.jp/products/a01ps
- TALP KEYBOARD https://talpkeyboard.net/items/5e02c5405b120c792616bcf9

## Kailh Chocスイッチソケット

- 遊舎工房 「Kailh Choc ロープロファイル用」を選んでください https://shop.yushakobo.jp/products/a01ps
- TALP KEYBOARD https://talpkeyboard.net/items/6365b6224ff8c216413a0c92

## CherryMX互換スイッチ

ほとんどのスイッチがそうです。薄型と書かれているものは違う可能性があるため、気をつけてください。

### おすすめ

- Durock Black Lotus Linear 2023 Lubed Version
  - リニアスイッチの中でも最高と名高い
  - TALP KEYBOARD https://talpkeyboard.net/items/63c7d5629d284218425a5597
  - 遊舎工房 https://shop.yushakobo.jp/products/6337
- Jwick T1 Tactile Switch
  - 力強いタクタイルのT1スイッチの廉価版。だけど製造元はDurockで一緒。
  - TALP KEYBOARD https://talpkeyboard.net/items/62889ceff3de5c78c0c1fc05
- Durock Ice King Tactile T1
  - T1スイッチのクリアハウジング版。LEDをよく透過する。
  - TALP KEYBOARD https://talpkeyboard.net/items/65c2eba982808c007e84c1ac
  - 遊舎工房 https://shop.yushakobo.jp/products/8474
- DUROCK T1 Shrimp Silent Tactile Switch
  - T1スイッチのサイレント版。サイレント効果はほどほど。親指や小指のキーに割り当てると、強く叩いても指を痛めにくい。
  - TALP KEYBOARD https://talpkeyboard.net/items/611f422c84ca6370e66aeb85
  - 遊舎工房 https://shop.yushakobo.jp/products/4649
- Kailh Deep Sea Silent Box Switch Islet
  - おそらくHHKB Studioに搭載されているスイッチと同等スペックのスイッチ（HHKB StudioはKailh製をOEMとして使用している）。サイレントでありがちなくにゅっとした感じが抑えられて、リニアを楽しめるスイッチ。
  - TALP KEYBOARD https://talpkeyboard.net/items/644369821c72b409e0ad9d2d

## Kailh Chocスイッチ

Kailh製の薄型スイッチ。

- TALP KEYBOARD https://talpkeyboard.net/?category_id=638b0e2718324e0fdaf56eb0
- 遊舎工房 https://shop.yushakobo.jp/collections/all-switches/Kailh-Choc-V1%E3%82%B9%E3%82%A4%E3%83%83%E3%83%81

## CherryMX互換キーキャップ

自作キーボード用のキーキャップはほとんどがこれです。Choc用と書かれているものは異なるので注意。

## Kailh Choc v1キーキャップ

Kailh Chocには v1、v2 があります。v1スイッチの場合はKailh Choc v1対応キーキャップを使用してください。
Kailh Choc v2、LOFLEE x Kailh Ghost Switchは、MX互換キーキャップが使用できます。

- TALP KEYBOARD https://talpkeyboard.net/?category_id=638d75c18da73b0695940f48
- 遊舎工房 https://shop.yushakobo.jp/collections/keycaps/For-Choc-v1

## GH60互換ケース

- 遊舎工房 https://shop.yushakobo.jp/products/60-plastic-case
- TALP KEYBOARD https://stores.jp/search?q=GH60&store=talpkeyboard

## M5Dial

- Switch Science https://www.switch-science.com/products/9271

## M5StackCore2

- Switch Science https://www.switch-science.com/products/9349?_pos=3&_sid=37b87364b&_ss=r
- マルツオンライン https://www.marutsu.co.jp/pc/i/2776620/

## M5Stack用赤外線送受信ユニット

- Switch Science https://www.switch-science.com/products/5699
- マルツオンライン https://www.marutsu.co.jp/pc/i/1556080/

## 付属品の追加部品

少数必要な場合、問い合わせいただければ相談にのります。

USB Type-C ソケットが必要な場合、問い合わせください。

### Sparrow62 v2.0.4~

- 1N4148W スイッチングダイオード : https://akizukidenshi.com/catalog/g/g107084/
- TRRS ソケット : https://akizukidenshi.com/catalog/g/g106070/
- USB Type-C ソケット : 予備あります。問い合わせください。 https://akizukidenshi.com/catalog/g/g115426/
- 左手 IC MCP23017 : https://akizukidenshi.com/catalog/g/g109486/
- チップ抵抗 27Ω （270）: https://www.marutsu.co.jp/pc/i/856914/
- チップ抵抗 1kΩ （102）: https://www.marutsu.co.jp/pc/i/856914/
- チップ抵抗 5.1kΩ (512) : https://www.marutsu.co.jp/pc/i/857033/
- チップ抵抗 10kΩ （103）: https://www.marutsu.co.jp/pc/i/856915/
- LED SK6812MINI-E : https://akizukidenshi.com/catalog/g/g115478/
- 細ピンヘッダ : https://akizukidenshi.com/catalog/g/g104398/
- 3.5mm M2 樹脂スペーサー : https://www.hirosugi-net.co.jp/shop/g/g4157/
- 5.0mm M2 樹脂スペーサー : https://www.hirosugi-net.co.jp/shop/g/g4160/
- 4.0mm M2 ネジ : https://www.monotaro.com/p/4041/1183/?displayId=5
- 5.0mm M2 ネジ : https://www.monotaro.com/p/4307/7553/?displayId=5
- ゴムシート : https://www.monotaro.com/p/3584/6307/

### Sparrow v1 2021 夏ごろ〜

- 3.0mm 金属スペーサー : https://www.hirosugi-net.co.jp/shop/g/g102/
- タクトスイッチ : https://akizukidenshi.com/catalog/g/g108073/
- 1N4148W スイッチングダイオード : https://akizukidenshi.com/catalog/g/g107084/
- 4.0mm M2 ネジ : https://www.monotaro.com/p/4926/2744/
- 5.0mm M2 ネジ : https://www.monotaro.com/p/4926/2753/
- TRRS ソケット : https://akizukidenshi.com/catalog/g/g106070/
- ゴムシート : https://www.monotaro.com/p/3584/6307/

## Sparrow v1 初期型

- 1N4148W スイッチングダイオード : https://akizukidenshi.com/catalog/g/g107084/
- タクトスイッチ : https://akizukidenshi.com/catalog/g/g108073/
- TRRS ソケット : https://akizukidenshi.com/catalog/g/g106070/
- 3.0mm 金属スペーサー : https://www.hirosugi-net.co.jp/shop/g/g102/
- 4.0mm M2 ネジ : https://www.monotaro.com/p/4926/2744/
- ゴム足 : https://www.monotaro.com/p/4891/2387/?displayId=5

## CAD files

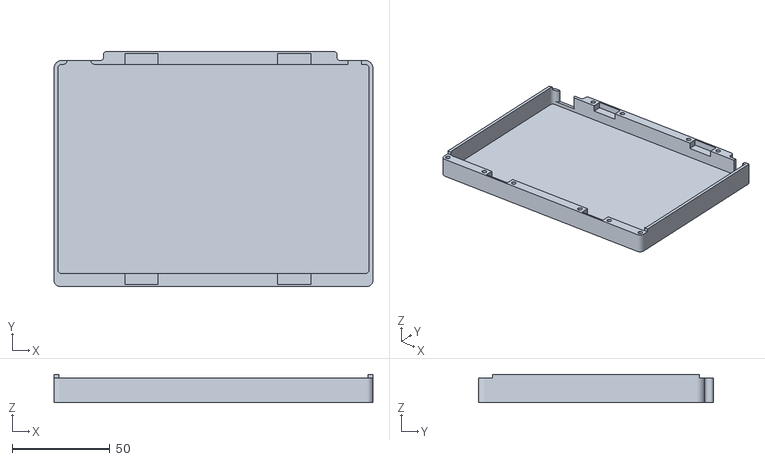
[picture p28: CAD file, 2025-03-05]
misc/sv3/case/v1.0.0/left-case-main-mx.stl
163.0 x 120.0 x 14.5

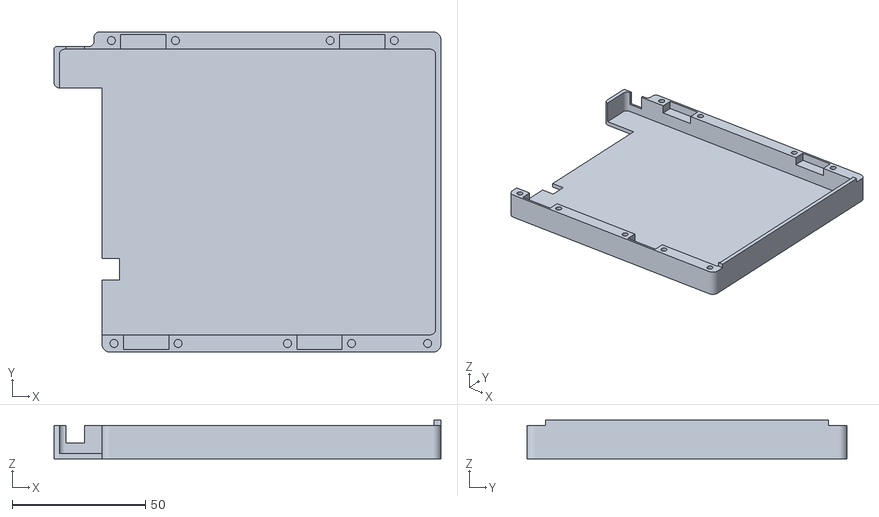
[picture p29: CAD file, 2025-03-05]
misc/sv3/case/v1.0.0/right-case-main-mx.stl
145.0 x 120.0 x 14.5

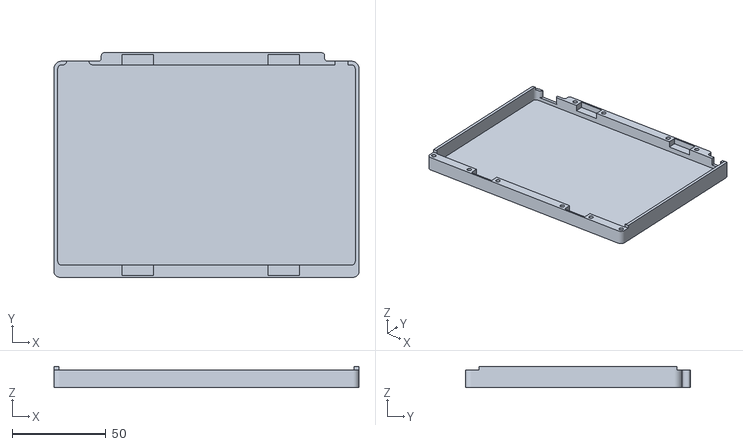
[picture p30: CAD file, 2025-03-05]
misc/sv3/case/v1.0.0/left-case-main-choc.stl
163.0 x 120.0 x 11.4

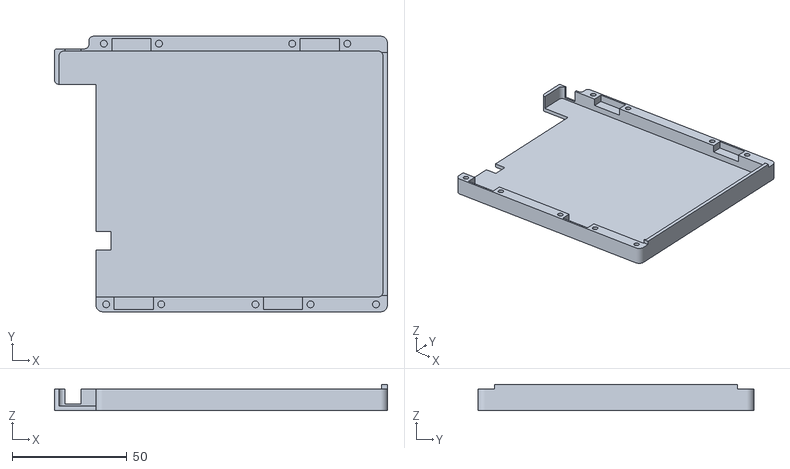
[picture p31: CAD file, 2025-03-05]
misc/sv3/case/v1.0.0/right-case-main-choc.stl
145.0 x 120.0 x 11.4

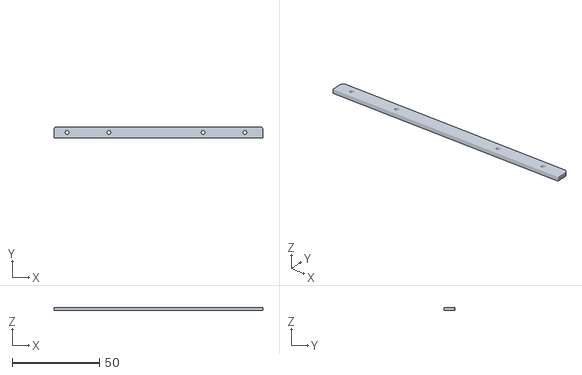
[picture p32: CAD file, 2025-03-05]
misc/sv3/case/v1.0.0/left-case-top-upper.stl
119.9 x 6.50 x 2.00

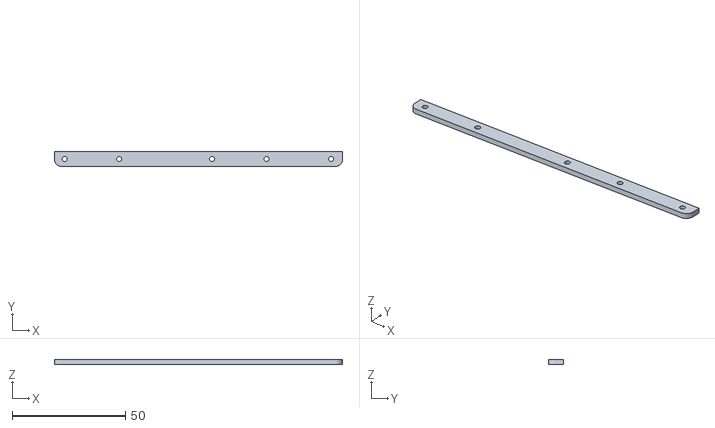
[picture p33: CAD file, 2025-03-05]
misc/sv3/case/v1.0.0/right-case-top-lower.stl
127.0 x 6.50 x 2.00

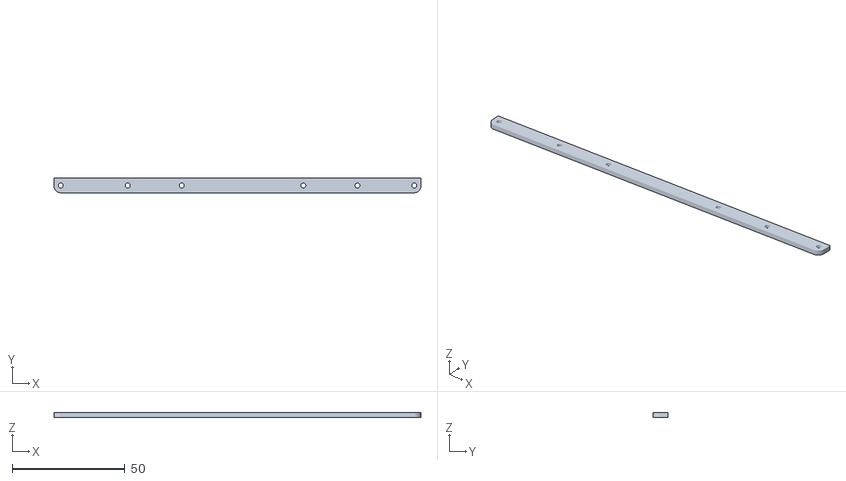
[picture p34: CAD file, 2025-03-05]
misc/sv3/case/v1.0.0/left-case-top-lower.stl
163.0 x 6.50 x 2.00

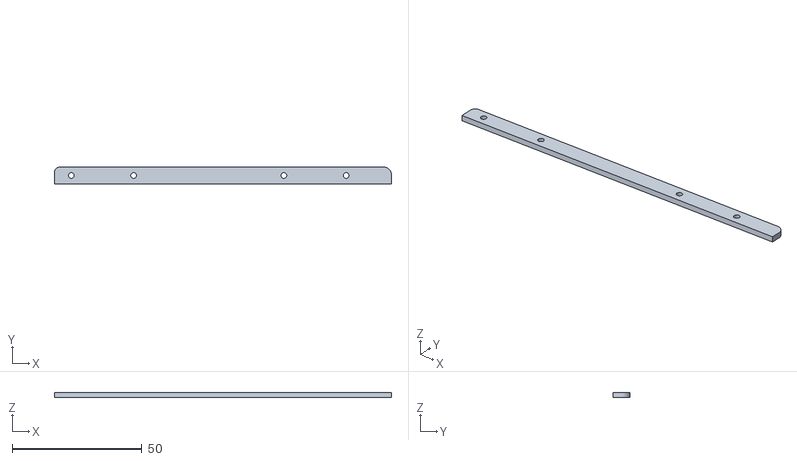
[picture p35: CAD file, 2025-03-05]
misc/sv3/case/v1.0.0/right-case-top-upper.stl
130.0 x 6.50 x 2.00

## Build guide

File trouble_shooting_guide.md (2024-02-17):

# Trouble Shooting Guide トラブルシュートガイド

- [#共通](#共通)
- [#Sparrow60C](#Sparrow60C)
- [#SparrowDial](#SparrowDial)
- [#SparrowG21](#SparrowG21)

## 共通

### 1つのキーが動作しない

主に、以下が考えられます。

> [!NOTE]
> SparrowG21については個別の対処もあります。詳しくは、SparrowG21のセクションも参照ください。

#### スイッチソケットの実装に、不良がある

PCB中のランドまではんだで溶接できていないことがあります。

ソケットの片側の金属部分をつまみ、左右に引っ張るとわずかに動く場合その可能性があります。

ソケットの金属部分に直接ジャンパコードで当てて通電しても反応しない場合、この可能性があります。

#### ダイオードの実装に、不良がある

ダイオードの逆向きが逆向きであることがあります。74thの販売するキーボードキットは、注意書きがない限り、すべて同じ無機になるように設計しています。ルーペ等で確認ください。

PCB中のランドまではんだで溶接できていない。足の片側の金属部分をつまみ、左右に引っ張るとわずかに動く場合その可能性があります。

ソケットの金属部分に直接ジャンパコードで当てて通電しても反応しない場合、この可能性があります。

> [!NOTE]
> SparrowG21はマトリックス配線ではないため、ダイオードの実装はありません

#### スイッチが押下しても通電しなくなっている

スイッチには耐用回数や、品質の悪いものがあります。その場合、通電しないことがあります。

キースイッチを取り替えても同じ現象が発生するか確認ください。そのスイッチでしか発生しない場合はスイッチに問題があると考えられます。

#### ソケットのキー掴みが弱くなっている

ソケットのスイッチのキーの抜き差し耐用回数は100回ほどです。緩んでくると、キーのピンに適切に接触しません。ソケットを交換するか、スイッチのピンをほんの少し曲げることで、接触させることができることもあります。

ソケットの金属部分に直接ジャンパコードで当てて通電すると反応するが、スイッチを指すと反応しない場合はこの可能性があります。

### 列や、行まるごとキーが動作しない

マイコンへは、行、列単位にピンに接続されています。行や列がまるごと反応しない場合には、マイコンへのピンの実装に不良があることが考えられます。

74thのキーボードの場合には回路図を公開していますので、どのマイコンのピンと接続されているか確認し、その実装をやり直してみてください。

## Sparrow60C

### StickPointVが反応しない

StickPointVから応答がない状態が続くと、QMK Firmwareは再試行を止めるようになっています。一度、USBを抜き差しして、StickPointVとキーボードの両方のマイコンをリセットさせてみてください。

## SparrowDial

### no I2C Connectionと出続ける

時折、no I2C Connectionになったまま接続が確立されないことがあります。その場合には、一度キーボードのUSBを抜き差ししてみてください。キーボードとM5StackCore2、M5Dialが同時にリセットされます。

## SparrowG21

### 1つのキーが動作しない

SparrowG21はマイコンへはキーごとに接続されています。74thのキーボードの場合には回路図を公開していますので、どのマイコンのピンと接続されているか確認し、その実装をやり直してみてください。

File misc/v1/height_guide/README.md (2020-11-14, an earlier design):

# 高さ調整ガイド

## 使う部品

PCB 背面のソケットは 1.6mm であるため、2mm のゴム足でも支えることができます。
最低限の高さ +2mm までの調整にはゴム足を使い分けることができます。
このうち高さ4mmのものはキットに付属しています。

- [モノタロウ ソフトクッション 8x2.0](https://www.monotaro.com/p/4891/2353/) ￥ 699 / 100 個
- [モノタロウ ソフトクッション 10x4.0](https://www.monotaro.com/p/4891/2387/) ￥ 899 / 100 個

これ以上の調整が必要な場合には、ボトムプレートが必要となります。
ボトムプレートはアクリルで作成する場合、遊舎工房に発注することが可能です。
A4 サイズで左右分を作ることができます。
アクリルの厚さは、2mm、もしくは 3mm になり、1mm 調整可能です。
Elecrow にて、 PCB として作ることもできます。

- [遊舎工房 レーザーカットサービス アクリル押出 A4 2mm](https://yushakobo.jp/lasercut/) ￥ 3,780 / 2 枚
- [遊舎工房 レーザーカットサービス アクリル押出 A4 3mm](https://yushakobo.jp/lasercut/) ￥ 3,920 / 2 枚
- [Elecrow PCB 105mm x 159mm 厚さ 1.6mm](https://www.elecrow.com/pcb-manufacturing.html) \$ 38.83 / 5 枚

発注に必要なデータと発注方法のページは準備中です。

ボトムプレートと PCB プレートの間にはスペーサーを挟みます。
スペーサーのサイズにより、高さ調整が可能です。

最低限の 2mm のスペーサーを使用する場合、両雌ねじのスペーサーを使用できないため、中空スペーサーを使います。
ナットも高さが 1.6mm のものがあるため、2mm のゴム足で支えることができます。

- [モノタロウ スペーサー（中空）M2 2mm](https://www.monotaro.com/p/1126/1364/) ￥ 799 / 50 個
- [皿子ネジ M2 8mm](https://www.monotaro.com/p/4926/2771/) ￥ 449 / 50 個
- [六角ナット M2](https://www.monotaro.com/p/4221/6097/) ￥ 399 / 12 個

3mm 以上のスペーサーを使用する場合、両雌ねじのスペーサーを使うことができます。
このスペーサーにより 0.5 mm 単位の調整が可能です。
両雌ねじのスペーサーを使う場合、ネジには 4mm のものを使います。

- [皿小ねじ M2 4mm](https://www.monotaro.com/p/4926/2744/) ￥ 449 / 50 個
- [モノタロウ 黄銅スペーサー M2 3~10mm/0.5mm](https://www.monotaro.com/g/00428593/) ￥ 1,490 / 50 個
- [モノタロウ ジュラコンスペーサー M2 3~10mm/0.5mm](https://www.monotaro.com/g/01213180/) ￥ 1,290 / 50 個

スペーサーはいろいろ試すには、若干高価です。
中国産であれば安価に入手することができます。
ネジはネジ穴が潰れると辛いため日本製のものを使いますが、スペーサーであれば中国産で妥協の範囲かと思います。

- [Aliexpress brass spacer m2 3~10mm/1mm](https://www.aliexpress.com/item/32904784115.html) US\$ 1.04 ~ 2.20 / 50 個
- [Aliexpress nylon spacer m2 5,6,8,10mm](https://www.aliexpress.com/item/32996308968.html) US\$ 0.49 ~ 1.37 / 50 個

## Choc v1 で 約 15mm

- Kailh Choc v1 スイッチ
- PCB 1.6mm
- ゴム足 2mm

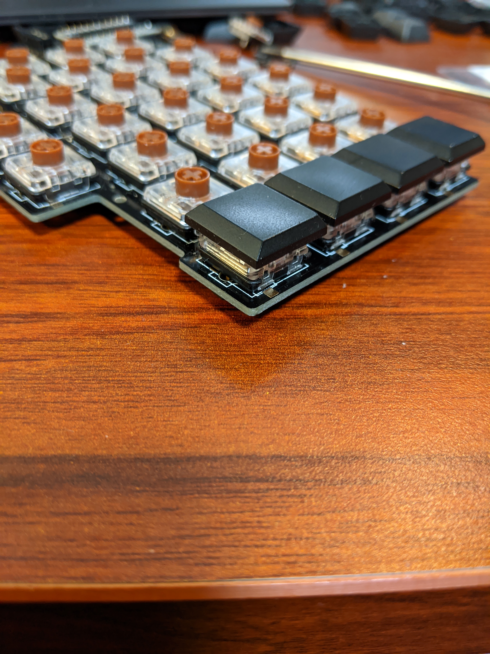
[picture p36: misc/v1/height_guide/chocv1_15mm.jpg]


## Choc v2 で 約 16mm

- DSA キーキャップ
- Kailh Choc v2 スイッチ
- PCB 1.6mm
- ゴム足 2mm

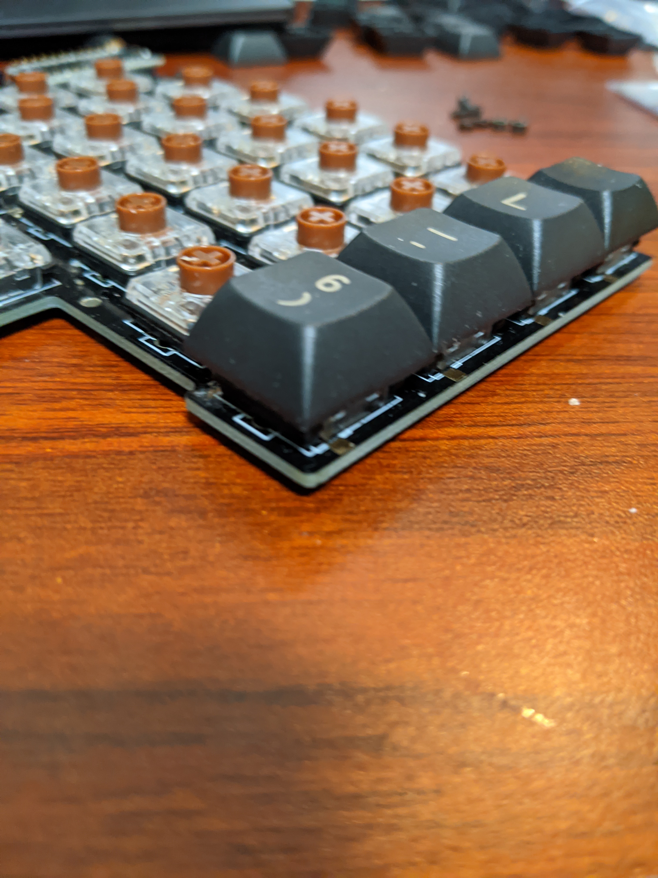
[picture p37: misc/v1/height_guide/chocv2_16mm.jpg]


## Choc v2 で 約 18mm

- DSA キーキャップ
- Kailh Choc v2 スイッチ
- PCB 1.6mm
- ゴム足 4mm

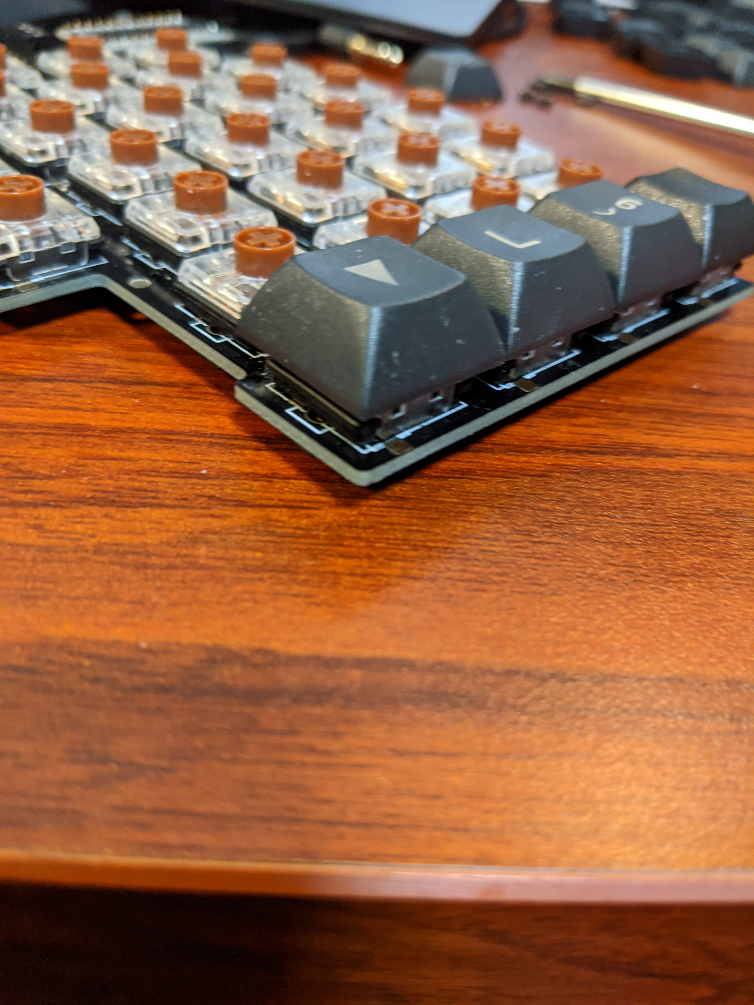
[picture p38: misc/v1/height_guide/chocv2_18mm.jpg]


## Choc v2 で 約 20mm

- DSA キーキャップ
- Kailh Choc v2 スイッチ
- PCB 1.6mm
- 中空スペーサー 2mm
- ボトムプレート 1.6mm
- ゴム足 2mm
- （8mm 小ねじ、六角ナットを使用）

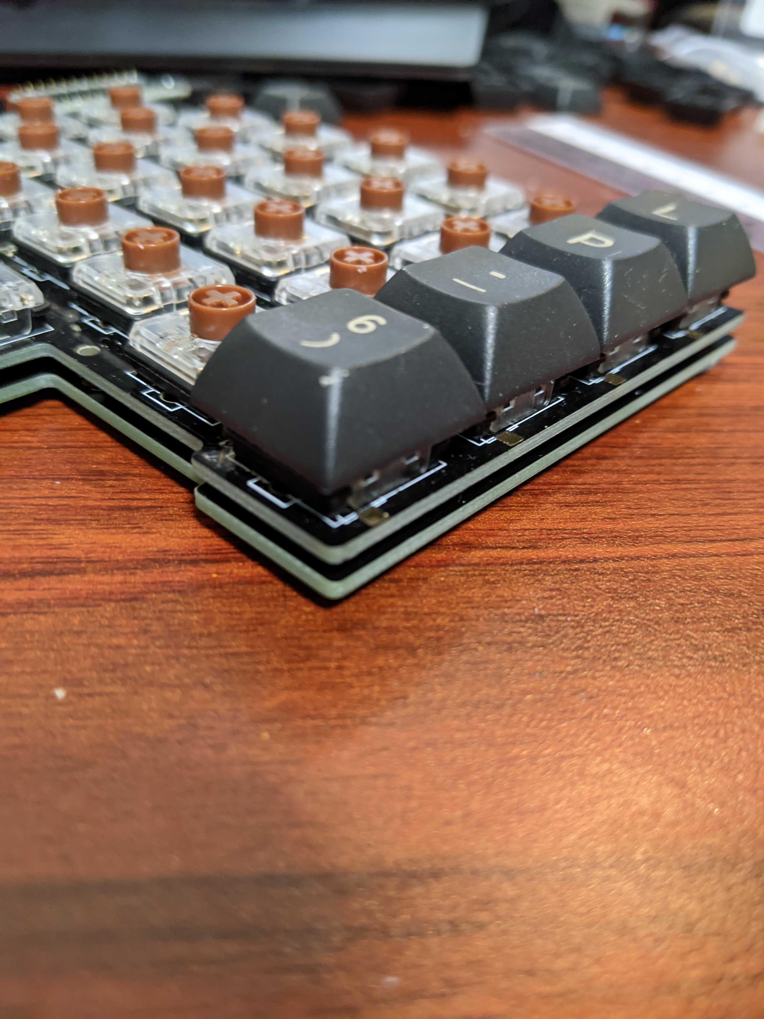
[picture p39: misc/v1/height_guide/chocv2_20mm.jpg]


## Choc v2 で 約 21mm

- DSA キーキャップ
- Kailh Choc v2 スイッチ
- PCB 1.6mm
- 両雌ねじスペーサー 3mm
- ボトムプレート 1.6mm
- ゴム足 2mm

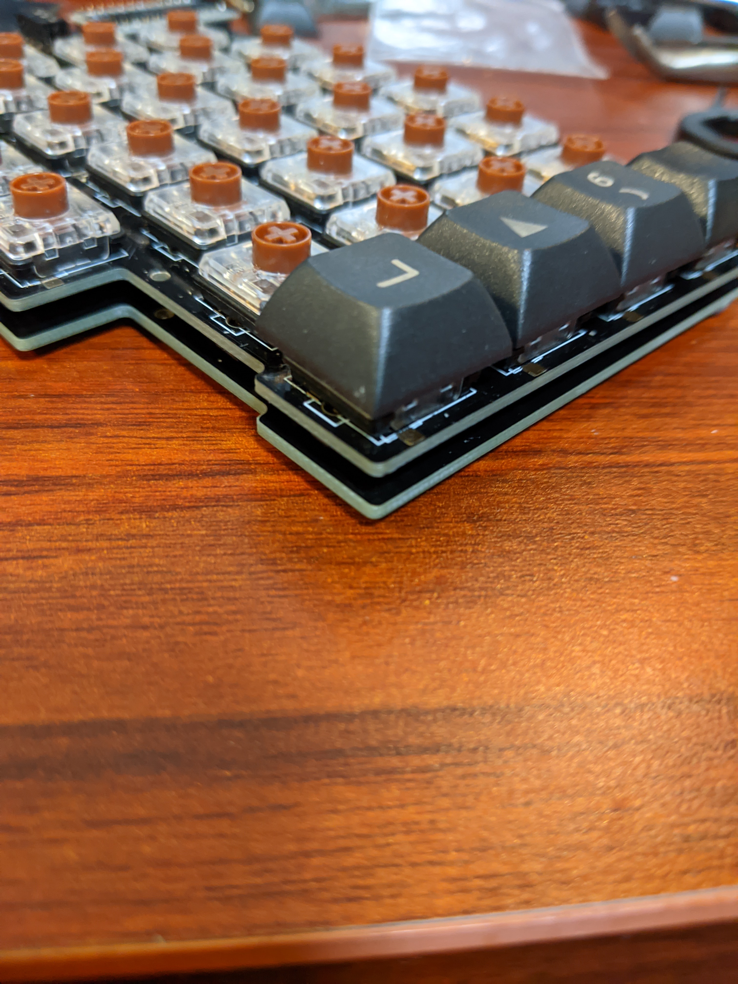
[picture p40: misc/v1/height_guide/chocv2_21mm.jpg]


## Choc v2 で 約 23mm

- DSA キーキャップ
- Kailh Choc v2 スイッチ
- PCB プレート 1.6mm
- 両雌ねじスペーサー 5mm
- ボトムプレート 1.6mm
- ゴム足 2mm

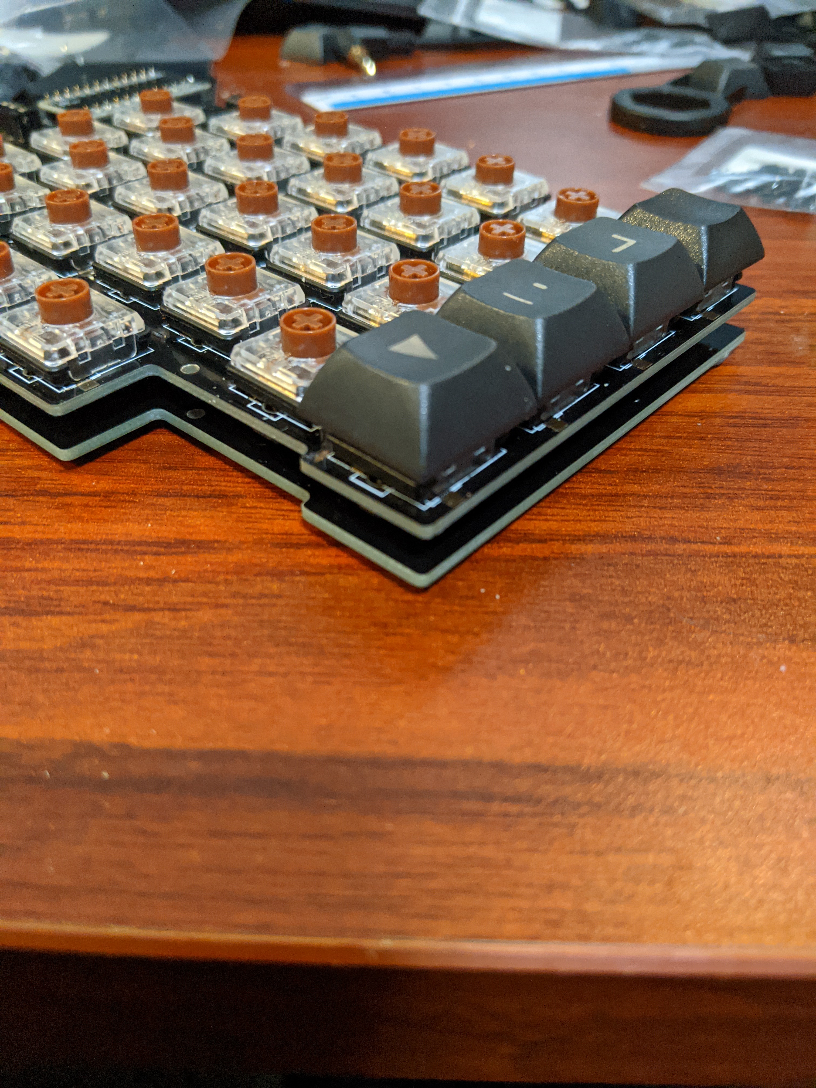
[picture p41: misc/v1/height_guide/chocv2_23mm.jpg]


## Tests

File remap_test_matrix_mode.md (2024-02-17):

# RemapのTest Matrix modeを使ったキーマトリックスのテスト方法

Remap には、キーマトリックスをテストする機能があります。
こちらを使うことで、各キーのダイオードやソケットの実装が正常かどうか確認することができます。

それにはまず、VIA、Remap対応のファームウェアをキーボードに書き込みます。Sparrow60C、SparrowDialにおいてはあらかじめ対応ファームウェアが書き込まれています。

まず、RemapのWebサイトを開き、「CUSTOMIZE YOUR KEYBOARD」を押します。

https://remap-keys.app/

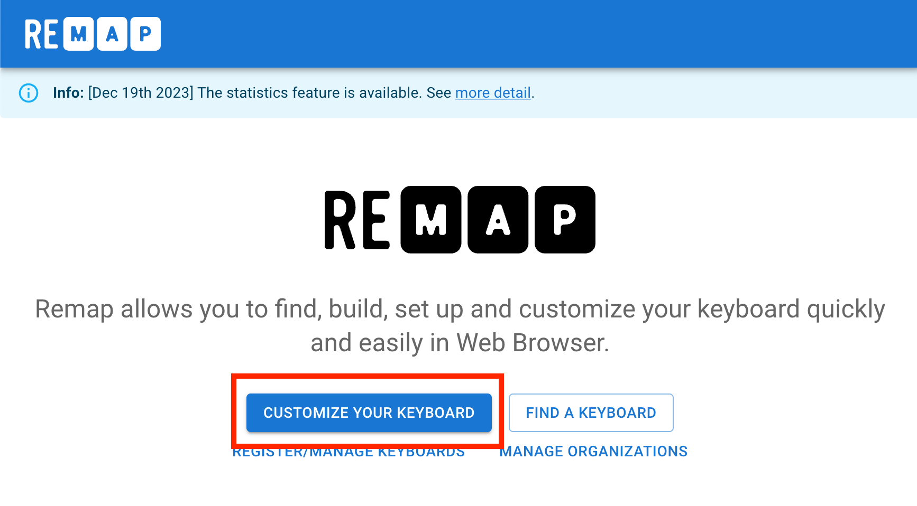
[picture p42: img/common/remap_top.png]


キーボードの接続が表示されるため、「+ KEYBOARD」を押します。

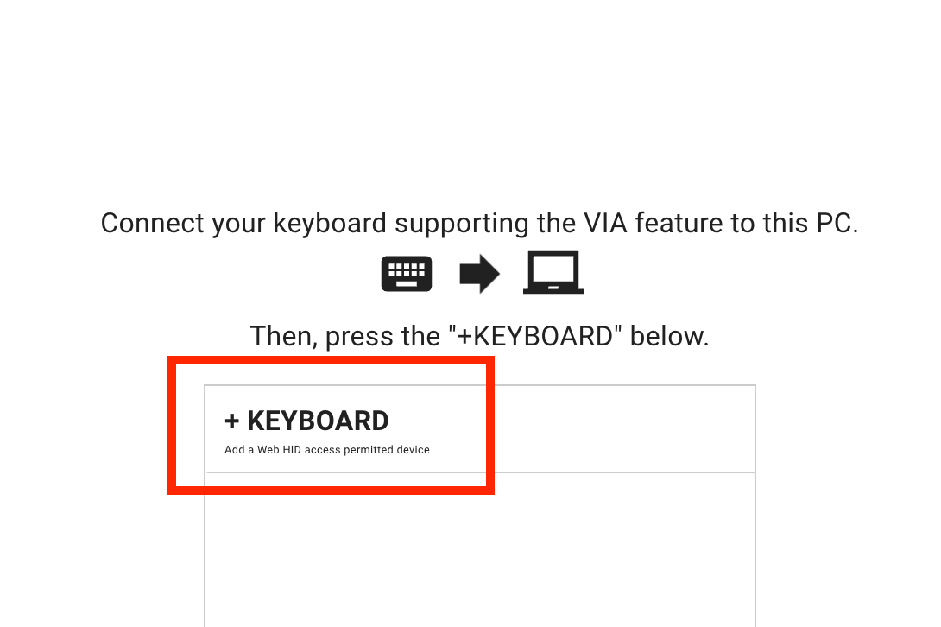
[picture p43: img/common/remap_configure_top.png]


既にUSB接続している場合には、左上のメニューから追加を行ってください。

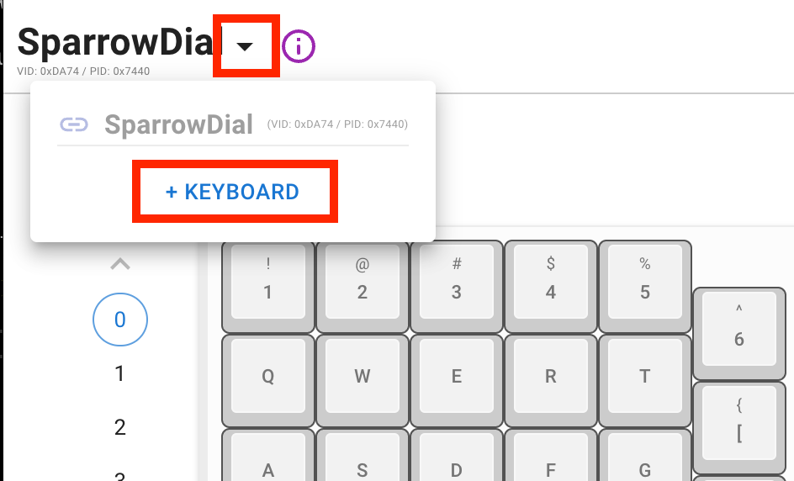
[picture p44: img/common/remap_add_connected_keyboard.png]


キーマップの設定画面になりましたら、図のメニューから「Test Matrix mode」を選んでください。

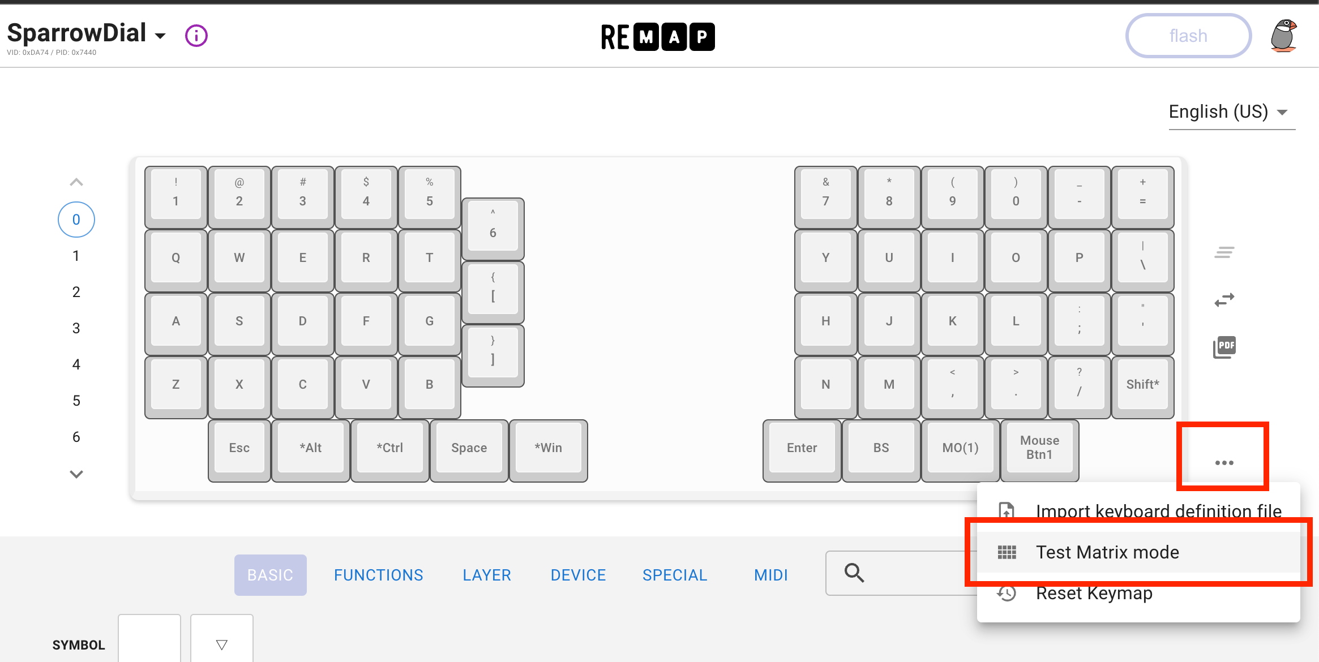
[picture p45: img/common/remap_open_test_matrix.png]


この画面では、キーを押すとこのように色が変わって表示されます。この状態ですべてのキーが動作することを確認してください。

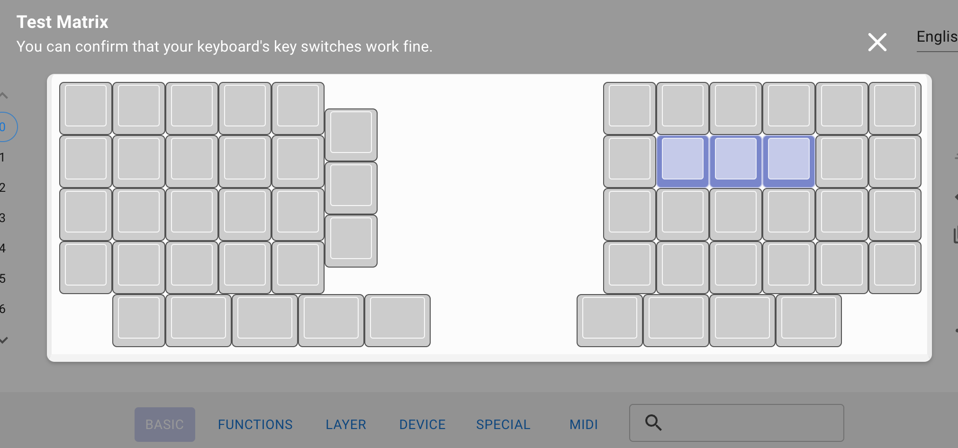
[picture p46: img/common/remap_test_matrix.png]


キーが押されるとスイッチの2つのピンが通電した状態になります。スイッチを実際に刺さなくても、「金属ピンセットでソケットの2つの金属部分に触れる」ことや「ジャンパワイヤーでソケットの2つうの金属部分に触れること」で通電させることもできます。

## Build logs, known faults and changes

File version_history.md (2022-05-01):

# Sparrow 62 version

- v0.1 試作 1 Pro Micro 利用版
- v1.0 試作 2
- v1.1 試作 3
- v1.2 頒布版
- v1.3 v1.2 と同じ（販売時に、ボトムプレートを付属）
- v2.0.0 試作 1 RaspberryPi PICO 利用
- v2.0.1 試作 2
- v2.0.2 試作 3
- v2.0.3 試作 4 ボトムプレートの施策
- v2.0.4 頒布版（左ボトム、右 PCB、右トップ、右ボトム）
- v2.0.5 頒布版（左 PCB、左ボトム）

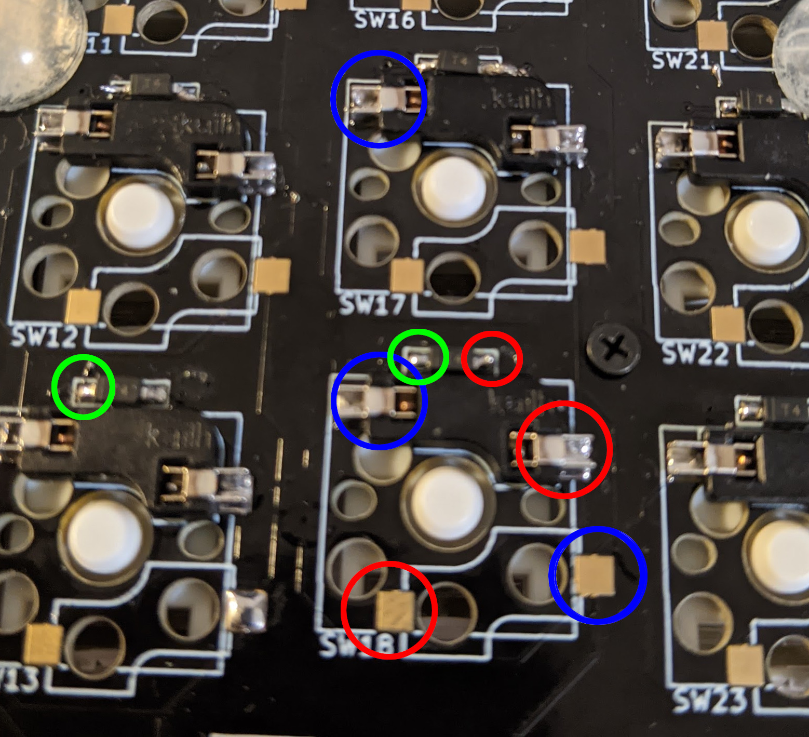
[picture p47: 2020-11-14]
img/62v1/left_hand_debug0.jpg

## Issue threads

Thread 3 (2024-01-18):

QMK firmware for Sparrow62 keyboard with RPI Pico controller on board.

azhizhinov, 2024-01-18:
Hello.
There is no QMK firmware for Sparrow62 keyboard with RPI Pico controller on board, right?
So, there is no possibility to use VIA or VIAL GUIs to configure keyboard's layout?
Only KMK firmware available?
Thanks in advance.

azhizhinov, 2024-02-19:
Hello.
Do you have some news about QMK firmware for the Sparrow62 v2 with RPI Pico controller?

74th, 2024-08-15:
Sorry for the delay.
I'm getting serious about implementation this week.

WIP https://github.com/74th/qmk_firmware_sparrow_keyboard/blob/sparrow/keyboards/sparrow62/rev2/matrix.c

74th, 2024-08-16:
@azhizhinov
Sorry for the wait.
We have added support for QMK Firmware and VIA (REMAP).
We would be happy if you could try using them if you like.

https://github.com/74th/sparrow62-buildguide/blob/master/sparrow62_v2.md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

https://github.com/74th/qmk_firmware_sparrow_keyboard/tree/sparrow/keyboards/sparrow62/rev2

https://github.com/74th/qmk_firmware_sparrow_keyboard/wiki

azhizhinov, 2024-08-17:
Hello.
Thank you a lot.
It's working. At first, I've checked only with the left half and no output from the keyboard had been received. In the QMK console were string with tries to connect to the MCP23017 and I've assumed the right half should be connected.
I have to confess, I've recreated your keyboard from scratch. :-)
Here the [KiCAD](https://github.com/user-attachments/files/16646052/20240817.AZHIZHINOV.SPROW63.00.zip) project and [models](https://github.com/user-attachments/files/16646063/20240817.AZHIZHINOV.SPROW63.00.zip) for FDM printers.
By the way, is there any possibility to change the firmware to work only with the left half connected? If so, that will be great.
Thank you and good luck.

Closed 2024-08-16.

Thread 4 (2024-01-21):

Readme.mdで表示されていない画像

imamurayusuke, 2024-01-21:
こんにちは、プルリクエストを出す方法がわからずissueで失礼します。

34行目と35行目
img/top_choc.jpg→img/v1/top_choc.jpg
img/top_choc2.jpg→img/v1/top_choc2.jpg

150行目
img/choc_v2.jpg→img/v1/choc_v2.jpg

これで画像が表示されると思います。ご確認くださいませ。

74th, 2024-01-25:
ご指摘ありがとうございます！助かります。

修正させていただきました。

Closed 2024-01-25.

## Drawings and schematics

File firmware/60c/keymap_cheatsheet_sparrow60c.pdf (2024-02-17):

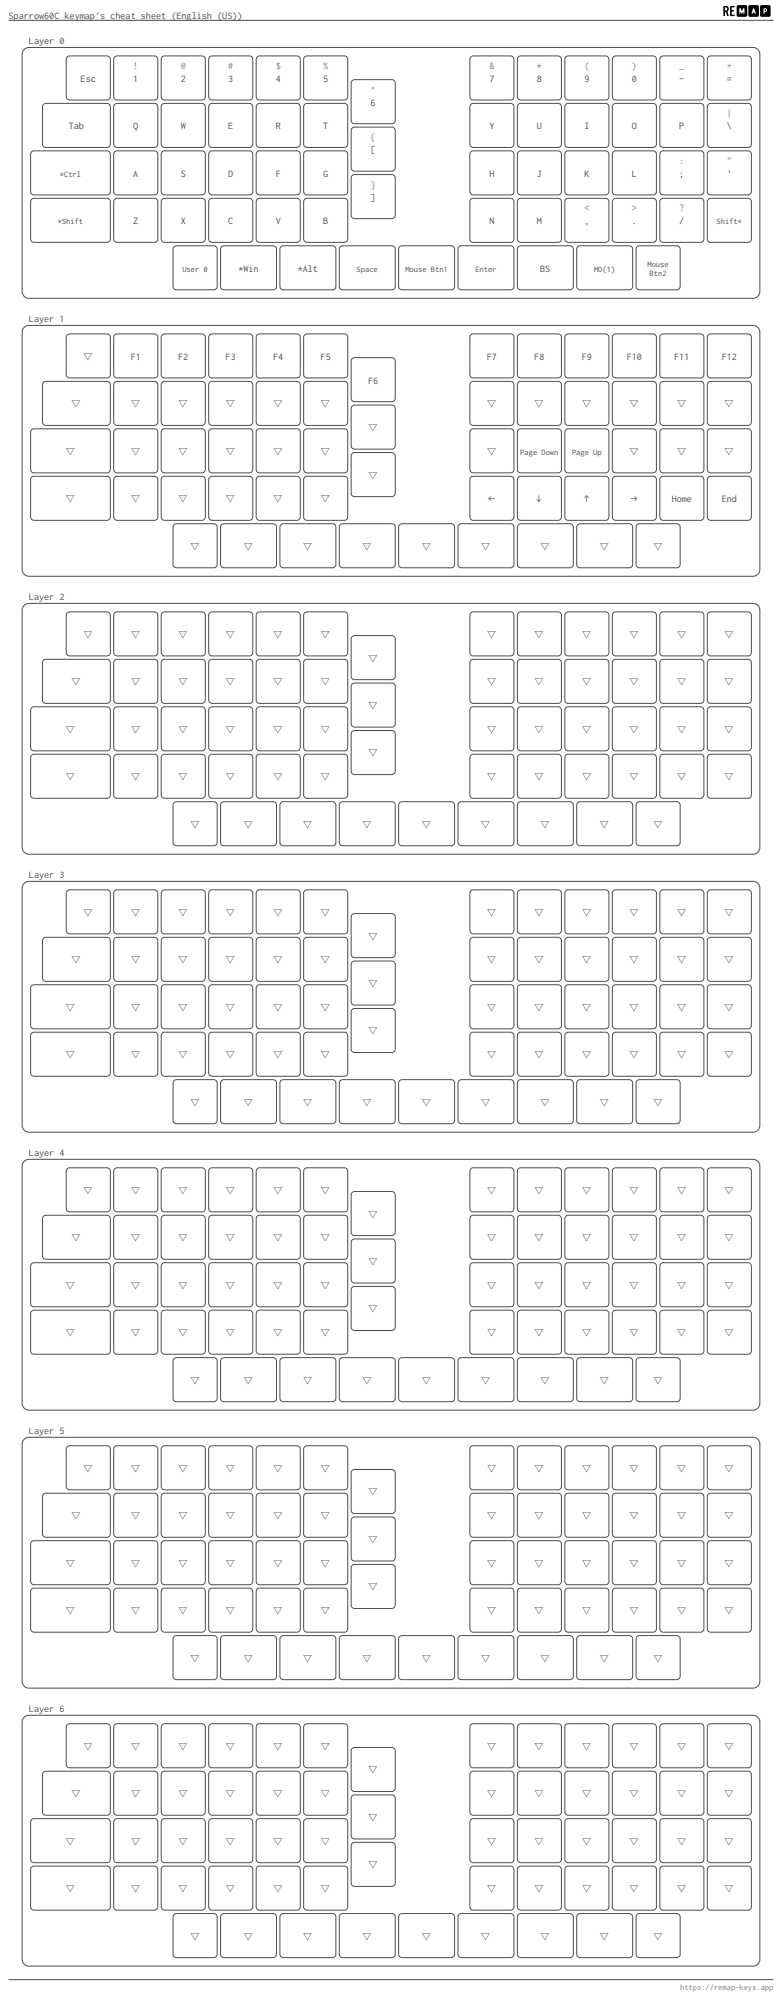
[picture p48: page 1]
Layer 0; Esc; Tab; *Ctrl; *Shift; Shift*; User 0; *Win; *Alt; Space; Mouse Btn1; Enter; Mouse; Btn2; Layer 1; Page Down; Page Up; Home; End; Layer 2; Layer 3; Layer 4; Layer 5; Layer 6

Sparrow60C keymap's cheat sheet (English (US))

https://remap-keys.app

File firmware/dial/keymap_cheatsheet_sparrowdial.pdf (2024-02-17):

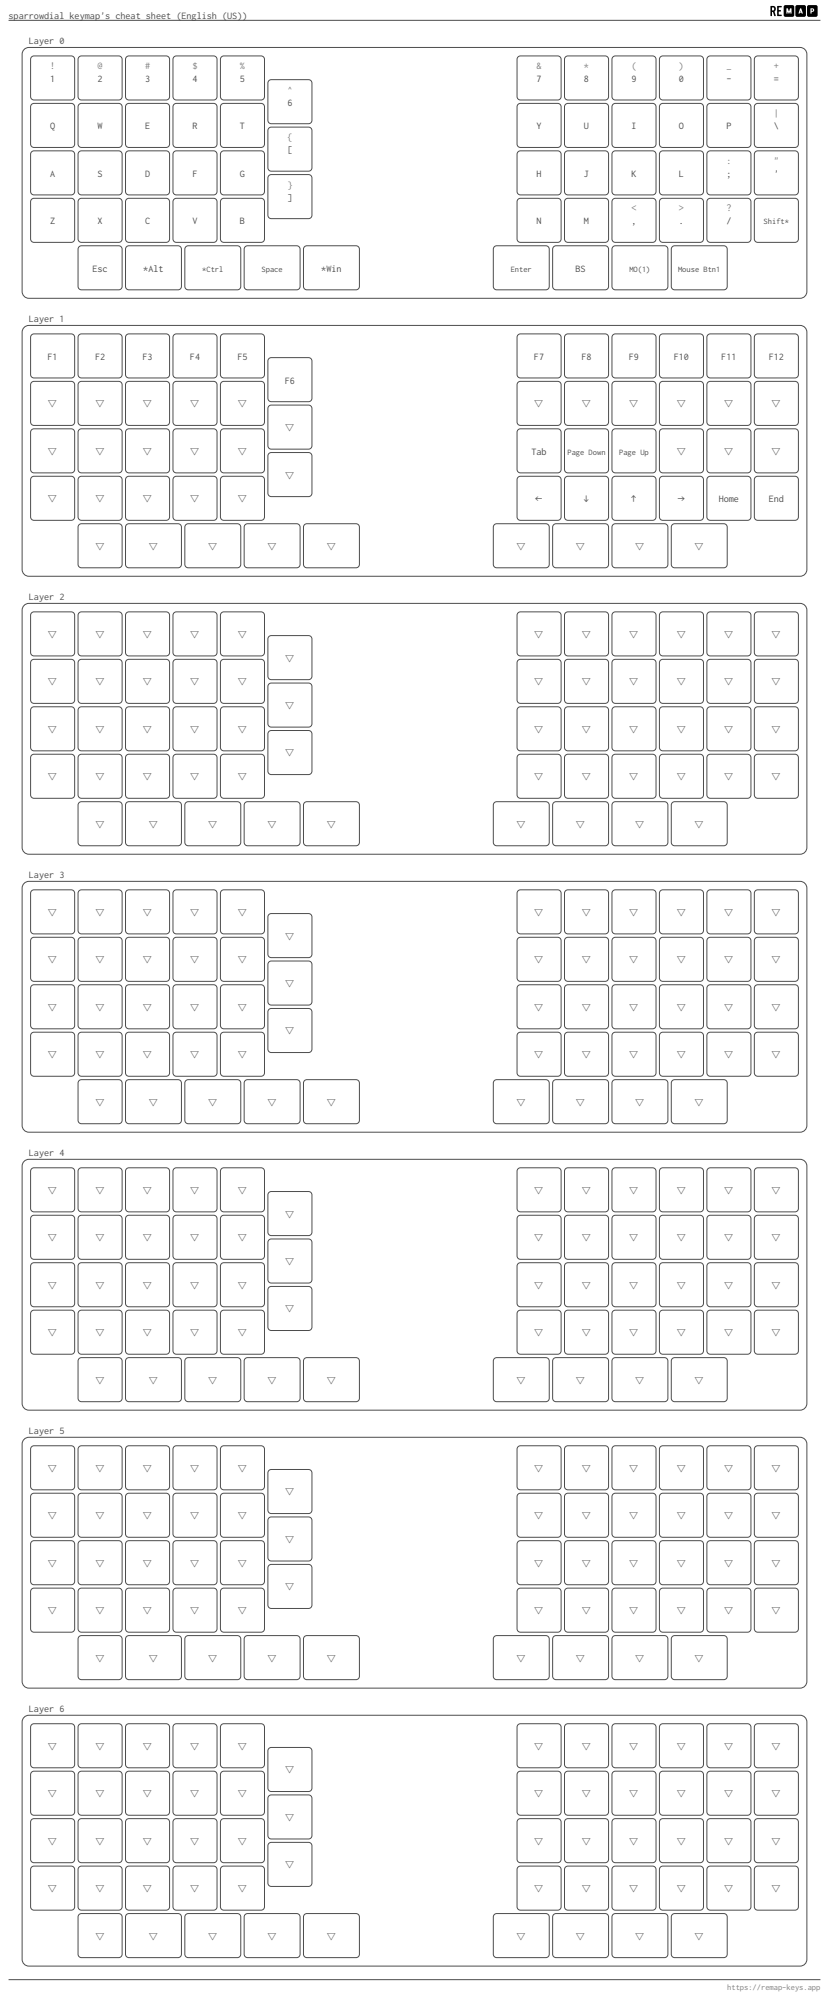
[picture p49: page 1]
Layer 0; Shift*; Esc; *Alt; *Ctrl; Space; *Win; Enter; Mouse Btn1; Layer 1; Tab; Page Down; Page Up; Home; End; Layer 2; Layer 3; Layer 4; Layer 5; Layer 6

sparrowdial keymap's cheat sheet (English (US))

https://remap-keys.app

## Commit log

2020-10-25 高さ調整ガイド
2021-01-11 QMK Firmwareにマージされた
2021-07-07 update screw 6mm
2022-05-03 Update README.md
    スタビライザの必要数を修正
2024-02-12 add esp32 uploader
2025-03-05 ケースデータ
    [left-case-main-choc.stl, left-case-main-mx.stl, left-case-top-lower.stl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]
2025-03-20 SparrowS v3ビルドガイドを更新し、右手追加4キーパッドの組み立て方法を追加。スイッチソケットの実装方法を修正し、関連画像を追加。
2025-03-21 SparrowS v3ビルドガイドを更新し、追加4キーパッドに必要な部品リストを詳細化。スタビライザーの使用方法を明記し、関連リンクを追加。
2025-03-21 SparrowS v3ビルドガイドを更新し、右手追加4キーパッドのキット同梱品セクションを追加。必要な物のリンクを修正。
2025-03-21 SparrowS v3ビルドガイドを更新し、スイッチ対応キーキャップの説明を簡略化。必要なキーキャップの種類を修正。
2025-03-21 LEDを少し眩しくないやつに
2025-03-23 README.mdにインサートナットの情報を追加
2025-03-23 SparrowS v3ビルドガイドを更新し、同梱品購入先のリンクを追加。汎用SH1.0ケーブルの注意事項を明記し、インサートナットの情報を追加。
2025-03-30 SparrowS v3ビルドガイドを更新し、スイッチの取り付け手順を明確化。Chocスイッチの取り付けに関する画像を追加。
2025-05-16 右手用キーボードと追加4キーパッドのファームウェアに関する情報を追加
